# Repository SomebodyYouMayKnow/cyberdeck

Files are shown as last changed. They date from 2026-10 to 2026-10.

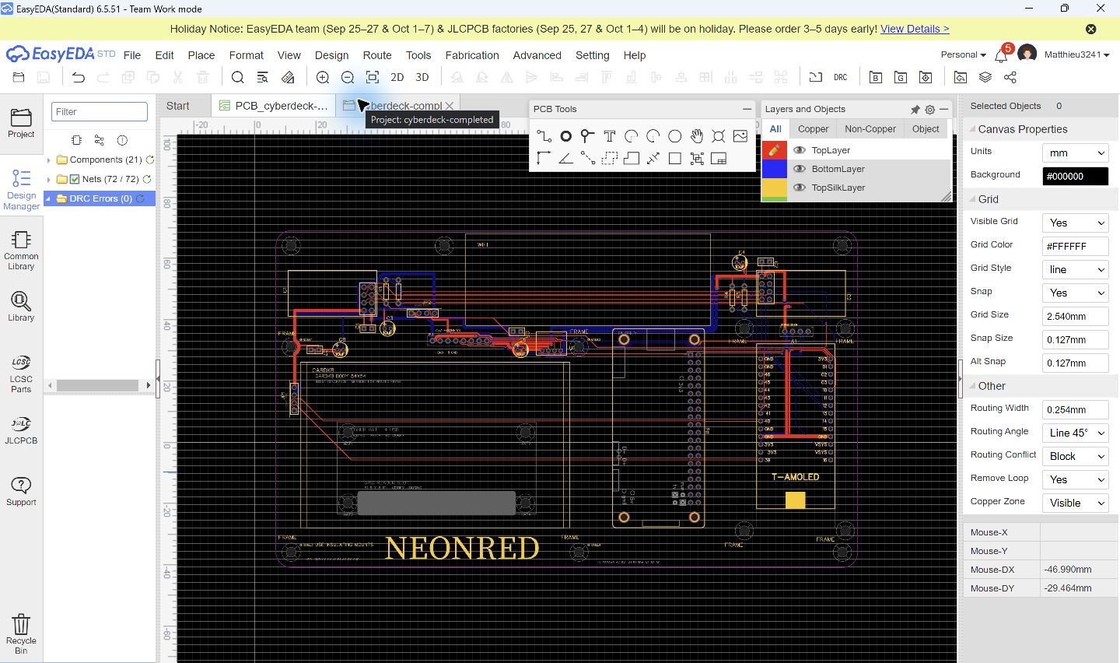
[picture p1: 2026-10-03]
PCB/screenshots/easyeda-current-routed-board-drc.jpg

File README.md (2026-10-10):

# NEONRED

NEONRED is a compact, modular cyberdeck built around a Raspberry Pi Zero 2 W and a LILYGO T-Display-S3 AMOLED. The Pi runs Linux and hosts USB peripherals through the Waveshare USB HUB HAT. The LILYGO board provides the ESP32-S3 control interface and its own AMOLED display. **The current design has no separate HDMI display.**

## Planned capabilities

- Portable Linux development and an on-device ESP32 control interface.
- CardKB keyboard, rotary encoder and navigation buttons.
- IR receive/transmit hardware and two nRF24L01+ modules for controlled lab experiments.
- Chameleon Ultra SE3 for testing owned RFID/NFC tags and lab cards.
- ALFA dual-band Wi-Fi adapter for authorized testing on owned or explicitly authorized networks.
- Proxmark3 RDV4 as a separately mounted USB instrument, with its own LF/HF antenna system; it is not a bare IC to solder onto the carrier PCB.
- RTL-SDR Blog V4 as a USB receive-only SDR. The radar-detector experiment needs external X/K/Ka downconverters because the V4 cannot tune directly to those radar frequencies.
- ESP32 firmware experiments: the project’s control UI, passive Flock You detection, and ESP32 Marauder are separate firmware modes. They cannot all run simultaneously on one ESP32, and support for this exact LILYGO board must be validated.
- A switchable 2.4 GHz external antenna for the ESP32, conditional on confirming the exact LILYGO revision has an antenna-feed option.

Radio work is for the user's own equipment and explicitly authorized environments. Keep Wi-Fi testing non-disruptive and do not interfere with or access other people's networks or devices.

## Design status

The EasyEDA files in `PCB/` are saved design-stage exports, not a fabrication release. The new radio additions need mechanical outlines, serviceable USB connections, antenna clearances, and a power/thermal check. The exact Proxmark3 model, RTL-SDR supply, LILYGO revision, and antenna-feed option are not yet verified. See [the current feature and integration plan](docs/NEONRED_FINAL_VERSION_2026-10-09.md).

Existing project files include source exports, wiring notes, screenshots, firmware scaffolding, and CAD/layout artifacts. Treat older HDMI-specific and superseded power documents as historical until reconciled with the live EasyEDA project.

## Useful files

- [Current goal and integration plan](docs/NEONRED_FINAL_VERSION_2026-10-09.md)
- [PCB source and screenshots](PCB/)
- [Firmware scaffold](Firmware/)
- [CAD files](cad/)
- [Current master BOM/status list](BOM.csv)
- [Earlier dated purchase list](BOM_NEONRED_purchase-list_2026-10-06.csv; historical until reconciled)
- [Detailed project notes](docs/PROJECT_SUMMARY.md)

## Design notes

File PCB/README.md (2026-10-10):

# PCB sources

The current project goal is documented in [NEONRED_FINAL_VERSION_2026-10-09.md](../docs/NEONRED_FINAL_VERSION_2026-10-09.md): **no separate HDMI display**, with proposed Proxmark3, RTL-SDR, ESP32 firmware modes and a conditional external ESP32 antenna. On 2026-10-09, the live EasyEDA Standard project `neonred` was opened and its current `Sheet_1` and `PCB_neonred` exported below. These are baseline snapshots only: the proposed Proxmark3/RTL-SDR/antenna expansion has not been laid out, and this is not a fabrication release. Older simple-power and port-revision sources are design history, not approval to fabricate.

- `neonred-live-schematic_2026-10-09.json` and `neonred-live-PCB_2026-10-09.json` — source exports from the live EasyEDA Standard project.
- `screenshots/easyeda-neonred-schematic-2026-10-09.png` and `screenshots/easyeda-neonred-pcb-2026-10-09.png` — matching visual exports.

- `pcb-simple-power-native.json` — saved EasyEDA PCB source
- `schematic-simple-power-native.json` — saved EasyEDA schematic source
- `wiring-map-simple-power.*` — connector and pin-assignment record
- `simple-power-native-drc.json` — saved DRC record; the corresponding EasyEDA screenshot shows 0 displayed DRC errors for that point-in-time revision
- `simple-power-mounting-template.pdf` — 1:1 mechanical-fit print template
- `screenshots/` — live project image exports plus earlier design-stage views and mounting-template preview

The source and screenshots document the design stage; they do not prove physical fit, assembly, or electrical operation. There is no final Gerber archive. Before fabrication, measure the real hardware, complete final DRC/ERC in the PCB tool, and add `production/gerbers.zip`.

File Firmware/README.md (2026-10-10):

# Cyberdeck firmware

This folder is an **untested pre-hardware bring-up scaffold**. The 2026-10-06 master-power / service-port redesign is documented in [POWER_AND_IO_REVISION_2026-10-06.md](../docs/POWER_AND_IO_REVISION_2026-10-06.md) but has not yet been applied to the EasyEDA schematic or PCB. Do not follow the earlier simple-power wiring notes as the new design.

- `esp32/` is a PlatformIO Arduino project for the LILYGO ESP32-S3 AMOLED board.
- `pi/` reads the ESP32 USB serial link and sends console commands back.
- `PROTOCOL.md` documents the line-based command protocol.

## Bring-up order

1. Confirm the actual hardware revisions and the carrier PCB against the saved wiring map.
2. Do not connect the proposed single-input power system until its source, protection, and PCB have been measured and verified. The currently listed Miady bank does not meet the revised one-input power requirement.
3. Flash `Firmware/esp32` with PlatformIO.
4. On the Pi, install `pyserial` and run `python3 cyberdeck_bridge.py --port /dev/ttyACM0`.
5. Send `STATUS` first. Verify I²C devices, radios and IR one subsystem at a time.

Do not operate direct SPI/IR/I²C signal connections when the related domain is unpowered. Begin radios at minimum power and measure the external regulator load and temperature before normal use.

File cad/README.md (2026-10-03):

# CAD sources

These files are copied from the active design folder for publication:

- `Cyberdeck_Enclosure.scad` is the editable parametric enclosure concept.
- `Cyberdeck_Fusion_Layout.dxf` is the millimetre placement sketch for Fusion.
- `Cyberdeck_layout.svg` is a visual layout reference.
- `MECHANICAL_VALIDATION.md` lists source dimensions and physical tests.

There is no final STEP assembly yet. Do not represent these sources as a fit-tested enclosure.

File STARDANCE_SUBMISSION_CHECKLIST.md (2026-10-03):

# Stardance funding and shipping checklist — Cyberdeck

**Status snapshot:** 2026-10-03. This separates the funding request from the physical build. Funding is requested from a complete design package before parts are bought. Shipping/Stardust comes after the physical device is assembled.

## Phase 1 — create the Stardance project and record work

- [ ] Create or sign in to a Stardance account. You must be eligible for the program and complete the account details yourself.
- [ ] Create a new **Hardware** project on Stardance and set its title, short description, and public GitHub source URL.
- [ ] Start Lapse before continuing design work, or create a Markdown build journal if Lapse is unavailable.
- [ ] Add design devlogs that explain your own decisions, revisions, problems, and next steps.
- [ ] Ask for feedback in `#stardance-help` or from other makers and record the feedback plus changes made.

## Phase 2 — funding-request design package

### Already done

- [x] Public GitHub repository: https://github.com/SomebodyYouMayKnow/cyberdeck
- [x] Commit and publish the core design package on GitHub.
- [x] Organize the repository into `cad/`, `PCB/`, `Firmware/`, `production/`, and `docs/`.
- [x] Publish a linked root `BOM.csv` and the BOM workbook.
- [x] Publish the current PCB source, schematic source, wiring map, DRC evidence, and 1:1 mounting template.
- [x] Publish editable OpenSCAD enclosure source, Fusion-importable DXF, layout SVG, and mechanical-validation document.
- [x] Publish untested starter firmware: ESP32 pin-map/I2C/radio/IR code, Pi serial bridge, and Chameleon BLE discovery scaffold.
- [x] Add a license and `.gitignore`.

### Still needed before clicking **Request funding**

- [ ] Finish the enclosure as a detailed, electronics-inclusive CAD assembly. It needs the case, lid, display, keyboard, Pi, USB HAT, ESP32, Chameleon, battery, carrier PCB, cables, screws/standoffs, antenna arms, and openings positioned in one assembly.
- [ ] Save the editable Fusion source file, such as `assembled-cyberdeck.f3d`.
- [ ] Export the full assembly as `assembled-cyberdeck.step`. Stardance says a funding submission without an electronics-inclusive STEP file will not be approved.
- [ ] Export the individual printable case parts as STEP/STL where relevant.
- [ ] Use accurate component envelopes or manufacturer STEP models in the CAD assembly. Mark dimensions that still need physical checking.
- [ ] Take screenshots/renders of the **digital** full CAD assembly. These are required for review; they are not photos of a completed physical build.
- [ ] Take a screenshot of the PCB layout and a schematic/wiring-diagram image from the current files.
- [ ] Write the final root `README.md` yourself. Stardance explicitly does not allow an AI-generated README.
- [ ] In your README, add: what the project is; why you are making it; subsystem explanation; CAD render; PCB screenshot; wiring diagram; how to reproduce it; and the BOM table.
- [ ] Confirm every BOM line has the correct quantity, price or clearly marked TBD status, and a purchase link.
- [ ] Keep the current firmware source in the repository. It may be untested for funding, but it must be present.
- [ ] Choose a funding tier in Stardance. The reviewer can move it up or down. Current published limits are B up to $25, A up to $120, S up to $200, and X up to $600 case-by-case.
- [ ] From the Stardance project page, click **Request funding** and submit the public repository link after the items above are present.

## Do **not** require these before funding

- [x] You do not need to buy the requested parts first.
- [x] You do not need to 3D-print the enclosure first.
- [x] You do not need to fabricate the PCB first.
- [x] You do not need physical build photos before requesting funding.
- [x] You do not need successful hardware tests before requesting funding. Firmware can be untested.

## Phase 3 — after funding and parts arrive

- [ ] Confirm exact part revisions and measure all physical modules, connectors, cable bends, and screw locations.
- [ ] Print the 1:1 template and check its 100 mm calibration line.
- [ ] Test-fit the Pi, HAT header slot, keyboard, ESP32, display, Chameleon, battery, cables, antennas, and all mounts before final fabrication.
- [ ] Correct the CAD and PCB from physical measurements; rerun final DRC/ERC.
- [ ] Export final Gerbers and drill files as `production/gerbers.zip` before ordering the carrier PCB.
- [ ] Print the case, assemble the carrier PCB, mount the modules, and add insulation/strain relief.
- [ ] Flash and test the ESP32/Pi firmware one subsystem at a time: keyboard, encoder, radios, IR, display, USB HAT, Wi-Fi, and Chameleon BLE discovery.
- [ ] Update the repository with the final CAD/STEP, Gerbers, firmware changes, wiring photos, and build notes.

## Phase 4 — ship the completed project for Stardust

- [ ] Add real photos or a video showing the completed cyberdeck and its working functions.
- [ ] Update the README with build photos, measured changes, and tested behavior.
- [ ] Ship the completed project from the Stardance project page. This sends it to review for Stardust, separate from the funding request.

## Current funding blockers

1. A Stardance account/project and work log need to be created by you.
2. The CAD is still a parametric concept; it needs a complete Fusion assembly and an electronics-inclusive STEP export.
3. The final README must be written by you and include digital renders/screenshots.
4. Feedback must be requested and documented.

Sources: [Stardance hardware shipping guide](https://stardance.hackclub.com/resources/shipping-hardware), [starting-hardware guide](https://stardance.hackclub.com/resources/starting-hardware), and [hardware funding tiers](https://stardance.hackclub.com/resources/tiers).

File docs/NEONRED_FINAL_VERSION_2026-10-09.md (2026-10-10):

# NEONRED — current goal and hardware expansion

Updated: 2026-10-09. This note is the current high-level target and supersedes the older HDMI-based project descriptions. On 2026-10-09, I opened the live EasyEDA Standard `neonred` project and exported its current schematic and PCB to `PCB/neonred-live-schematic_2026-10-09.json` and `PCB/neonred-live-PCB_2026-10-09.json`, with PNG views in `PCB/screenshots/`. The requested Proxmark3/RTL-SDR/antenna expansion has **not** been laid out; these are baseline exports, not an updated fabrication design.

## Final version description

NEONRED is a portable, modular cyberdeck and authorized electronics/security-learning workbench built around a Raspberry Pi Zero 2 W and a LILYGO T-Display-S3 AMOLED. The Pi runs Linux and connects to the Waveshare USB HUB HAT. The LILYGO board supplies the ESP32-S3 control interface and its integrated AMOLED screen. The current version has **no separate HDMI display**.

The device combines a CardKB keyboard, rotary encoder and navigation controls with IR receive/transmit hardware, two nRF24L01+ modules, the Chameleon Ultra SE3, and an ALFA USB Wi-Fi adapter. The proposed expansion adds a separately mounted Proxmark3 instrument and an RTL-SDR Blog V4 receiver, plus an external 2.4 GHz antenna for the ESP32 if the exact LILYGO board revision supports a switchable RF feed. Modules with USB or antenna connections remain replaceable serviceable devices; the carrier PCB provides mounting and correctly routed interfaces, rather than copying complete complex RF products onto the carrier.

Software modes under consideration are the NEONRED control firmware, passive Flock You detection, and ESP32 Marauder experimentation in an isolated, authorized lab. These are not simultaneous capabilities on one ESP32: each firmware image replaces the others unless a separate ESP32 is added and independently supported. The exact LILYGO display/board support for Marauder and Flock You requires a port and bench test before it can be claimed as working.

## What can physically go on the PCB

| Addition | Practical integration | Open issue |
|---|---|---|
| Proxmark3 | Mount a complete Proxmark3 RDV4 or other selected assembled unit as a removable USB module. Provide a retainer, accessible USB connection, and room for its LF/HF antenna loops. | “Proxmark3” has multiple hardware variants. Select the exact unit and measure it. Do not replace it with an unverified home-designed RF clone. Keep its loop antennas clear of metal and other coils. |
| RTL-SDR Blog V4 | Mount the intact USB-A dongle at the Pi USB hub; reserve a 50-ohm SMA feedthrough/pigtail and antenna clearance. Leave airflow around its metal enclosure. | The V4 is a receive-only USB dongle, 500 kHz–1.766 GHz, 250–270 mA typical, with USB-A male and SMA. It cannot directly receive X/K/Ka police-radar bands. The linked detector software describes external block downconverters; select and validate those separately. Its manufacturer has announced the V4 end of life, so confirm availability before listing it as a guaranteed purchase. |
| ESP32 external antenna | Reserve a mechanically accessible antenna connector and keepout only after confirming an RF feed point and selector on the exact owned LILYGO revision. If that board has no documented external-antenna option, use the onboard antenna or a different ESP32-S3 module with a factory u.FL/IPEX connector. | The ESP32-S3 is 2.4 GHz Wi-Fi/Bluetooth; it does not provide 5 GHz Wi-Fi. The vendor documentation for a different T-Display-S3 board describes moving an RF-selection resistor, but that must not be copied to the AMOLED board without its exact schematic and visual inspection. |
| Flock You | Treat as a separate, receive-only firmware experiment; the referenced project describes passive 2.4 GHz Wi-Fi frame detection. | Its published default target is a Seeed XIAO ESP32-S3. Porting the display/buttons and validating the exact LILYGO board is still required. |
| ESP32 Marauder | Treat as a separate firmware mode on a compatible ESP32 target, used only in an isolated lab on owned or explicitly authorized systems. | The current LILYGO T-Display-S3 AMOLED is not listed as a ready-made target in the upstream compatibility table. Display, buttons, flash layout and GPIO assignments must be ported and tested. It cannot run alongside NEONRED UI or Flock You on the same chip at the same time. |

The RTL-SDR V4’s SMA connector is an RF input, not a connector to solder directly to GPIO or a PCB antenna trace. The Proxmark device likewise has dedicated LF/HF antenna circuits; preserve the complete selected device and its correct antenna arrangement. Any coaxial feedthroughs should be 50-ohm RF connectors appropriate to the chosen device, and must be isolated from mounting metal where the antenna design requires it.

## Power and performance checks

The V4’s published typical current is 250–270 mA; the ALFA adapter, HAT, Proxmark and Pi add to the system load. The Raspberry Pi Zero 2 W is specified around a 5 V / 2.5 A supply recommendation. The Waveshare hub adds ports, not unlimited power. Bench-test the complete load from the selected source and hub before assuming one bank can run all modules. Keep the SDR’s software-controlled bias tee disabled unless the selected antenna accessory explicitly needs it. Do not connect independent USB VBUS outputs together or route unmeasured high-current device power through narrow carrier traces.

The linked radar detector project describes an SDR plus external downconverters to translate radar-frequency signals into the V4’s tunable range. This is a substantial, separate RF subsystem, not a firmware-only feature. The proposed use here is passive reception and alerts; no radar transmission or interference is part of this design.

## Authorized scope

- Linux development, programming, diagnostics, and hardware bring-up.
- IR learning/testing on the user's own remotes.
- NFC/RFID experiments using tags, cards and systems the user owns or has explicit permission to test.
- Wi-Fi, Bluetooth and nRF24 experiments on owned equipment or in an isolated authorized lab. No disrupting other people's networks or radio communications.
- Passive reception for the proposed SDR detector and passive Flock You experiment, subject to local law.
- Physical integration of serviceable off-the-shelf modules, custom PCB design, enclosure CAD, firmware and documentation.

## Required before changing/fabricating the PCB

1. Use the live EasyEDA exports as the starting baseline. After the mechanical and electrical choices below are verified, update the project and export a new schematic, PCB source, and screenshots to `PCB/`.
2. Confirm the exact LILYGO model/revision and inspect its manufacturer schematic for an external antenna selector/feed. Do not add a connector footprint based only on the standard T-Display-S3 instructions.
3. Choose the exact Proxmark3 hardware and RTL-SDR V4 (or an available equivalent); obtain their dimensions, mounting points, connector positions and antenna clearances.
4. Decide whether the Pi Zero 2 W has enough CPU and USB power headroom for one SDR, the ALFA adapter and the other peripherals. Test incrementally; the software's advertised support is not a performance guarantee for this deck.
5. Choose the radar-band downconverter set and antenna arrangement, then verify its output frequencies stay inside the selected SDR's tuning range.
6. Allocate separate, replaceable mounts and USB paths for the Proxmark and RTL-SDR. Avoid routing high-speed USB over long unshielded PCB traces; use short controlled connections or certified cables.
7. Update schematic, PCB footprints, board outline/keepouts, mounting template, current budget, BOM and screenshots together. Run ERC/DRC and check the physical assemblies before calling the PCB fabrication-ready.

## References

- [Proxmark3 RDV4 product/hardware overview](https://proxmark.com/proxmark-3-hardware/proxmark-3-rdv4/) and [Proxmark3 hardware description](https://github.com/Proxmark/proxmark3/wiki/Hardware-Description)
- [RTL-SDR Blog V4 datasheet](https://www.rtl-sdr.com/wp-content/uploads/2024/12/RTLSDR_V4_Datasheet_V_1_0.pdf) and [V4 end-of-life notice](https://www.rtl-sdr.com/rtl-sdr-blog-v4-end-of-line/)
- [Requested radar-detector project](https://github.com/rayhe/sdr-radar-detector)
- [LILYGO AMOLED series hardware and pinout sources](https://github.com/Xinyuan-LilyGO/LilyGo-AMOLED-Series)
- [ESP32 Marauder supported hardware](https://github.com/justcallmekoko/ESP32Marauder/wiki/supported-hardware) and [FAQ](https://github.com/justcallmekoko/ESP32Marauder/wiki/faq)
- [Flock You project](https://github.com/colonelpanichacks/flock-you)

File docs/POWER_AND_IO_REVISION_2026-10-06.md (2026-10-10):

# NEONRED power, controls, and service-port revision

Updated: 2026-10-06. This is the current requested architecture for the next schematic/PCB revision. It supersedes the earlier “separate USB power cables / peripheral-only switch” proposal in `PROJECT_SUMMARY.md`. This is an electrical design draft, not a fabrication release.

## Requested interfaces

- One latching master switch controls the complete deck power distribution.
- One external USB-C female port is the 5 V system-power input.
- One external USB-C female port carries native USB data for ESP32-S3 programming/control.
- One external micro-USB female port provides access to the Pi Zero 2 W OTG/data connector.
- Add two momentary through-hole controls: Back and Menu. Keep the rotary encoder for scrolling and its push contact for Select.
- Replace the Adafruit #5990 plug-in IR board with its receive/transmit functions on the carrier PCB; place the IR receiver and two emitters at the left wall aperture, on short leads only if needed for optical alignment.

## Power-path intent

`USB-C power input → 5 V-only sink/PD interface → input protection → master switch → protected branches`.

The switched 5 V branches are: Pi PWR IN, LILYGO 5 V/VBUS input, HDMI display (only if its exact revision uses 5 V), and the peripheral regulator input. The regulator supplies the nRF24 modules and IR transmit stage at 3.3 V. CardKB is supplied at 5 V through its existing level-shifter arrangement. Grounds are common. Do not connect independent USB VBUS sources together.

The input must negotiate or otherwise provide 5 V at the measured total load. If USB-PD is used, the sink must request a 5 V profile; do not feed a 9/12/15/20 V profile directly to the 5 V rails. Place a fuse/current-limiting stage immediately after the input. Size the fuse, switch, connector, copper, and each branch from measured peak currents and the weakest cable/connector; values are deliberately TBD until those measurements and exact module revisions are known. The source's maximum rating limits available current, while a fuse protects against faults. Never treat a wide trace as overcurrent protection.

The currently listed Miady two-pack bank is not suitable as the single source for this proposed architecture: its published output is up to 5 V/2.4 A, while Raspberry Pi recommends a 5 V/2.5 A supply for Zero-series boards, before the HDMI display, LILYGO, HAT peripherals, radios, and IR are counted. Use a higher-capacity source for one-input operation or retain electrically isolated separate sources; do not pretend the existing bank has enough headroom.

The master switch must interrupt the system 5 V after input protection and before every load branch. Its OFF position must also prevent the ESP32 programming cable or Pi service cable from back-powering system rails. The computer USB-C VBUS is therefore isolated from system 5 V; retain only a correctly isolated VBUS-detect path if the LILYGO native USB implementation requires it. Verify enumeration with the exact LILYGO revision before PCB release.

This is a hard power cut, not a graceful Pi shutdown. Until a proper shutdown controller is designed and tested, shut Linux down first and then use the master switch; cutting power during SD-card writes can corrupt the Pi boot card.

## USB service paths

- **ESP32 USB-C:** Use the LILYGO's native USB 2.0 D+/D− path, brought to a panel female connector. Keep the data pair together and short; ground the shield to chassis at the entry. The computer's VBUS must not become an alternate source for the switched 5 V bus.
- **Pi micro-USB:** Treat the requested panel jack as the Pi's OTG/data service connection. Pi power remains on the switched 5 V rail through the separate PWR IN connector. The Pi OTG port is already used by the Waveshare four-port USB HUB HAT, so add a break-before-make 2:1 USB 2.0 selector labelled `HAT / PC`. It must route only one upstream connection to the Pi at a time, prevent VBUS backfeed, and preserve the correct OTG host/device role. The external PC service mode may require Pi USB-gadget configuration. Do not wire the HAT and external computer in parallel.
- **Power USB-C:** This is the only system-power entry. It requires a correctly wired USB-C sink interface/CC termination (or a preassembled sink module) and input protection. A bare USB-C receptacle with only VBUS/GND wires is not a complete C-to-C sink.

## Controls and IR

Button assignments for the next firmware/hardware revision:

| Control | ESP32 pin | Wiring |
| --- | --- | --- |
| Back | GPIO43 | Normally-open switch to GND; internal pull-up |
| Menu | GPIO44 | Normally-open switch to GND; internal pull-up |
| Select | GPIO42 | Existing rotary encoder push contact to GND; internal pull-up |
| Navigate | Existing encoder A/B | Keep current assignments |

This gives the screen UI Back, Menu, Select, and rotary navigation. GPIO43/44 are also the LILYGO UART0 pins, so the native USB CDC connection is used for the programming/service port; do not use UART0 at the same time. The current firmware can report button events over USB serial; drawing a menu on the AMOLED still requires the exact display-driver initialization for the owned LILYGO revision.

The integrated IR block keeps `IR_RX` on GPIO39 and `IR_TX` on GPIO40. The receive sensor is a 38 kHz demodulating device. The transmit LEDs need a transistor/FET driver and current-limiting designed for the measured supply; do not drive them directly from a GPIO. The Adafruit #5990 board draws up to about 400 mA while transmitting from 5 V, so the carrier's 3.3 V regulator and switch must be sized from the actual implementation's pulse current. If reproducing Adafruit's circuit, retain the required attribution/share-alike notice in the project files.

## What is changed now vs. what still blocks fabrication

The firmware pin definitions and USB-serial button event handling are updated for Back/Menu, and the BOM now lists the required design items with unresolved ratings. The wiring map, PCB footprints, copper routes, port selector schematic, and IR discrete circuit are **not yet changed or verified**. They must be updated together in EasyEDA after identifying exact connector modules and measuring the complete 5 V load. This avoids silently treating a planning block diagram as a wired, current-rated PCB.

Before releasing fabrication files, verify: exact LILYGO USB-C/VBUS behavior; Pi OTG and HAT upstream wiring/role; the selected 2:1 selector's VBUS/ID behavior; USB-C sink module output; measured peak current for Pi, hub devices, display, ESP32, radios and IR; switch/fuse/copper ratings; connector pinouts; and physical fit of the three panel ports and the added buttons.

## References

- [Raspberry Pi Zero 2 W product page](https://www.raspberrypi.com/products/raspberry-pi-zero-2-w/) — distinguishes the OTG micro-USB port from the separate power input.
- [Raspberry Pi power guidance](https://www.raspberrypi.com/documentation/computers/getting-started.html) — recommends 5 V / 2.5 A for Pi Zero boards.
- [Raspberry Pi USB gadget-mode guide](https://www.raspberrypi.com/news/usb-gadget-mode-ssh-over-usb/) — gadget connection uses the Zero's OTG port, not PWR IN.
- [Waveshare USB HUB HAT](https://www.waveshare.com/wiki/USB_HUB_HAT) — HAT uses the Pi Zero USB connection for its upstream data link.
- [Adafruit #5990 open hardware source](https://github.com/adafruit/Adafruit-Infrared-IR-Remote-Transceiver) — reference design, operating notes, and license.
- [Miady 2-pack listing specification](https://www.newegg.com/p/359-04A3-00191) — lists the bank's maximum output as 5 V / 2.4 A.

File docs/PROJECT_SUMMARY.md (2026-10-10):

# Cyberdeck project summary

Updated: **2026-10-09** (America/Los_Angeles). The current goal is recorded in [NEONRED_FINAL_VERSION_2026-10-09.md](NEONRED_FINAL_VERSION_2026-10-09.md). It supersedes the older HDMI-based description below: the current version has **no separate HDMI display**, and proposes a removable Proxmark3 instrument, one RTL-SDR Blog V4 with external radar-band downconverters, passive Flock You experimentation, a separately flashed ESP32 Marauder mode, and an external ESP32 antenna only if the exact LILYGO revision supports it. These additions are not yet reflected in the saved EasyEDA project or verified on hardware. Sections below preserve prior design history; where they conflict with the new goal, treat them as historical rather than fabrication instructions. The live EasyEDA editor was not available in the computer session, so no new EasyEDA screenshot, schematic, PCB, or DRC claim is made.

The earlier revision's specific power arrangement below is historical and is **not the current requested design**. Retain its electrical notes only as record of the previous revision.

## Final project vision and inspiration

**NEONRED** is intended to become a compact, repairable clamshell cyberdeck: a portable Linux computer and electronics workbench that the user designs, builds, programs, and documents from the carrier PCB through the finished 3D-printed case. The Raspberry Pi Zero 2 W is the main Linux computer and drives the HDMI display. The LILYGO ESP32-S3 AMOLED is the always-available control interface for the CardKB keyboard, rotary encoder, IR hardware, and low-power radio modules. A separately mounted Waveshare USB HUB HAT expands the Pi, while the Chameleon Ultra SE3, ALFA dual-band Wi-Fi adapter, display, battery bank, and folding-antenna arrangement make the finished unit self-contained.

The intended final form is a laptop-like case: keyboard in the base; Pi, HAT, Chameleon, and protected wiring below it; an HDMI display in the lid; and a lid window that exposes the base-mounted LILYGO display when the deck is closed. It should be maintainable, with screws, standoffs, service access, cable routing, and replaceable modules rather than permanently buried parts.

### Intended, authorized uses

- Linux development, portable programming, diagnostics, and display/keyboard experimentation.
- ESP32 firmware development; I2C keyboard and encoder control; IR learning and replay for the user's own remotes.
- NFC/RFID work with the user's own tags, cards, and lab equipment through the Chameleon.
- Wi-Fi, Bluetooth, and nRF24 experimentation limited to the user's own equipment, networks, or an authorized test environment; the project must not interfere with other people's radio communications or networks.
- Learning the complete hardware-development cycle: circuit and PCB design, enclosure CAD, 3D printing, embedded firmware, Linux integration, wiring, physical assembly, debugging, and documentation.

### Recovered inspiration record

The earlier wiring chat records that the user shared **two Instagram cyberdeck projects** as visual inspiration, along with a Reddit cyberdeck/radio-project reference. The recovered Instagram references are [post DSUnpaNAXFA](https://www.instagram.com/p/DSUnpaNAXFA/) and [post Dcdjywps34d](https://www.instagram.com/p/Dcdjywps34d/). The design direction recovered from that discussion is a compact, feature-dense, hands-on cyberdeck with a keyboard, multiple displays, portable power, radio hardware, IR capability, visible electronics, and a repairable custom enclosure. The external sources are inspiration and historical research only; they are not approved wiring, firmware, or test procedures.

## Mechanical enclosure revision 1 (2026-10-03)

An editable mechanical enclosure design now exists at [Cyberdeck_Enclosure.scad](C:/Users/matth/Documents/Codex/2026-09-29/cyberdeck-electrical-engineering/cad/Cyberdeck_Enclosure.scad), with a companion [layout drawing](C:/Users/matth/Documents/Codex/2026-09-29/cyberdeck-electrical-engineering/cad/Cyberdeck_layout.svg) and [physical validation checklist](C:/Users/matth/Documents/Codex/2026-09-29/cyberdeck-electrical-engineering/cad/MECHANICAL_VALIDATION.md). It models a removable service tray, 42 mm base, lid/display cavity, keyboard frame, ESP32 cradle, Pi/HAT support posts, an under-tray Chameleon sled, cable guides, IR/encoder/switch openings, battery hooks and generic antenna pivots.

The HAT's published 65 x 30 mm footprint, 58 x 23 mm hole pattern and the saved 51.8 x 8 mm PCB header slot are incorporated. The Chameleon cannot fit beside the HAT under the CardKB at the same height, so the current model gives it a separate under-tray bay. Mated plug dimensions, real cable bend radii, actual Chameleon dimensions and RFID performance inside the case are unverified. Print the existing 1:1 mounting template and complete the validation checklist before manufacturing either the case or PCB.

The current saved EasyEDA schematic and PCB contain **21 components, 132 electrical pins, 17 functional nets, 77 connected pins and 55 intentional NC pins**. Native exports agree pin-for-pin, all 17 functional nets pass geometric continuity checks, and EasyEDA reports **0 DRC errors**. Its **72/72** native net counter includes the 55 isolated NC pad nets. These checks do not establish actual load capacity, temperature, RF performance or assembled fit.

The carrier remains **190 × 110 mm with R5 corners**. Keyboard/frame guides, the case-mounted I2C encoder connection, HAT cutout and module mounting positions remain. The two obsolete LM73100 support holes are removed. Fingerprint reader, extra microSD and custom USB expansion remain removed. The Pi's native boot-card slot is unchanged. User-added NEONRED lettering is preserved.

## Current files

- [schematic-simple-power-native.json](C:/Users/matth/Documents/Codex/2026-09-29/cyberdeck-electrical-engineering/outputs/schematic-simple-power-native.json) and [pcb-simple-power-native.json](C:/Users/matth/Documents/Codex/2026-09-29/cyberdeck-electrical-engineering/outputs/pcb-simple-power-native.json) are the current saved native authority.
- [wiring-map-simple-power.json](C:/Users/matth/Documents/Codex/2026-09-29/cyberdeck-electrical-engineering/outputs/wiring-map-simple-power.json) and [wiring-map-simple-power.txt](C:/Users/matth/Documents/Codex/2026-09-29/cyberdeck-electrical-engineering/outputs/wiring-map-simple-power.txt) contain every current pin.
- [cyberdeck-bom-updated.xlsx](C:/Users/matth/Documents/Codex/2026-09-29/cyberdeck-electrical-engineering/outputs/cyberdeck-bom-updated.xlsx) and [live Google Sheet](https://docs.google.com/spreadsheets/d/16lRwI5R3pBksWb1bjXYjF_alQrG_2C0rFS-AZ5qpXIg/edit).
- [simple-power-native-verification.json](C:/Users/matth/Documents/Codex/2026-09-29/cyberdeck-electrical-engineering/outputs/simple-power-native-verification.json), [simple-power-routing-audit-native.json](C:/Users/matth/Documents/Codex/2026-09-29/cyberdeck-electrical-engineering/outputs/simple-power-routing-audit-native.json) and [simple-power-native-drc.json](C:/Users/matth/Documents/Codex/2026-09-29/cyberdeck-electrical-engineering/outputs/simple-power-native-drc.json) record verification.
- [simple-power-mounting-template.pdf](C:/Users/matth/Documents/Codex/2026-09-29/cyberdeck-electrical-engineering/outputs/simple-power-mounting-template.pdf) is the current 1:1 mounting template; print at actual size and check its 100 mm calibration before use. [simple-power-mounting-template-audit.json](C:/Users/matth/Documents/Codex/2026-09-29/cyberdeck-electrical-engineering/outputs/simple-power-mounting-template-audit.json) binds it to the saved PCB.

Older power-controls files describe the rejected distributor and are historical. Do not manufacture them or use their pinout for this revision.

## Historical: previous simple power arrangement (superseded 2026-10-06)

- Power the LILYGO through its own intact USB-C cable and the Pi through its own PWR IN connection. The Pi supplies its separately mounted Waveshare HAT through a proper USB host/data cable. Do not independently feed HAT 5 V as well.
- Power the HDMI display externally; confirm its exact 5 V connection against the actual display. The selected older HDMI/SPI-touch module must not be assumed to have a USB power socket. Chameleon can receive power through its normal USB connection; do not connect a second power feed simultaneously.
- One external regulated USB 5 V source supplies CardKB and the input of an assembled **Pololu D24V10F3 #2830**. The regulator's 3.3 V output supplies the radios and IR through JP2. The regulator is wired externally, insulated and mechanically secured.
- **JP2: 1 = +5V_EXT, 2 = GND, 3 = 3V3_AUX, 4 = GND.** ESP3V3 is a separate rail. All grounds are common; never join either regulator output to the other. LILYGO VSYS stays NC.
- The inline USB on/off switch affects the peripheral supply only. It is not a deck-wide power switch or a Pi shutdown button. Halt Linux before removing Pi power.

A USB bank's current rating is its maximum available output, not current forced through the board. Actual load and faults determine current. Individual main-device cables keep their combined load off the carrier, but a bank's total rating still applies across its ports. The recorded Miady AS-TPB21 bank rating is 5 V / 2.4 A total; confirm the physical label. No claim is made that all devices fit one bank's budget.

The LILYGO RT9080 regulator's 600 mA rating includes its own ESP32/display load, so high-current radio/IR peripherals are not assigned to it. The external Pololu's nominal 1 A output is also conditional on operating conditions. Measure actual radio/IR peak demand, voltage drop and temperature before fabrication approval. Wider peripheral traces reduce drop; they are not a current limiter or proof against shorts.

**Power-state convention:** direct SPI/IR connections and the BSS138 I2C module do not provide complete power-off isolation. Use the connected system with both ESP and peripheral supplies present. Disconnect affected signal harnesses before operating/programming one domain alone. Do not leave an unpowered module driven through its GPIO protection paths. This is an operating constraint of the intentionally simplified circuit.

## Through-hole assembly and keyboard interface

There are no loose SMD parts to solder on the carrier. R1–R4 are axial 10 kΩ resistors. C1/C2/C5/C7 are 100 nF through-hole ceramic capacitors; C3/C4/C6/C8 are 10 µF through-hole electrolytics. Electrolytic pad 1 is positive and pad 2 is GND. Check real lead pitch and body clearance against the selected footprints.

The preassembled **Adafruit #757 BSS138 level-shifter module** replaces Q1/Q2 and R5–R8. Only through-hole headers and a harness need soldering. It has built-in pullups. Its physical mounting footprint is not guessed on the carrier: JP3 is a generic 1×8, 2.54 mm harness connector.

| JP3 pin | Net | Connection on assembled #757 |
|---|---|---|
| 1 | GND | GND |
| 2 | ESP3V3 | LV |
| 3 | +5V_EXT | HV |
| 4 | SDA_LV | A1 |
| 5 | KB_SDA | B1 |
| 6 | SCL_LV | A2 |
| 7 | KB_SCL | B2 |
| 8 | GND | Other GND |

Adafruit channel names A1/A2 here are not LILYGO reference A1. Leave unused level-shifter channels unconnected. CardKB still receives regulated 5 V. Start I2C at 100 kHz and check pullups/rise time with the actual module and cables.

**JP8 encoder:** 1 GND, 2 ESP3V3, 3 SDA_LV, 4 SCL_LV. The case-mounted Adafruit5880 module is assembled; default address 0x36 differs from CardKB's 0x5F. Its shaft/panel/knob fit remains to measure.

Removed: LM73100 carrier distributor, carrier fuse, power-output pigtail pads, bare translator ICs, added 0603 resistors/capacitors and AUX_OE_N. GPIO2 is NC again. The external regulator is retained only for peripheral power.

## Firmware pins

| Function | ESP32 GPIO |
|---|---|
| Shared radio SCK / MOSI / MISO | 12 / 11 / 13 |
| Radio1 CSN / CE | 10 / 14 |
| Radio2 CSN / CE | 15 / 16 |
| CardKB and encoder SDA / SCL | 1 / 41 |
| IR receive / transmit | 39 / 40 |
| Externally unused GPIO | 2, 3, 42, 43, 44, 45, 46 |

Set both radio CSN pins HIGH, both CE pins LOW and IR transmit LOW before using the peripherals. The wiring supports two independently configured nRF24L01+ radios: shared SPI SCK/MOSI/MISO (GPIO 12/11/13), with separate CSN/CE pairs (Radio 1 GPIO 10/14; Radio 2 GPIO 15/16). Firmware must serialize SPI transactions and select one radio at a time to configure it and load its TX FIFO. To transmit concurrently, configure each radio to a different RF channel, preload both TX FIFOs, then assert both CE pins nearly together; the radios transmit autonomously after that, so SPI can be reused. A single GPIO write cannot drive both CE pins because they are separate ESP32 outputs, though their start times can be kept very close. This is a firmware operation; no extra connection between the radios is needed. Start with well-separated channels within the locally permitted 2.4 GHz band (for example RF_CH 5 and 75), use compatible air data rates/packet settings at each receiver, and test for mutual desensitization/interference with the actual antennas and transmit power. Simultaneous operation is not yet hardware-tested. No translator-enable GPIO is required. Firmware, CardKB-to-Pi forwarding, encoder actions, HDMI/touch and Linux setup still require integration.

## Enclosure concept approved for documentation

The enclosure opens like a small laptop. In the open working position, the keyboard is nearest the user and the hinge is at the rear. Closing the lid covers the keyboard and main display while leaving the smaller LILYGO screen visible through a dedicated window.

User enclosure concept with folding side antennas

The picture establishes the basic arrangement. The latest user correction takes precedence: keep the Pi between keyboard and ESP32, but mount the HAT separately under the keyboard beside the Pi, using screws and a micro-USB data link. Chameleon and loose wiring also remain planned under the keyboard; fit these together rather than assuming each has the whole space. Carrier-mounted components must still stay outside the keyboard footprint. The center Wi-Fi antenna was requested in text. Retainers, isolation, access panels, cable channels and the complete enclosure remain unmodeled and unvalidated.

### Lid and displays

- Mount the selected Waveshare 3.5-inch HDMI screen inside the lid, mainly on the left and center. Its display faces inward toward the user when the case is open.
- Recess its rear controller, brackets, and wiring into the lid. Leave clearance so closing the case does not press on the CardKB keys or either screen.
- Put a rectangular viewing opening on the right of the lid. Align it to the base-mounted LILYGO AMOLED in the fully closed position, accounting for the hinge motion and lid thickness.
- The LILYGO remains fixed in the base; opening the lid moves the window away and exposes the small screen directly.
- A clear protective insert over the window is an option. Its material, opening dimensions, and screen clearance remain to be selected.

### Base surface and service access

- Place the CardKB keyboard across the left and center of the base.
- Place the LILYGO on the right, long axis front to back and screen upward. Keep the Pi parallel to it between keyboard and LILYGO, on its own standoffs. The retained HAT has four matching carrier mounts under the keyboard beside the Pi. Select spacer height and confirm connector orientation with the keyboard, Chameleon, carrier and cables assembled.
- Use a removable top mounting panel, with independent supports for the keyboard and LILYGO. Keep the LILYGO USB connection and buttons accessible.
- Put the custom carrier PCB below the keyboard on insulated mounting spacers. Provide a removable bottom cover for access to wiring, screws, connectors, and replacement parts.
- Determine base depth from the actual separate Pi and HAT mounting heights, keyboard, Chameleon, headers, connectors, carrier and spacers. The old stacked Pi/HAT assumption no longer determines the case depth; no final case height is established.

### Internal organization

| Area | Proposed contents and access |
|---|---|
| Below the keyboard | Separately screwed HAT beside the Pi, Chameleon SE3 Ultra and extra wiring, above a carrier area free of carrier-mounted components. Their combined footprint, connector access, insulation and vertical clearances must be measured. |
| Between keyboard and ESP32 | Raspberry Pi Zero 2, long axis front to back and parallel to ESP32, on its four existing supports. The HAT mounts separately under the keyboard at X20–85/Y62.5–92.5. Its body is 25 mm from the Pi body guide; this does not prove clearance for mated plugs and cable bends. |
| Rear left and rear right | The two external 2.4 GHz radio modules, near their corresponding case-mounted antenna connections. |
| Rear center | ALFA Wi-Fi adapter planning bay, X62–142/Y1–31 mm (80 × 30 mm); adapter, USB/pigtail and antenna fit remain unverified. |
| Near the peripheral cable entry | JP2 receives external regulated 5 V and 3.3 V. The assembled regulator and inline USB switch are wired externally and insulated. Main-device USB power bypasses the carrier. |
| Chameleon access | Removable cradle below the keyboard; maintain USB/service access and test RFID/NFC operation in the proposed stack. |
| Left case side | IR receiver/emitter on a separate, wired module, with its optical faces through the case side. JP1 is only the carrier cable header. |
| Around the perimeter | Secured USB, power, and signal cables, kept clear of mounting screws, panel edges, and moving parts. |

### Three folding antennas

- **Left and right pair:** One articulated antenna near each rear side corner. When stored, they fold forward along the sides, parallel to the closed box. When deployed, they swing outward away from the enclosure.
- These side antennas correspond to the two nRF24L01+ PA/LNA modules. The user called them the Bluetooth antennas; electrically they are **2.4 GHz radio antennas**. The nRF24 modules use Enhanced ShockBurst. Bluetooth LE functions use the ESP32-S3/Pi Bluetooth hardware; Classic Bluetooth support depends on the confirmed Pi hardware/software. These are not interchangeable antenna connections.
- **Center antenna:** A single dual-band 2.4/5 GHz Wi-Fi antenna at the rear center, connected to the ALFA AWUS036ACS. It should fold for storage and raise for use. Its joint and complete movement must clear the hinge and the lid in every position.
- Secure the antenna connectors to the enclosure so antenna movement does not load the PCB directly. Select matching connectors/pigtails after identifying the actual radio modules and antenna fittings. The ALFA has one RP-SMA female antenna connector.
- Keep the side antenna movement clear of the user's hands, lid, battery, hooks, and cables. The three antenna locations describe the mechanical concept; RF performance and coexistence have not been measured.

### Battery and hinge wiring

- Hold the external power bank with hooks/clips on the left side, toward the lower/front area, leaving the left rear antenna pivot and folding path clear.
- Main devices use individual external power cables. Budget each power bank separately, provide access to its ports, and never parallel their 5 V outputs.
- Check that the mounted battery's weight does not make the unit unstable while typing or opening the lid.
- Run HDMI and display-power cables through a protected channel beside the hinge, with a controlled flex loop and strain relief. Select the actual cable and connector arrangement before fixing hinge geometry.
- Use secured cable paths so closing the lid cannot pinch wires. Verify the full opening/closing movement with the battery and all antennas installed.

## Mounts and physical constraints

| Part | Recorded size / allowance |
|---|---|
| LILYGO T-Display-S3 AMOLED, original/basic | 1.91-inch display; visible area 44.22 × 19.8 mm. Manufacturer module figure 60 × 25.5 × 10 mm before added headers. Confirm the owned revision. |
| CardKB v1.1 | Drawing 84 × 54 mm; catalog 88 × 54 × 5 mm. Reserve 88 × 54 × 6.3 mm plus its cable, and measure the actual board. |
| Raspberry Pi Zero 2 | Nominal 65 × 30 mm; cable and spacer envelopes are additional. |
| Waveshare USB HUB HAT SKU12694 | 65 × 30 mm, four USB ports, no Ethernet. |
| Waveshare HDMI LCD SKU12824 | 3.5-inch, 480 × 320; nominal module outline 85.01 × 56.41 mm. Complete plug depth and independent power connection need confirmation. |
| ALFA AWUS036ACS | Manufacturer nominal 55 × 25 × 10 mm; reserve 80 × 30 mm for planning, with plugged-in fit still unverified. |

The 84 × 54 mm CardKB body guide is X10–94/Y43–97; the larger 88 × 54 mm reserve remains X8–96/Y43–97. No carrier-mounted resistors, capacitors or other components belong beneath it. Four Ø3.2 mm printed-frame mounts are at (5,38), (99,38), (5,105), (99,105) mm. The keyboard's direct screw locations are unknown; do not use these as CardKB drill coordinates.

The owned Waveshare USB HUB HAT SKU12694 is the 65 × 30 mm, four-USB model without Ethernet. It is screwed separately under the keyboard, beside the Pi, not stacked on the Pi. HAT mounts are (23.5,66), (81.5,66), (23.5,89), (81.5,89) mm, Ø3.2 on a 58 × 23 mm pattern. The rounded header cutout is 51.8 × 8 mm R1 at X26.6–78.4/Y85–93. This remains a planning clearance envelope: measure the actual underside housing and plugged-in USB cable before manufacture. HAT3/HAT4 supports, screw heads and washers must be ≤5.5 mm outside diameter.

The four Pi Ø2.75 mm mounting holes remain at (113.698,35.579), (136.698,35.579), (113.698,93.579), (136.698,93.579) mm. Pi body guide is X110–140/Y32–97. All 40 carrier Pi contacts are electrically NC. The LILYGO remains screen-up on the right with front USB access; its four frame holes are (153,32), (186,32), (153,98), (186,98) mm, Ø3.2. These are cradle/frame supports, not claimed direct LILYGO holes.

The rear-center ALFA bay X62–142/Y1–31 (80 × 30 mm) stays reserved. IR remains the only connector/module function at the left side, with the actual optical module wired to the case wall. The total carrier mount count is 20, including the four non-plated Pi mounting pads. Insulating spacers/washers are required on both faces at metal-fastener contact areas; electrical DRC does not validate screw-head contact with copper.

Keyboard, HAT, Chameleon, cable bends, USB plugs and spacers must be checked together. The slot alone does not establish flush HAT mounting or enough keyboard height. The clamshell, frame, hinge, window and antenna pivots remain mechanical design work.

## BOM and readiness

The current BOM preserves the user's ELEGOO kit status as Optional and avoids double-counting included parts. Totals below include priced rows only, excluding TBD parts, fabrication, shipping/tax and enclosure work. Main power cables stay intact; only the separate peripheral supply uses a verified USB 5 V wire connection.

Selected: $188.59 | If needed: $30.27 | Combined: $218.86 | Optional: $69.48

Before ordering: verify actual regulator/radio/IR loads and power sequencing, capacitor/connector lead dimensions, module orientations, insulated mounting and the full keyboard/HAT/Chameleon stack. Native DRC0 is not certification against wiring errors, shorts or overheating. No new Gerbers are approved by these checks.

## Sources for electrical choices

- [LILYGO schematic](https://github.com/Xinyuan-LilyGO/T-Display-S3-AMOLED/blob/main/schematic/T-DISPLAY-S3-AMOLED.pdf), [RT9080 datasheet](https://www.richtek.com/assets/product_file/RT9080/DS9080-09.pdf).
- [Pololu D24V10F3](https://www.pololu.com/product/2830), [Adafruit757](https://www.adafruit.com/product/757), [Adafruit IR guide](https://learn.adafruit.com/adafruit-infrared-ir-remote-transceiver?view=all).

## Current simplified complete electrical pin appendix

Native-export verified. GPIO names and carrier pad numbers are distinct. NC means no external carrier connection. Four mechanical Pi pads are excluded.

| Reference | Part | Pin | Pin name | Net |
|---|---|---|---|---|
| A1 | ESP32-S3-AMOLED-1.91 | 1 | 3V3 | ESP3V3 |
| A1 | ESP32-S3-AMOLED-1.91 | 2 | 01 | SDA_LV |
| A1 | ESP32-S3-AMOLED-1.91 | 3 | 02 | NC |
| A1 | ESP32-S3-AMOLED-1.91 | 4 | 03 | NC |
| A1 | ESP32-S3-AMOLED-1.91 | 5 | 10 | RADIO1_CSN |
| A1 | ESP32-S3-AMOLED-1.91 | 6 | 11 | RADIO_MOSI |
| A1 | ESP32-S3-AMOLED-1.91 | 7 | 12 | RADIO_SCK |
| A1 | ESP32-S3-AMOLED-1.91 | 8 | 13 | RADIO_MISO |
| A1 | ESP32-S3-AMOLED-1.91 | 9 | 14 | RADIO1_CE |
| A1 | ESP32-S3-AMOLED-1.91 | 10 | 15 | RADIO2_CSN |
| A1 | ESP32-S3-AMOLED-1.91 | 11 | GND | GND |
| A1 | ESP32-S3-AMOLED-1.91 | 12 | VSYS | NC |
| A1 | ESP32-S3-AMOLED-1.91 | 13 | VSYS | NC |
| A1 | ESP32-S3-AMOLED-1.91 | 14 | 16 | RADIO2_CE |
| A1 | ESP32-S3-AMOLED-1.91 | 15 | 39 | IR_RX |
| A1 | ESP32-S3-AMOLED-1.91 | 16 | 3V3 | NC |
| A1 | ESP32-S3-AMOLED-1.91 | 17 | 3V3 | ESP3V3 |
| A1 | ESP32-S3-AMOLED-1.91 | 18 | GND | GND |
| A1 | ESP32-S3-AMOLED-1.91 | 19 | GND | NC |
| A1 | ESP32-S3-AMOLED-1.91 | 20 | 40 | IR_TX |
| A1 | ESP32-S3-AMOLED-1.91 | 21 | 41 | SCL_LV |
| A1 | ESP32-S3-AMOLED-1.91 | 22 | 42 | NC |
| A1 | ESP32-S3-AMOLED-1.91 | 23 | 43 | NC |
| A1 | ESP32-S3-AMOLED-1.91 | 24 | 44 | NC |
| A1 | ESP32-S3-AMOLED-1.91 | 25 | 45 | NC |
| A1 | ESP32-S3-AMOLED-1.91 | 26 | 46 | NC |
| A1 | ESP32-S3-AMOLED-1.91 | 27 | GND | NC |
| A1 | ESP32-S3-AMOLED-1.91 | 28 | GND | NC |
| C1 | 100nF | 1 | 1 | 3V3_AUX |
| C1 | 100nF | 2 | 2 | GND |
| C2 | 100nF | 1 | 1 | 3V3_AUX |
| C2 | 100nF | 2 | 2 | GND |
| C3 | 10uF | 1 | 1 | 3V3_AUX |
| C3 | 10uF | 2 | 2 | GND |
| C4 | 10uF | 1 | 1 | 3V3_AUX |
| C4 | 10uF | 2 | 2 | GND |
| C5 | 100nF | 1 | 1 | +5V_EXT |
| C5 | 100nF | 2 | 2 | GND |
| C6 | 10uF | 1 | 1 | +5V_EXT |
| C6 | 10uF | 2 | 2 | GND |
| C7 | 100nF | 1 | 1 | 3V3_AUX |
| C7 | 100nF | 2 | 2 | GND |
| C8 | 10uF | 1 | 1 | 3V3_AUX |
| C8 | 10uF | 2 | 2 | GND |
| IC1 | NRF24L01 | 1 | GND | GND |
| IC1 | NRF24L01 | 2 | VCC | 3V3_AUX |
| IC1 | NRF24L01 | 3 | CE | RADIO1_CE |
| IC1 | NRF24L01 | 4 | CSN | RADIO1_CSN |
| IC1 | NRF24L01 | 5 | SCK | RADIO_SCK |
| IC1 | NRF24L01 | 6 | MOSI | RADIO_MOSI |
| IC1 | NRF24L01 | 7 | MISO | RADIO_MISO |
| IC1 | NRF24L01 | 8 | IRQ | NC |
| IC2 | NRF24L01 | 1 | GND | GND |
| IC2 | NRF24L01 | 2 | VCC | 3V3_AUX |
| IC2 | NRF24L01 | 3 | CE | RADIO2_CE |
| IC2 | NRF24L01 | 4 | CSN | RADIO2_CSN |
| IC2 | NRF24L01 | 5 | SCK | RADIO_SCK |
| IC2 | NRF24L01 | 6 | MOSI | RADIO_MOSI |
| IC2 | NRF24L01 | 7 | MISO | RADIO_MISO |
| IC2 | NRF24L01 | 8 | IRQ | NC |
| JP1 | Adafruit 5990 IR RX/TX module | 1 | IRout | IR_TX |
| JP1 | Adafruit 5990 IR RX/TX module | 2 | IRin | IR_RX |
| JP1 | Adafruit 5990 IR RX/TX module | 3 | GND | GND |
| JP1 | Adafruit 5990 IR RX/TX module | 4 | VIN | 3V3_AUX |
| JP2 | REGULATED POWER INPUT | 1 | +5V_EXT | +5V_EXT |
| JP2 | REGULATED POWER INPUT | 2 | GND | GND |
| JP2 | REGULATED POWER INPUT | 3 | 3V3_AUX | 3V3_AUX |
| JP2 | REGULATED POWER INPUT | 4 | GND | GND |
| JP3 | WIRED ADAFRUIT 757 I2C SHIFTER | 1 | GND | GND |
| JP3 | WIRED ADAFRUIT 757 I2C SHIFTER | 2 | LV | ESP3V3 |
| JP3 | WIRED ADAFRUIT 757 I2C SHIFTER | 3 | HV | +5V_EXT |
| JP3 | WIRED ADAFRUIT 757 I2C SHIFTER | 4 | A1 SDA | SDA_LV |
| JP3 | WIRED ADAFRUIT 757 I2C SHIFTER | 5 | B1 SDA | KB_SDA |
| JP3 | WIRED ADAFRUIT 757 I2C SHIFTER | 6 | A2 SCL | SCL_LV |
| JP3 | WIRED ADAFRUIT 757 I2C SHIFTER | 7 | B2 SCL | KB_SCL |
| JP3 | WIRED ADAFRUIT 757 I2C SHIFTER | 8 | GND | GND |
| JP8 | WIRED ADAFRUIT 5880 ENCODER | 1 | GND | GND |
| JP8 | WIRED ADAFRUIT 5880 ENCODER | 2 | 3V3 | ESP3V3 |
| JP8 | WIRED ADAFRUIT 5880 ENCODER | 3 | SDA | SDA_LV |
| JP8 | WIRED ADAFRUIT 5880 ENCODER | 4 | SCL | SCL_LV |
| PI1 | Raspberry Pi Zero 2 W | 1 | 3V3 | NC |
| PI1 | Raspberry Pi Zero 2 W | 2 | 5V | NC |
| PI1 | Raspberry Pi Zero 2 W | 3 | GPIO2 sda | NC |
| PI1 | Raspberry Pi Zero 2 W | 4 | 5V | NC |
| PI1 | Raspberry Pi Zero 2 W | 5 | GPIO3 scl | NC |
| PI1 | Raspberry Pi Zero 2 W | 6 | GND | NC |
| PI1 | Raspberry Pi Zero 2 W | 7 | GPIO4 | NC |
| PI1 | Raspberry Pi Zero 2 W | 8 | tx GPIO14 | NC |
| PI1 | Raspberry Pi Zero 2 W | 9 | GND | NC |
| PI1 | Raspberry Pi Zero 2 W | 10 | rx GPIO15 | NC |
| PI1 | Raspberry Pi Zero 2 W | 11 | GPIO17 | NC |
| PI1 | Raspberry Pi Zero 2 W | 12 | pwm0 GPIO18 | NC |
| PI1 | Raspberry Pi Zero 2 W | 13 | GPIO27 | NC |
| PI1 | Raspberry Pi Zero 2 W | 14 | GND | NC |
| PI1 | Raspberry Pi Zero 2 W | 15 | GPIO22 | NC |
| PI1 | Raspberry Pi Zero 2 W | 16 | GPIO23 | NC |
| PI1 | Raspberry Pi Zero 2 W | 17 | 3V3 | NC |
| PI1 | Raspberry Pi Zero 2 W | 18 | GPIO24 | NC |
| PI1 | Raspberry Pi Zero 2 W | 19 | GPIO10 mosi | NC |
| PI1 | Raspberry Pi Zero 2 W | 20 | GND | NC |
| PI1 | Raspberry Pi Zero 2 W | 21 | GPIO9 miso | NC |
| PI1 | Raspberry Pi Zero 2 W | 22 | GPIO25 | NC |
| PI1 | Raspberry Pi Zero 2 W | 23 | GPIO11 sck | NC |
| PI1 | Raspberry Pi Zero 2 W | 24 | cs0 GPIO8 | NC |
| PI1 | Raspberry Pi Zero 2 W | 25 | GND | NC |
| PI1 | Raspberry Pi Zero 2 W | 26 | cs1 GPIO7 | NC |
| PI1 | Raspberry Pi Zero 2 W | 27 | eeprom sda | NC |
| PI1 | Raspberry Pi Zero 2 W | 28 | eeprom scl | NC |
| PI1 | Raspberry Pi Zero 2 W | 29 | GPIO5 | NC |
| PI1 | Raspberry Pi Zero 2 W | 30 | GND | NC |
| PI1 | Raspberry Pi Zero 2 W | 31 | GPIO6 | NC |
| PI1 | Raspberry Pi Zero 2 W | 32 | pwm0 GPIO12 | NC |
| PI1 | Raspberry Pi Zero 2 W | 33 | GPIO13 pwm1 | NC |
| PI1 | Raspberry Pi Zero 2 W | 34 | GND | NC |
| PI1 | Raspberry Pi Zero 2 W | 35 | GPIO19 pwm1 | NC |
| PI1 | Raspberry Pi Zero 2 W | 36 | GPIO16 | NC |
| PI1 | Raspberry Pi Zero 2 W | 37 | GPIO26 | NC |
| PI1 | Raspberry Pi Zero 2 W | 38 | GPIO20 | NC |
| PI1 | Raspberry Pi Zero 2 W | 39 | GND | NC |
| PI1 | Raspberry Pi Zero 2 W | 40 | GPIO21 | NC |
| R1 | 10k | 1 | 1 | RADIO1_CSN |
| R1 | 10k | 2 | 2 | 3V3_AUX |
| R2 | 10k | 1 | 1 | RADIO1_CE |
| R2 | 10k | 2 | 2 | GND |
| R3 | 10k | 1 | 1 | RADIO2_CSN |
| R3 | 10k | 2 | 2 | 3V3_AUX |
| R4 | 10k | 1 | 1 | RADIO2_CE |
| R4 | 10k | 2 | 2 | GND |
| U1 | CardKB Module | 1 | GND | GND |
| U1 | CardKB Module | 2 | VCC | +5V_EXT |
| U1 | CardKB Module | 3 | SDA | KB_SDA |
| U1 | CardKB Module | 4 | SCL | KB_SCL |

## Current source hashes

- `outputs/schematic-simple-power-native.json`: `1861b7872267eff313ba5267874894d55dfa8f3b06d74e385273eb774742225c`
- `outputs/pcb-simple-power-native.json`: `14c6ba430bfcb49659fa3ca9d57fee9c3092dd0da13f206e33ee1388b886b47c`
- `work/simple-peripherals-component-map.json`: `58d2b779711a2a97318d4067444a9b429520f63a5a96270ed082f26117d4516f`

**ARCHIVE ONLY: every pin table below is historical. Use the current simplified table above.**

## Historical removed power-distribution revision — superseded by simplified power

Authoritative mapping verified against the saved native schematic and PCB exports. Every electrical pin is listed; NC is explicit. Pi mechanical pads and mounting holes are not electrical pins. Native export hashes: `schematic-power-controls-native.json` SHA256 `c6dd9f6371514cf68ee9e741c188a929ef288a5cd1dccff107ef14cf852d8e13`; `pcb-power-controls-native.json` SHA256 `b4796bb77268608138cc8b267f974186b767fe223fdead7ee2df95f0b2418739`; `cyberdeck-bom-updated.xlsx` SHA256 `9cc962a5175b6ab825eb978ec275115109c2573b792e384497ee6c337922aa92`.

| Component | Pin | Symbol pin name | Current net |
|---|---|---|---|
| A1 | 1 | 3V3 | ESP3V3 |
| A1 | 2 | 01 | SDA_LV |
| A1 | 3 | 02 | AUX_OE_N |
| A1 | 4 | 03 | NC |
| A1 | 5 | 10 | ESP_RADIO1_CSN |
| A1 | 6 | 11 | ESP_RADIO_MOSI |
| A1 | 7 | 12 | ESP_RADIO_SCK |
| A1 | 8 | 13 | ESP_RADIO_MISO |
| A1 | 9 | 14 | ESP_RADIO1_CE |
| A1 | 10 | 15 | ESP_RADIO2_CSN |
| A1 | 11 | GND | GND |
| A1 | 12 | VSYS | NC |
| A1 | 13 | VSYS | NC |
| A1 | 14 | 16 | ESP_RADIO2_CE |
| A1 | 15 | 39 | ESP_IR_RX |
| A1 | 16 | 3V3 | NC |
| A1 | 17 | 3V3 | ESP3V3 |
| A1 | 18 | GND | GND |
| A1 | 19 | GND | NC |
| A1 | 20 | 40 | ESP_IR_TX |
| A1 | 21 | 41 | SCL_LV |
| A1 | 22 | 42 | NC |
| A1 | 23 | 43 | NC |
| A1 | 24 | 44 | NC |
| A1 | 25 | 45 | NC |
| A1 | 26 | 46 | NC |
| A1 | 27 | GND | NC |
| A1 | 28 | GND | NC |
| C1 | 1 | 1 | 3V3_AUX |
| C1 | 2 | 2 | GND |
| C2 | 1 | 1 | 3V3_AUX |
| C2 | 2 | 2 | GND |
| C3 | 1 | 1 | 3V3_AUX |
| C3 | 2 | 2 | GND |
| C4 | 1 | 1 | 3V3_AUX |
| C4 | 2 | 2 | GND |
| C5 | 1 | 1 | 5V_SW |
| C5 | 2 | 2 | GND |
| C6 | 1 | 1 | 5V_SW |
| C6 | 2 | 2 | GND |
| C7 | 1 | 1 | 3V3_AUX |
| C7 | 2 | 2 | GND |
| C8 | 1 | 1 | 3V3_AUX |
| C8 | 2 | 2 | GND |
| C9 | 1 | 1 | ESP3V3 |
| C9 | 2 | 2 | GND |
| C10 | 1 | 1 | 5V_SW |
| C10 | 2 | 2 | GND |
| C11 | 1 | 1 | ESP3V3 |
| C11 | 2 | 2 | GND |
| C12 | 1 | 1 | 3V3_AUX |
| C12 | 2 | 2 | GND |
| C13 | 1 | 1 | ESP3V3 |
| C13 | 2 | 2 | GND |
| C14 | 1 | 1 | 3V3_AUX |
| C14 | 2 | 2 | GND |
| F1 | 1 | IN | BANK5V |
| F1 | 2 | OUT | 5V_FUSED |
| IC1 | 1 | GND | GND |
| IC1 | 2 | VCC | 3V3_AUX |
| IC1 | 3 | CE | RADIO1_CE |
| IC1 | 4 | CSN | RADIO1_CSN |
| IC1 | 5 | SCK | RADIO_SCK |
| IC1 | 6 | MOSI | RADIO_MOSI |
| IC1 | 7 | MISO | RADIO_MISO |
| IC1 | 8 | IRQ | NC |
| IC2 | 1 | GND | GND |
| IC2 | 2 | VCC | 3V3_AUX |
| IC2 | 3 | CE | RADIO2_CE |
| IC2 | 4 | CSN | RADIO2_CSN |
| IC2 | 5 | SCK | RADIO_SCK |
| IC2 | 6 | MOSI | RADIO_MOSI |
| IC2 | 7 | MISO | RADIO_MISO |
| IC2 | 8 | IRQ | NC |
| IC3 | 1 | VOUT | 5V_SW |
| IC3 | 2 | IMON | NC |
| IC3 | 3 | DVDT | NC |
| IC3 | 4 | PGTH | NC |
| IC3 | 5 | PGOOD | NC |
| IC3 | 6 | OVLO | NC |
| IC3 | 7 | EN_UVLO | MASTER_UVLO |
| IC3 | 8 | GND | GND |
| IC3 | 9 | VIN | 5V_FUSED |
| IC4 | 1 | PG | NC |
| IC4 | 2 | SHDN | NC |
| IC4 | 3 | VIN | 5V_SW |
| IC4 | 4 | GND | GND |
| IC4 | 5 | VOUT | 3V3_AUX |
| IC5 | 1 | VCCA | ESP3V3 |
| IC5 | 2 | SCLA | SCL_LV |
| IC5 | 3 | SDAA | SDA_LV |
| IC5 | 4 | GND | GND |
| IC5 | 5 | EN | 5V_SW |
| IC5 | 6 | SDAB | KB_SDA |
| IC5 | 7 | SCLB | KB_SCL |
| IC5 | 8 | VCCB | 5V_SW |
| IC6 | 1 | VCCA | ESP3V3 |
| IC6 | 2 | DIR | ESP3V3 |
| IC6 | 3 | A1 | ESP_RADIO_SCK |
| IC6 | 4 | A2 | ESP_RADIO_MOSI |
| IC6 | 5 | A3 | ESP_RADIO1_CSN |
| IC6 | 6 | A4 | ESP_RADIO1_CE |
| IC6 | 7 | A5 | ESP_RADIO2_CSN |
| IC6 | 8 | A6 | ESP_RADIO2_CE |
| IC6 | 9 | A7 | ESP_IR_TX |
| IC6 | 10 | A8 | GND |
| IC6 | 11 | GND | GND |
| IC6 | 12 | GND | GND |
| IC6 | 13 | GND | GND |
| IC6 | 14 | B8 | GND |
| IC6 | 15 | B7 | IR_TX |
| IC6 | 16 | B6 | RADIO2_CE |
| IC6 | 17 | B5 | RADIO2_CSN |
| IC6 | 18 | B4 | RADIO1_CE |
| IC6 | 19 | B3 | RADIO1_CSN |
| IC6 | 20 | B2 | RADIO_MOSI |
| IC6 | 21 | B1 | RADIO_SCK |
| IC6 | 22 | /OE | AUX_OE_N |
| IC6 | 23 | VCCB | 3V3_AUX |
| IC6 | 24 | VCCB | 3V3_AUX |
| IC7 | 1 | VCCA | ESP3V3 |
| IC7 | 2 | A1 | ESP_RADIO_MISO |
| IC7 | 3 | A2 | ESP_IR_RX |
| IC7 | 4 | GND | GND |
| IC7 | 5 | DIR | GND |
| IC7 | 6 | B2 | IR_RX |
| IC7 | 7 | B1 | RADIO_MISO |
| IC7 | 8 | VCCB | 3V3_AUX |
| JP1 | 1 | IRout | IR_TX |
| JP1 | 2 | IRin | IR_RX |
| JP1 | 3 | GND | GND |
| JP1 | 4 | VIN | 3V3_AUX |
| JP2 | 1 | BANK5V | BANK5V |
| JP2 | 2 | GND | GND |
| JP3 | 1 | 5V | 5V_SW |
| JP3 | 2 | GND | GND |
| JP4 | 1 | 5V | 5V_SW |
| JP4 | 2 | GND | GND |
| JP5 | 1 | 5V | 5V_SW |
| JP5 | 2 | GND | GND |
| JP6 | 1 | 5V | 5V_SW |
| JP6 | 2 | GND | GND |
| JP7 | 1 | UVLO | MASTER_UVLO |
| JP7 | 2 | GND | GND |
| JP8 | 1 | GND | GND |
| JP8 | 2 | 3V3 | ESP3V3 |
| JP8 | 3 | SDA | SDA_LV |
| JP8 | 4 | SCL | SCL_LV |
| PI1 | 1 | 3V3 | NC |
| PI1 | 2 | 5V | NC |
| PI1 | 3 | GPIO2 sda | NC |
| PI1 | 4 | 5V | NC |
| PI1 | 5 | GPIO3 scl | NC |
| PI1 | 6 | GND | NC |
| PI1 | 7 | GPIO4 | NC |
| PI1 | 8 | tx GPIO14 | NC |
| PI1 | 9 | GND | NC |
| PI1 | 10 | rx GPIO15 | NC |
| PI1 | 11 | GPIO17 | NC |
| PI1 | 12 | pwm0 GPIO18 | NC |
| PI1 | 13 | GPIO27 | NC |
| PI1 | 14 | GND | NC |
| PI1 | 15 | GPIO22 | NC |
| PI1 | 16 | GPIO23 | NC |
| PI1 | 17 | 3V3 | NC |
| PI1 | 18 | GPIO24 | NC |
| PI1 | 19 | GPIO10 mosi | NC |
| PI1 | 20 | GND | NC |
| PI1 | 21 | GPIO9 miso | NC |
| PI1 | 22 | GPIO25 | NC |
| PI1 | 23 | GPIO11 sck | NC |
| PI1 | 24 | cs0 GPIO8 | NC |
| PI1 | 25 | GND | NC |
| PI1 | 26 | cs1 GPIO7 | NC |
| PI1 | 27 | eeprom sda | NC |
| PI1 | 28 | eeprom scl | NC |
| PI1 | 29 | GPIO5 | NC |
| PI1 | 30 | GND | NC |
| PI1 | 31 | GPIO6 | NC |
| PI1 | 32 | pwm0 GPIO12 | NC |
| PI1 | 33 | GPIO13 pwm1 | NC |
| PI1 | 34 | GND | NC |
| PI1 | 35 | GPIO19 pwm1 | NC |
| PI1 | 36 | GPIO16 | NC |
| PI1 | 37 | GPIO26 | NC |
| PI1 | 38 | GPIO20 | NC |
| PI1 | 39 | GND | NC |
| PI1 | 40 | GPIO21 | NC |
| R1 | 1 | 1 | RADIO1_CSN |
| R1 | 2 | 2 | 3V3_AUX |
| R2 | 1 | 1 | RADIO1_CE |
| R2 | 2 | 2 | GND |
| R3 | 1 | 1 | RADIO2_CSN |
| R3 | 2 | 2 | 3V3_AUX |
| R4 | 1 | 1 | RADIO2_CE |
| R4 | 2 | 2 | GND |
| R5 | 1 | 1 | SDA_LV |
| R5 | 2 | 2 | ESP3V3 |
| R6 | 1 | 1 | SCL_LV |
| R6 | 2 | 2 | ESP3V3 |
| R7 | 1 | 1 | KB_SDA |
| R7 | 2 | 2 | 5V_SW |
| R8 | 1 | 1 | KB_SCL |
| R8 | 2 | 2 | 5V_SW |
| R9 | 1 | 1 | AUX_OE_N |
| R9 | 2 | 2 | ESP3V3 |
| R10 | 1 | 1 | ESP_RADIO1_CSN |
| R10 | 2 | 2 | ESP3V3 |
| R11 | 1 | 1 | ESP_RADIO2_CSN |
| R11 | 2 | 2 | ESP3V3 |
| R12 | 1 | 1 | ESP_RADIO1_CE |
| R12 | 2 | 2 | GND |
| R13 | 1 | 1 | ESP_RADIO2_CE |
| R13 | 2 | 2 | GND |
| R14 | 1 | 1 | ESP_RADIO_SCK |
| R14 | 2 | 2 | GND |
| R15 | 1 | 1 | ESP_RADIO_MOSI |
| R15 | 2 | 2 | GND |
| R16 | 1 | 1 | ESP_IR_TX |
| R16 | 2 | 2 | GND |
| R17 | 1 | 1 | RADIO_MISO |
| R17 | 2 | 2 | GND |
| R18 | 1 | 1 | RADIO_SCK |
| R18 | 2 | 2 | GND |
| R19 | 1 | 1 | RADIO_MOSI |
| R19 | 2 | 2 | GND |
| U1 | 1 | GND | GND |
| U1 | 2 | VCC | 5V_SW |
| U1 | 3 | SDA | KB_SDA |
| U1 | 4 | SCL | KB_SCL |

## Superseded archive — all material below is historical

**Every heading and pin/net table below belongs to an earlier revision and is superseded by the230-pin appendix above. Some original headings retain the word “Current” because their complete source text is preserved verbatim; they are not current wiring or purchase instructions.** In particular, older Q1/Q2, JP2four-pin, fingerprint, microSD and custom-hub assignments must not overwrite this revision.

Historical pin-appendix source byte count: **75211**; SHA-256 **e519fa7af981226692ba270bb2709cf6fdb1fd0beaf8f09a520b1c005cbdfa0d**. All bytes from the previous summary's first134-pin appendix through its final custom-expansion table are retained unchanged below.

### Archived purchasing history

### Historical canceled custom-expansion cost snapshot

The following values belong only to the superseded custom-expansion BOM. Its preserved workbook is in [the local expansion archive](C:/Users/matth/Documents/Codex/2026-09-29/cyberdeck-electrical-engineering/outputs/archive-usb-expansion-2026-10-01/cyberdeck-bom-usb-expansion.xlsx); do not use these historical totals for the retained HAT-based design:

| Category | Priced subtotal |
|---|---:|
| Selected | $253.87 |
| If needed | $35.59 |
| Selected + if needed | $289.46 |
| Optional | $53.75 |
| All priced lines | $343.21 |

**Thirty TBD-price lines are excluded from these sums.** These figures are not a complete build cost and exclude shipping/tax, unpriced parts, PCB fabrication/assembly and unfinished enclosure work. Purchasing lines may group several schematic components; the 52 added BOM lines cover the expansion purchases and are not a count of schematic parts. That canceled design had 133 added components, including DNP options. Do not treat all component-map entries as populated purchases or the original capacitor kit as coverage for the new SMD decoupling network. These canceled-expansion cost snapshots must not be combined with the restored current BOM totals above.

### Historical September 30 BOM revisions before USB expansion

**Historical purchasing record only. The reader, its included cable and JP3 interface described below are now removed; do not order or wire them for the current design.**

At the Fingerprint2 revision, the [Google Sheets BOM](https://docs.google.com/spreadsheets/d/16lRwI5R3pBksWb1bjXYjF_alQrG_2C0rFS-AZ5qpXIg/edit) has been saved and its numeric totals verified:

| Category | Recorded total |
|---|---:|
| Selected | $184.28 |
| If needed | $30.27 |
| Selected + if needed | $214.55 |
| Optional | $58.74 |
| All listed parts | $273.29 |

These historical Fingerprint2-era totals preceded the current $11.50 reader removal; they are not the current totals. The historical purchasing notes remain for context; prices were not refreshed and exclude shipping and tax.

September 30 purchasing revision: the [Avrest YPT M2.5 standoff assortment, 365 pieces, B0FPMC9917](https://www.amazon.com/dp/B0FPMC9917), verified at **$9.99**, is now its own **Selected** item in BOM row 34 for the Pi/HAT. Its cost was removed from the previous optional box bundle in row 30, so at that stage the all-parts total remained **$261.79**, before the Fingerprint2 addition below. The EEEEE M3 kit remains a separate Selected item in row 31 for the carrier and retaining frames. The required Pi/HAT and frame spacer heights remain pending physical stack measurements.

- Added one **Selected** [M5Stack Unit Fingerprint2 (A-K323CP), SKU U203](https://shop.m5stack.com/products/fingerprint-2-unit-a-k323cp) in **BOM row 35** at the verified official price of **$11.50**. The unit includes one **20 cm HY2.0-4P Grove cable**; no extra cable was added. The previous IR item moved from row 35 to **row 36**. This addition increases Selected by $11.50 to **$184.28** and all listed parts to **$273.29**.

- Fingerprint2 electrical integration is saved in **revision 3**: JP3 supplies **5V**, common ground and **3.3V-logic UART at 115200 baud, 8N1**, with approximately **40 mA** active load. **GPIO43 (ESP TX) and GPIO44 (ESP RX) are assigned**, and JP3 is placed vertically at X151.5/Y65 mm, pin 1 at the top through pin 4 at the bottom. Assembly requires **one four-pin 2.54 mm carrier header at JP3 and one compatible Grove-to-header adapter or wired harness** for the included cable; these are assembly requirements, with no newly verified price or additional purchase included in the totals. Reader case mounting, cutout, cable fit and firmware remain pending. CardKB remains selected and wired as documented.

- Added one [EEEEE M3 standoff assortment, B0FBMFBQHQ](https://www.amazon.com/dp/B0FBMFBQHQ), recorded price **$9.99**: 208 pieces, including 6/10/15/20 mm standoffs. Use for the carrier's Ø3.2 mm mounting holes and retaining frames. It contains no M2.5 hardware; the Pi uses the separate M2.5 kit already listed. Required spacer heights and screw-head/hex-body fit within the 6 mm reserves remain unverified. Availability of 10 mm spacers does not establish the correct stack height.

- The listed ELEGOO kit already covers the required capacitors: **four 100nF** for C1/C2/C5/C7 from its ten supplied, and **four 10uF** for C3/C4/C6/C8 from its five supplied. **100uF capacitors were not required** by the original 26-component schematic. This kit-coverage statement does not cover the expansion's additional capacitors or their packages.

- Replacement options, only if needed: four [KEMET C315C104K5R5TA](https://www.digikey.com/en/products/detail/kemet/C315C104K5R5TA/12701330) at the recorded BOM price of $0.79 each ($3.16), 100nF/50V/X7R with 2.54 mm lead pitch; and four [Panasonic EEA-GA1V100](https://www.digikey.com/en/products/detail/panasonic-industry/EEA-GA1V100/2504583) at the recorded BOM price of $0.34 each ($1.36), 10uF/35V/105°C with 2.00 mm pitch and maximum Ø5.5 × 8 mm body including tolerances. Check actual body clearance before assembly. Polarized capacitors use positive pad 1 and GND pad 2. These optional replacement prices are already included in the updated **If needed** total; do not add them again.

The purchasing update itself did not change the circuit. The subsequently authorized Fingerprint2 integration is now saved as electrical revision 3, with JP3 and two UART nets; the costs shown in this subsection are historical.

### Archived coordinate snapshot (superseded)

### Retained original component coordinates

These are LIB origins, not body centers. Angles are clockwise relative to the original unrotated electrical snapshot. The v3 plan uses incremental movement from the already-corrected live backup; A1 is not mirrored again and Pi is not rotated again.

| Ref | Origin X (mm) | Origin Y (mm) | Clockwise orientation from original footprint |
| --- | --- | --- | --- |
| A1 | 182.5 | 37 | 0° |
| PI1 | 110.028 | 31.984 | 90° |
| IC1 | 30.028 | 22.303 | -90° |
| IC2 | 159.972 | 18.707 | 90° |
| U1 | 85 | 33 | 0° |
| JP1 | 6 | 55 | -90° |
| JP2 | 48 | 27 | 0° |
| Q1 | 70 | 34 | 0° |
| Q2 | 70 | 39 | 0° |
| C1 | 28.757 | 32 | -90° |
| C2 | 161.243 | 10.2 | 90° |
| C3 | 36.5 | 32 | 0° |
| C4 | 151.5 | 10.5 | 0° |
| C5 | 80 | 33 | 90° |
| C6 | 80 | 39 | 0° |
| C7 | 14 | 39 | 90° |
| C8 | 21 | 39 | 0° |
| R1 | 36 | 20 | -90° |
| R2 | 40 | 20 | -90° |
| R3 | 153 | 22 | -90° |
| R4 | 149 | 22 | -90° |
| R5 | 48.5 | 34 | 0° |
| R6 | 48.5 | 39 | 0° |
| R7 | 60.5 | 34 | 180° |
| R8 | 60.5 | 39 | 180° |

The historical grouped-layout verification checked the original 25 components, 134 electrical pin/net identities, four Pi mounting pads, 12 native NPTH holes, placement reserves, screw clearances and visible artwork. Revision 3 verification checks the new 26-component/138-electrical-pin schematic and PCB, the JP3 addition and preservation of existing geometry and holes. Those historical audits predate the user's newer tracks/vias. They establish the recorded baseline geometry and connectivity, not the current routing status, completed enclosure fit, RF performance, power design or fabrication readiness.

## Current reader-free complete electrical pin appendix

All 134 electrical pins are listed. Physical pad numbers differ from GPIO numbers. The four Pi mounting pads are excluded.

| Component | Pin | Symbol pin name | Current net |
|---|---|---|---|
| A1 | 1 | 3V3 | ESP3V3 |
| A1 | 2 | 01 | SDA_LV |
| A1 | 3 | 02 | NC |
| A1 | 4 | 03 | NC |
| A1 | 5 | 10 | RADIO1_CSN |
| A1 | 6 | 11 | RADIO_MOSI |
| A1 | 7 | 12 | RADIO_SCK |
| A1 | 8 | 13 | RADIO_MISO |
| A1 | 9 | 14 | RADIO1_CE |
| A1 | 10 | 15 | RADIO2_CSN |
| A1 | 11 | GND | GND |
| A1 | 12 | VSYS | NC |
| A1 | 13 | VSYS | NC |
| A1 | 14 | 16 | RADIO2_CE |
| A1 | 15 | 39 | IR_RX |
| A1 | 16 | 3V3 | NC |
| A1 | 17 | 3V3 | ESP3V3 |
| A1 | 18 | GND | GND |
| A1 | 19 | GND | NC |
| A1 | 20 | 40 | IR_TX |
| A1 | 21 | 41 | SCL_LV |
| A1 | 22 | 42 | NC |
| A1 | 23 | 43 | NC |
| A1 | 24 | 44 | NC |
| A1 | 25 | 45 | NC |
| A1 | 26 | 46 | NC |
| A1 | 27 | GND | NC |
| A1 | 28 | GND | NC |
| C1 | 1 | 1 | 3V3_AUX |
| C1 | 2 | 2 | GND |
| C2 | 1 | 1 | 3V3_AUX |
| C2 | 2 | 2 | GND |
| C3 | 1 | 1 | 3V3_AUX |
| C3 | 2 | 2 | GND |
| C4 | 1 | 1 | 3V3_AUX |
| C4 | 2 | 2 | GND |
| C5 | 1 | 1 | +5V_EXT |
| C5 | 2 | 2 | GND |
| C6 | 1 | 1 | +5V_EXT |
| C6 | 2 | 2 | GND |
| C7 | 1 | 1 | 3V3_AUX |
| C7 | 2 | 2 | GND |
| C8 | 1 | 1 | 3V3_AUX |
| C8 | 2 | 2 | GND |
| IC1 | 1 | GND | GND |
| IC1 | 2 | VCC | 3V3_AUX |
| IC1 | 3 | CE | RADIO1_CE |
| IC1 | 4 | CSN | RADIO1_CSN |
| IC1 | 5 | SCK | RADIO_SCK |
| IC1 | 6 | MOSI | RADIO_MOSI |
| IC1 | 7 | MISO | RADIO_MISO |
| IC1 | 8 | IRQ | NC |
| IC2 | 1 | GND | GND |
| IC2 | 2 | VCC | 3V3_AUX |
| IC2 | 3 | CE | RADIO2_CE |
| IC2 | 4 | CSN | RADIO2_CSN |
| IC2 | 5 | SCK | RADIO_SCK |
| IC2 | 6 | MOSI | RADIO_MOSI |
| IC2 | 7 | MISO | RADIO_MISO |
| IC2 | 8 | IRQ | NC |
| JP1 | 1 | IRout | IR_TX |
| JP1 | 2 | IRin | IR_RX |
| JP1 | 3 | GND | GND |
| JP1 | 4 | VIN | 3V3_AUX |
| JP2 | 1 | +5V_EXT | +5V_EXT |
| JP2 | 2 | GND | GND |
| JP2 | 3 | 3V3_AUX | 3V3_AUX |
| JP2 | 4 | GND | GND |
| PI1 | 1 | 3V3 | NC |
| PI1 | 2 | 5V | NC |
| PI1 | 3 | GPIO2 sda | NC |
| PI1 | 4 | 5V | NC |
| PI1 | 5 | GPIO3 scl | NC |
| PI1 | 6 | GND | NC |
| PI1 | 7 | GPIO4 | NC |
| PI1 | 8 | tx GPIO14 | NC |
| PI1 | 9 | GND | NC |
| PI1 | 10 | rx GPIO15 | NC |
| PI1 | 11 | GPIO17 | NC |
| PI1 | 12 | pwm0 GPIO18 | NC |
| PI1 | 13 | GPIO27 | NC |
| PI1 | 14 | GND | NC |
| PI1 | 15 | GPIO22 | NC |
| PI1 | 16 | GPIO23 | NC |
| PI1 | 17 | 3V3 | NC |
| PI1 | 18 | GPIO24 | NC |
| PI1 | 19 | GPIO10 mosi | NC |
| PI1 | 20 | GND | NC |
| PI1 | 21 | GPIO9 miso | NC |
| PI1 | 22 | GPIO25 | NC |
| PI1 | 23 | GPIO11 sck | NC |
| PI1 | 24 | cs0 GPIO8 | NC |
| PI1 | 25 | GND | NC |
| PI1 | 26 | cs1 GPIO7 | NC |
| PI1 | 27 | eeprom sda | NC |
| PI1 | 28 | eeprom scl | NC |
| PI1 | 29 | GPIO5 | NC |
| PI1 | 30 | GND | NC |
| PI1 | 31 | GPIO6 | NC |
| PI1 | 32 | pwm0 GPIO12 | NC |
| PI1 | 33 | GPIO13 pwm1 | NC |
| PI1 | 34 | GND | NC |
| PI1 | 35 | GPIO19 pwm1 | NC |
| PI1 | 36 | GPIO16 | NC |
| PI1 | 37 | GPIO26 | NC |
| PI1 | 38 | GPIO20 | NC |
| PI1 | 39 | GND | NC |
| PI1 | 40 | GPIO21 | NC |
| Q1 | 1 | G | ESP3V3 |
| Q1 | 2 | S | SDA_LV |
| Q1 | 3 | D | KB_SDA |
| Q2 | 1 | G | ESP3V3 |
| Q2 | 2 | S | SCL_LV |
| Q2 | 3 | D | KB_SCL |
| R1 | 1 | 1 | RADIO1_CSN |
| R1 | 2 | 2 | 3V3_AUX |
| R2 | 1 | 1 | RADIO1_CE |
| R2 | 2 | 2 | GND |
| R3 | 1 | 1 | RADIO2_CSN |
| R3 | 2 | 2 | 3V3_AUX |
| R4 | 1 | 1 | RADIO2_CE |
| R4 | 2 | 2 | GND |
| R5 | 1 | 1 | SDA_LV |
| R5 | 2 | 2 | ESP3V3 |
| R6 | 1 | 1 | SCL_LV |
| R6 | 2 | 2 | ESP3V3 |
| R7 | 1 | 1 | KB_SDA |
| R7 | 2 | 2 | +5V_EXT |
| R8 | 1 | 1 | KB_SCL |
| R8 | 2 | 2 | +5V_EXT |
| U1 | 1 | GND | GND |
| U1 | 2 | VCC | +5V_EXT |
| U1 | 3 | SDA | KB_SDA |
| U1 | 4 | SCL | KB_SCL |

## Historical removed Fingerprint2 revision — superseded October 1, 2026

The following 138-pin table belongs to the removed reader interface. JP3, its UART nets and its mechanical extension are not active. GPIO43/44 are NC in the current 134-pin table above. All later appendices below are also historical.

This table contains all 138 electrical pins after microSD removal. GPIO numbers and physical pad numbers differ. All 40 Pi pins are externally NC in this carrier. Four Pi mechanical pads are excluded.

| Component | Pin | Symbol pin name | Current net |
|---|---|---|---|
| A1 | 1 | 3V3 | ESP3V3 |
| A1 | 2 | 01 | SDA_LV |
| A1 | 3 | 02 | NC |
| A1 | 4 | 03 | NC |
| A1 | 5 | 10 | RADIO1_CSN |
| A1 | 6 | 11 | RADIO_MOSI |
| A1 | 7 | 12 | RADIO_SCK |
| A1 | 8 | 13 | RADIO_MISO |
| A1 | 9 | 14 | RADIO1_CE |
| A1 | 10 | 15 | RADIO2_CSN |
| A1 | 11 | GND | GND |
| A1 | 12 | VSYS | NC |
| A1 | 13 | VSYS | NC |
| A1 | 14 | 16 | RADIO2_CE |
| A1 | 15 | 39 | IR_RX |
| A1 | 16 | 3V3 | NC |
| A1 | 17 | 3V3 | ESP3V3 |
| A1 | 18 | GND | GND |
| A1 | 19 | GND | NC |
| A1 | 20 | 40 | IR_TX |
| A1 | 21 | 41 | SCL_LV |
| A1 | 22 | 42 | NC |
| A1 | 23 | 43 | FP_UART_TX |
| A1 | 24 | 44 | FP_UART_RX |
| A1 | 25 | 45 | NC |
| A1 | 26 | 46 | NC |
| A1 | 27 | GND | NC |
| A1 | 28 | GND | NC |
| C1 | 1 | 1 | 3V3_AUX |
| C1 | 2 | 2 | GND |
| C2 | 1 | 1 | 3V3_AUX |
| C2 | 2 | 2 | GND |
| C3 | 1 | 1 | 3V3_AUX |
| C3 | 2 | 2 | GND |
| C4 | 1 | 1 | 3V3_AUX |
| C4 | 2 | 2 | GND |
| C5 | 1 | 1 | +5V_EXT |
| C5 | 2 | 2 | GND |
| C6 | 1 | 1 | +5V_EXT |
| C6 | 2 | 2 | GND |
| C7 | 1 | 1 | 3V3_AUX |
| C7 | 2 | 2 | GND |
| C8 | 1 | 1 | 3V3_AUX |
| C8 | 2 | 2 | GND |
| IC1 | 1 | GND | GND |
| IC1 | 2 | VCC | 3V3_AUX |
| IC1 | 3 | CE | RADIO1_CE |
| IC1 | 4 | CSN | RADIO1_CSN |
| IC1 | 5 | SCK | RADIO_SCK |
| IC1 | 6 | MOSI | RADIO_MOSI |
| IC1 | 7 | MISO | RADIO_MISO |
| IC1 | 8 | IRQ | NC |
| IC2 | 1 | GND | GND |
| IC2 | 2 | VCC | 3V3_AUX |
| IC2 | 3 | CE | RADIO2_CE |
| IC2 | 4 | CSN | RADIO2_CSN |
| IC2 | 5 | SCK | RADIO_SCK |
| IC2 | 6 | MOSI | RADIO_MOSI |
| IC2 | 7 | MISO | RADIO_MISO |
| IC2 | 8 | IRQ | NC |
| JP1 | 1 | IRout | IR_TX |
| JP1 | 2 | IRin | IR_RX |
| JP1 | 3 | GND | GND |
| JP1 | 4 | VIN | 3V3_AUX |
| JP2 | 1 | +5V_EXT | +5V_EXT |
| JP2 | 2 | GND | GND |
| JP2 | 3 | 3V3_AUX | 3V3_AUX |
| JP2 | 4 | GND | GND |
| JP3 | 1 | FP_UART_RX | FP_UART_RX |
| JP3 | 2 | FP_UART_TX | FP_UART_TX |
| JP3 | 3 | +5V_EXT | +5V_EXT |
| JP3 | 4 | GND | GND |
| PI1 | 1 | 3V3 | NC |
| PI1 | 2 | 5V | NC |
| PI1 | 3 | GPIO2 sda | NC |
| PI1 | 4 | 5V | NC |
| PI1 | 5 | GPIO3 scl | NC |
| PI1 | 6 | GND | NC |
| PI1 | 7 | GPIO4 | NC |
| PI1 | 8 | tx GPIO14 | NC |
| PI1 | 9 | GND | NC |
| PI1 | 10 | rx GPIO15 | NC |
| PI1 | 11 | GPIO17 | NC |
| PI1 | 12 | pwm0 GPIO18 | NC |
| PI1 | 13 | GPIO27 | NC |
| PI1 | 14 | GND | NC |
| PI1 | 15 | GPIO22 | NC |
| PI1 | 16 | GPIO23 | NC |
| PI1 | 17 | 3V3 | NC |
| PI1 | 18 | GPIO24 | NC |
| PI1 | 19 | GPIO10 mosi | NC |
| PI1 | 20 | GND | NC |
| PI1 | 21 | GPIO9 miso | NC |
| PI1 | 22 | GPIO25 | NC |
| PI1 | 23 | GPIO11 sck | NC |
| PI1 | 24 | cs0 GPIO8 | NC |
| PI1 | 25 | GND | NC |
| PI1 | 26 | cs1 GPIO7 | NC |
| PI1 | 27 | eeprom sda | NC |
| PI1 | 28 | eeprom scl | NC |
| PI1 | 29 | GPIO5 | NC |
| PI1 | 30 | GND | NC |
| PI1 | 31 | GPIO6 | NC |
| PI1 | 32 | pwm0 GPIO12 | NC |
| PI1 | 33 | GPIO13 pwm1 | NC |
| PI1 | 34 | GND | NC |
| PI1 | 35 | GPIO19 pwm1 | NC |
| PI1 | 36 | GPIO16 | NC |
| PI1 | 37 | GPIO26 | NC |
| PI1 | 38 | GPIO20 | NC |
| PI1 | 39 | GND | NC |
| PI1 | 40 | GPIO21 | NC |
| Q1 | 1 | G | ESP3V3 |
| Q1 | 2 | S | SDA_LV |
| Q1 | 3 | D | KB_SDA |
| Q2 | 1 | G | ESP3V3 |
| Q2 | 2 | S | SCL_LV |
| Q2 | 3 | D | KB_SCL |
| R1 | 1 | 1 | RADIO1_CSN |
| R1 | 2 | 2 | 3V3_AUX |
| R2 | 1 | 1 | RADIO1_CE |
| R2 | 2 | 2 | GND |
| R3 | 1 | 1 | RADIO2_CSN |
| R3 | 2 | 2 | 3V3_AUX |
| R4 | 1 | 1 | RADIO2_CE |
| R4 | 2 | 2 | GND |
| R5 | 1 | 1 | SDA_LV |
| R5 | 2 | 2 | ESP3V3 |
| R6 | 1 | 1 | SCL_LV |
| R6 | 2 | 2 | ESP3V3 |
| R7 | 1 | 1 | KB_SDA |
| R7 | 2 | 2 | +5V_EXT |
| R8 | 1 | 1 | KB_SCL |
| R8 | 2 | 2 | +5V_EXT |
| U1 | 1 | GND | GND |
| U1 | 2 | VCC | +5V_EXT |
| U1 | 3 | SDA | KB_SDA |
| U1 | 4 | SCL | KB_SCL |

## Historical removed Pi SPI1 microSD revision 4 — superseded October 1, 2026

The user explicitly removed this addition and requested no USB substitute. The following 187 rows document the removed circuit only. Its J1/U2/D1/R9–R16/C9–C12, eight Pi assignments, regulator, extra card, software overlay and added copper are not part of the active design. The circuit had a verified saved schematic and a reviewed routed candidate; it was never released for fabrication. The Fingerprint2 mechanical space/holes are retained independently.

| Component | Pin | Symbol pin name | Superseded net |
|---|---|---|---|
| A1 | 1 | 3V3 | ESP3V3 |
| A1 | 2 | 01 | SDA_LV |
| A1 | 3 | 02 | NC |
| A1 | 4 | 03 | NC |
| A1 | 5 | 10 | RADIO1_CSN |
| A1 | 6 | 11 | RADIO_MOSI |
| A1 | 7 | 12 | RADIO_SCK |
| A1 | 8 | 13 | RADIO_MISO |
| A1 | 9 | 14 | RADIO1_CE |
| A1 | 10 | 15 | RADIO2_CSN |
| A1 | 11 | GND | GND |
| A1 | 12 | VSYS | NC |
| A1 | 13 | VSYS | NC |
| A1 | 14 | 16 | RADIO2_CE |
| A1 | 15 | 39 | IR_RX |
| A1 | 16 | 3V3 | NC |
| A1 | 17 | 3V3 | ESP3V3 |
| A1 | 18 | GND | GND |
| A1 | 19 | GND | NC |
| A1 | 20 | 40 | IR_TX |
| A1 | 21 | 41 | SCL_LV |
| A1 | 22 | 42 | NC |
| A1 | 23 | 43 | FP_UART_TX |
| A1 | 24 | 44 | FP_UART_RX |
| A1 | 25 | 45 | NC |
| A1 | 26 | 46 | NC |
| A1 | 27 | GND | NC |
| A1 | 28 | GND | NC |
| C1 | 1 | 1 | 3V3_AUX |
| C1 | 2 | 2 | GND |
| C2 | 1 | 1 | 3V3_AUX |
| C2 | 2 | 2 | GND |
| C3 | 1 | 1 | 3V3_AUX |
| C3 | 2 | 2 | GND |
| C4 | 1 | 1 | 3V3_AUX |
| C4 | 2 | 2 | GND |
| C5 | 1 | 1 | +5V_EXT |
| C5 | 2 | 2 | GND |
| C6 | 1 | 1 | +5V_EXT |
| C6 | 2 | 2 | GND |
| C7 | 1 | 1 | 3V3_AUX |
| C7 | 2 | 2 | GND |
| C8 | 1 | 1 | 3V3_AUX |
| C8 | 2 | 2 | GND |
| C9 | 1 | 1 | PI_5V |
| C9 | 2 | 2 | GND |
| C10 | 1 | 1 | SD_3V3 |
| C10 | 2 | 2 | GND |
| C11 | 1 | 1 | SD_3V3 |
| C11 | 2 | 2 | GND |
| C12 | 1 | 1 | SD_3V3 |
| C12 | 2 | 2 | GND |
| D1 | 1 | IO1 | SD_DAT2 |
| D1 | 2 | IO2 | SD_CS_N |
| D1 | 3 | IO3 | SD_MOSI |
| D1 | 4 | GND | GND |
| D1 | 5 | IO4 | SD_CLK |
| D1 | 6 | IO5 | SD_MISO |
| D1 | 7 | IO6 | SD_DAT1 |
| D1 | 8 | VCC | SD_3V3 |
| IC1 | 1 | GND | GND |
| IC1 | 2 | VCC | 3V3_AUX |
| IC1 | 3 | CE | RADIO1_CE |
| IC1 | 4 | CSN | RADIO1_CSN |
| IC1 | 5 | SCK | RADIO_SCK |
| IC1 | 6 | MOSI | RADIO_MOSI |
| IC1 | 7 | MISO | RADIO_MISO |
| IC1 | 8 | IRQ | NC |
| IC2 | 1 | GND | GND |
| IC2 | 2 | VCC | 3V3_AUX |
| IC2 | 3 | CE | RADIO2_CE |
| IC2 | 4 | CSN | RADIO2_CSN |
| IC2 | 5 | SCK | RADIO_SCK |
| IC2 | 6 | MOSI | RADIO_MOSI |
| IC2 | 7 | MISO | RADIO_MISO |
| IC2 | 8 | IRQ | NC |
| J1 | 1 | DAT2 | SD_DAT2 |
| J1 | 2 | DAT3 / CS_N | SD_CS_N |
| J1 | 3 | CMD / MOSI | SD_MOSI |
| J1 | 4 | VDD | SD_3V3 |
| J1 | 5 | CLK | SD_CLK |
| J1 | 6 | VSS | GND |
| J1 | 7 | DAT0 / MISO | SD_MISO |
| J1 | 8 | DAT1 | SD_DAT1 |
| J1 | A | CD switch A | SD_CD_N |
| J1 | B | CD switch B | GND |
| J1 | SHELL | SHIELD | GND |
| JP1 | 1 | IRout | IR_TX |
| JP1 | 2 | IRin | IR_RX |
| JP1 | 3 | GND | GND |
| JP1 | 4 | VIN | 3V3_AUX |
| JP2 | 1 | +5V_EXT | +5V_EXT |
| JP2 | 2 | GND | GND |
| JP2 | 3 | 3V3_AUX | 3V3_AUX |
| JP2 | 4 | GND | GND |
| JP3 | 1 | FP_UART_RX | FP_UART_RX |
| JP3 | 2 | FP_UART_TX | FP_UART_TX |
| JP3 | 3 | +5V_EXT | +5V_EXT |
| JP3 | 4 | GND | GND |
| PI1 | 1 | 3V3 | PI_3V3 |
| PI1 | 2 | 5V | PI_5V |
| PI1 | 3 | GPIO2 sda | NC |
| PI1 | 4 | 5V | NC |
| PI1 | 5 | GPIO3 scl | NC |
| PI1 | 6 | GND | GND |
| PI1 | 7 | GPIO4 | NC |
| PI1 | 8 | tx GPIO14 | NC |
| PI1 | 9 | GND | NC |
| PI1 | 10 | rx GPIO15 | NC |
| PI1 | 11 | GPIO17 | NC |
| PI1 | 12 | pwm0 GPIO18 | SD_CS_N |
| PI1 | 13 | GPIO27 | NC |
| PI1 | 14 | GND | NC |
| PI1 | 15 | GPIO22 | NC |
| PI1 | 16 | GPIO23 | NC |
| PI1 | 17 | 3V3 | NC |
| PI1 | 18 | GPIO24 | NC |
| PI1 | 19 | GPIO10 mosi | NC |
| PI1 | 20 | GND | NC |
| PI1 | 21 | GPIO9 miso | NC |
| PI1 | 22 | GPIO25 | NC |
| PI1 | 23 | GPIO11 sck | NC |
| PI1 | 24 | cs0 GPIO8 | NC |
| PI1 | 25 | GND | NC |
| PI1 | 26 | cs1 GPIO7 | NC |
| PI1 | 27 | eeprom sda | NC |
| PI1 | 28 | eeprom scl | NC |
| PI1 | 29 | GPIO5 | NC |
| PI1 | 30 | GND | NC |
| PI1 | 31 | GPIO6 | NC |
| PI1 | 32 | pwm0 GPIO12 | NC |
| PI1 | 33 | GPIO13 pwm1 | NC |
| PI1 | 34 | GND | NC |
| PI1 | 35 | GPIO19 pwm1 | SD_MISO |
| PI1 | 36 | GPIO16 | SD_CD_N |
| PI1 | 37 | GPIO26 | NC |
| PI1 | 38 | GPIO20 | SD_MOSI |
| PI1 | 39 | GND | NC |
| PI1 | 40 | GPIO21 | SD_CLK_SRC |
| Q1 | 1 | G | ESP3V3 |
| Q1 | 2 | S | SDA_LV |
| Q1 | 3 | D | KB_SDA |
| Q2 | 1 | G | ESP3V3 |
| Q2 | 2 | S | SCL_LV |
| Q2 | 3 | D | KB_SCL |
| R1 | 1 | 1 | RADIO1_CSN |
| R1 | 2 | 2 | 3V3_AUX |
| R2 | 1 | 1 | RADIO1_CE |
| R2 | 2 | 2 | GND |
| R3 | 1 | 1 | RADIO2_CSN |
| R3 | 2 | 2 | 3V3_AUX |
| R4 | 1 | 1 | RADIO2_CE |
| R4 | 2 | 2 | GND |
| R5 | 1 | 1 | SDA_LV |
| R5 | 2 | 2 | ESP3V3 |
| R6 | 1 | 1 | SCL_LV |
| R6 | 2 | 2 | ESP3V3 |
| R7 | 1 | 1 | KB_SDA |
| R7 | 2 | 2 | +5V_EXT |
| R8 | 1 | 1 | KB_SCL |
| R8 | 2 | 2 | +5V_EXT |
| R9 | 1 | 1 | SD_3V3 |
| R9 | 2 | 2 | SD_MOSI |
| R10 | 1 | 1 | SD_3V3 |
| R10 | 2 | 2 | SD_MISO |
| R11 | 1 | 1 | SD_3V3 |
| R11 | 2 | 2 | SD_DAT1 |
| R12 | 1 | 1 | SD_3V3 |
| R12 | 2 | 2 | SD_DAT2 |
| R13 | 1 | 1 | SD_3V3 |
| R13 | 2 | 2 | SD_CS_N |
| R14 | 1 | 1 | PI_3V3 |
| R14 | 2 | 2 | SD_CD_N |
| R15 | 1 | 1 | PI_3V3 |
| R15 | 2 | 2 | GND |
| R16 | 1 | 1 | SD_CLK_SRC |
| R16 | 2 | 2 | SD_CLK |
| U1 | 1 | GND | GND |
| U1 | 2 | VCC | +5V_EXT |
| U1 | 3 | SDA | KB_SDA |
| U1 | 4 | SCL | KB_SCL |
| U2 | 1 | IN | PI_5V |
| U2 | 2 | OUT 3.3V | SD_3V3 |
| U2 | 3 | GND | GND |
| U2 | 4 | NR (NC) | NC |
| U2 | 5 | EN | PI_3V3 |
| U2 | 6 | TAB / GND | GND |

The following older appendices are unchanged historical records. Current wiring is the 138-pin table above.

## Historical revision 3 electrical design and complete PCB pin appendix

**Historical scope:** the retained text below describes the pre-expansion revision 3 exports. The new 486-pin appendix and four Pi overrides at the end take precedence for the expansion schematic. The fresh PCB backup separately preserves the user's later tracks/vias.

Snapshot documented on 2026-09-30 from project `cyberdeck-completed`, `Sheet_1`, corrected wiring revision 3 including Fingerprint2 via JP3. This describes the saved exports, not later live edits and not a finished enclosure layout.

Sources: [wiring-map-fingerprint.json](C:/Users/matth/Documents/Codex/2026-09-29/cyberdeck-electrical-engineering/outputs/wiring-map-fingerprint.json), [schematic-fingerprint.json](C:/Users/matth/Documents/Codex/2026-09-29/cyberdeck-electrical-engineering/outputs/schematic-fingerprint.json), [pcb-fingerprint.json](C:/Users/matth/Documents/Codex/2026-09-29/cyberdeck-electrical-engineering/outputs/pcb-fingerprint.json), [fingerprint-verification.json](C:/Users/matth/Documents/Codex/2026-09-29/cyberdeck-electrical-engineering/outputs/fingerprint-verification.json). The schematic and PCB file hashes were checked against the final PASS report; the schematic graph, wiring map, PCB pads and all 138 appendix pin rows were also matched while publishing this summary.

Verified inventory: **26 components; 138 electrical symbol/footprint pins; 85 connected pins on 19 connected nets; 53 externally unconnected pins.** The PCB additionally contains four existing, unconnected non-plated Pi mounting-hole pad records, making **142 physical PAD records**. Those four holes and the 12 native carrier NPTH holes are not additional schematic pins. No reader mounting holes were added.

### Numbering and interpretation

- **A1 pin numbers are symbol/footprint pad numbers, not ESP32 GPIO numbers.** For example, A1 pin 2 is GPIO1, A1 pin 7 is GPIO12, and A1 pin 21 is GPIO41. The A1 table expands numerical symbol labels to identify their GPIO meaning.
- Each table lists the saved symbol/footprint pad number. Compatibility with the actual purchased modules, header orientation and physical dimensions still needs hardware verification.
- `Connected` means an external schematic net is defined. `Unconnected` means no external schematic connection; the PCB assigns a unique singleton name such as `A1_12` or `PI1_1`. These names are not shared nets or proof of electrical isolation inside a module. Module-internal power/ground connections are outside this netlist.
- Polarized capacitors C3/C4/C6/C8 use design pin 1 as positive and pin 2 as negative. Verify actual part markings and footprint orientation. Ceramic C1/C2/C5/C7 are nonpolar.
- JP1 follows the Adafruit module 2.54mm header numbering: 1 IRout, 2 IRin, 3 GND, 4 VIN. Its footprint is not the module's JST socket. JP2 uses its own distinct numbering: 1 +5V_EXT, 2 GND, 3 3V3_AUX, 4 GND.

### Component values and assigned footprints

| Ref | Saved value/model | Assigned footprint | Electrical pins | Function |
| --- | --- | --- | --- | --- |
| A1 | ESP32-S3-AMOLED-1.91 | T-DISPLAY S3 AMOLED | 28 | ESP32-S3 AMOLED module / peripheral controller |
| PI1 | PI ZERO2 WDADAD | RASPBERRY-PIZERO-W | 40 | Raspberry Pi placeholder; all 40 pins externally unwired |
| IC1 | NRF24L01 | NRF24L01 | 8 | Radio 1; shared SPI2, independent CSN/CE |
| IC2 | NRF24L01 | NRF24L01 | 8 | Radio 2; shared SPI2, independent CSN/CE |
| U1 | CardKB Module | NXW-04K | 4 | CardKB connector; external 5V and translated I2C |
| JP1 | Adafruit 5990 IR RX/TX module | HDR-1X4T/2.54/10X2_J9 | 4 | IR module carrier header; Adafruit 0.1in header numbering |
| JP2 | REGULATED POWER INPUT | HDR-1X4T/2.54/10X2_J9 | 4 | External regulated 5V/3.3V input; no regulators implemented |
| JP3 | FINGERPRINT2 UART HEADER | HDR-1X4T/2.54/10X2_J9 | 4 | Fingerprint2 carrier header; 5V, 3.3V UART; Grove adapter/harness required |
| Q1 | BSS138 | BSS138 | 3 | SDA level translator; G1/S2/D3 |
| Q2 | BSS138 | BSS138 | 3 | SCL level translator; G1/S2/D3 |
| C1 | 100nF | CERAMIC CAPACITOR 100NF 50V | 2 | Radio 1 local ceramic bypass |
| C2 | 100nF | CERAMIC CAPACITOR 100NF 50V | 2 | Radio 2 local ceramic bypass |
| C3 | 10uF | CAPACITOR 10UF TH FP | 2 | Radio 1 local polarized bulk capacitor |
| C4 | 10uF | CAPACITOR 10UF TH FP | 2 | Radio 2 local polarized bulk capacitor |
| C5 | 100nF | CERAMIC CAPACITOR 100NF 50V | 2 | CardKB 5V local ceramic bypass |
| C6 | 10uF | CAPACITOR 10UF TH FP | 2 | CardKB 5V local polarized bulk capacitor |
| C7 | 100nF | CERAMIC CAPACITOR 100NF 50V | 2 | IR AUX 3.3V local ceramic bypass |
| C8 | 10uF | CAPACITOR 10UF TH FP | 2 | IR AUX 3.3V local polarized bulk capacitor |
| R1 | 10k | R_AXIAL-0.3 | 2 | Radio 1 CSN pull-up to 3V3_AUX |
| R2 | 10k | R_AXIAL-0.3 | 2 | Radio 1 CE pull-down to GND |
| R3 | 10k | R_AXIAL-0.3 | 2 | Radio 2 CSN pull-up to 3V3_AUX |
| R4 | 10k | R_AXIAL-0.3 | 2 | Radio 2 CE pull-down to GND |
| R5 | 4.7k | R_AXIAL-0.3 | 2 | SDA_LV pull-up to ESP3V3 |
| R6 | 4.7k | R_AXIAL-0.3 | 2 | SCL_LV pull-up to ESP3V3 |
| R7 | 10k | R_AXIAL-0.3 | 2 | KB_SDA pull-up to +5V_EXT |
| R8 | 10k | R_AXIAL-0.3 | 2 | KB_SCL pull-up to +5V_EXT |

Footprint names are saved library assignments, not dimensional validation. The misleading supplier/manufacturer purchasing fields on C1/C2 were cleared; their intended value remains 100nF. Do not restore the old 47pF/3kV/C19375 purchasing metadata. Q1/Q2 use the corrected G1/S2/D3 mapping.

### All 19 connected nets

| Net | Endpoints | Count |
| --- | --- | --- |
| ESP3V3 | A1.1 (3V3), A1.17 (3V3), Q1.1 (G), Q2.1 (G), R5.2 (2), R6.2 (2) | 6 |
| +5V_EXT | JP2.1 (+5V_EXT), U1.2 (VCC), R7.2 (2), R8.2 (2), C5.1 (1), C6.1 (1), JP3.3 (+5V_EXT) | 7 |
| 3V3_AUX | JP2.3 (3V3_AUX), IC1.2 (VCC), IC2.2 (VCC), JP1.4 (VIN), R1.2 (2), R3.2 (2), C1.1 (1), C2.1 (1), C3.1 (1), C4.1 (1), C7.1 (1), C8.1 (1) | 12 |
| GND | A1.11 (GND), A1.18 (GND), JP2.2 (GND), JP2.4 (GND), IC1.1 (GND), IC2.1 (GND), U1.1 (GND), JP1.3 (GND), R2.2 (2), R4.2 (2), C1.2 (2), C2.2 (2), C3.2 (2), C4.2 (2), C5.2 (2), C6.2 (2), C7.2 (2), C8.2 (2), JP3.4 (GND) | 19 |
| RADIO_SCK | A1.7 (12), IC1.5 (SCK), IC2.5 (SCK) | 3 |
| RADIO_MOSI | A1.6 (11), IC1.6 (MOSI), IC2.6 (MOSI) | 3 |
| RADIO_MISO | A1.8 (13), IC1.7 (MISO), IC2.7 (MISO) | 3 |
| RADIO1_CSN | A1.5 (10), IC1.4 (CSN), R1.1 (1) | 3 |
| RADIO1_CE | A1.9 (14), IC1.3 (CE), R2.1 (1) | 3 |
| RADIO2_CSN | A1.10 (15), IC2.4 (CSN), R3.1 (1) | 3 |
| RADIO2_CE | A1.14 (16), IC2.3 (CE), R4.1 (1) | 3 |
| SDA_LV | A1.2 (01), Q1.2 (S), R5.1 (1) | 3 |
| SCL_LV | A1.21 (41), Q2.2 (S), R6.1 (1) | 3 |
| KB_SDA | Q1.3 (D), R7.1 (1), U1.3 (SDA) | 3 |
| KB_SCL | Q2.3 (D), R8.1 (1), U1.4 (SCL) | 3 |
| IR_RX | A1.15 (39), JP1.2 (IRin) | 2 |
| IR_TX | A1.20 (40), JP1.1 (IRout) | 2 |
| FP_UART_TX | A1.23 (43), JP3.2 (FP_UART_TX) | 2 |
| FP_UART_RX | A1.24 (44), JP3.1 (FP_UART_RX) | 2 |

Supply boundaries: ESP3V3 is sourced from the LILYGO 3.3V rail and serves the I2C low-side pull-ups and MOSFET gates. +5V_EXT supplies CardKB, its high-side pull-ups and Fingerprint2 via JP3.3. 3V3_AUX supplies both radios, their CSN pull-ups/decoupling, and IR. All share GND. **No regulators are implemented here; do not parallel 3V3_AUX with A1 3V3, or use A1 VSYS as a presumed regulated 5V source.** Power sequencing/backfeed behavior remains unvalidated; the current annotation calls for coordinated external-rail and ESP32 USB power switching.

Firmware allocation retained by the design: both radios share SPI2 on GPIO12 SCK / GPIO11 MOSI / GPIO13 MISO, with separate CSN GPIO10/15 and CE GPIO14/16; display allocation is SPI3. CardKB uses Wire1, SDA GPIO1, SCL GPIO41, at 100kHz. IR receive is GPIO39; IR transmit control is GPIO40. Fingerprint UART uses Serial1 at 115200 baud, 8N1, with TX GPIO43 and RX GPIO44; native USB is intended for logging/programming. These are intended firmware settings, not tested operation.

### A1 — all 28 LILYGO header pins

| Ref | Symbol / pad pin | Saved label / meaning | PCB net | Status |
| --- | --- | --- | --- | --- |
| A1 | 1 | 3V3 | ESP3V3 | Connected |
| A1 | 2 | 01 (GPIO1) | SDA_LV | Connected |
| A1 | 3 | 02 (GPIO2) | A1_3 | Unconnected |
| A1 | 4 | 03 (GPIO3) | A1_4 | Unconnected |
| A1 | 5 | 10 (GPIO10) | RADIO1_CSN | Connected |
| A1 | 6 | 11 (GPIO11) | RADIO_MOSI | Connected |
| A1 | 7 | 12 (GPIO12) | RADIO_SCK | Connected |
| A1 | 8 | 13 (GPIO13) | RADIO_MISO | Connected |
| A1 | 9 | 14 (GPIO14) | RADIO1_CE | Connected |
| A1 | 10 | 15 (GPIO15) | RADIO2_CSN | Connected |
| A1 | 11 | GND | GND | Connected |
| A1 | 12 | VSYS | A1_12 | Unconnected |
| A1 | 13 | VSYS | A1_13 | Unconnected |
| A1 | 14 | 16 (GPIO16) | RADIO2_CE | Connected |
| A1 | 15 | 39 (GPIO39) | IR_RX | Connected |
| A1 | 16 | 3V3 | A1_16 | Unconnected |
| A1 | 17 | 3V3 | ESP3V3 | Connected |
| A1 | 18 | GND | GND | Connected |
| A1 | 19 | GND | A1_19 | Unconnected |
| A1 | 20 | 40 (GPIO40) | IR_TX | Connected |
| A1 | 21 | 41 (GPIO41) | SCL_LV | Connected |
| A1 | 22 | 42 (GPIO42) | A1_22 | Unconnected |
| A1 | 23 | 43 (GPIO43) | FP_UART_TX | Connected |
| A1 | 24 | 44 (GPIO44) | FP_UART_RX | Connected |
| A1 | 25 | 45 (GPIO45) | A1_25 | Unconnected |
| A1 | 26 | 46 (GPIO46) | A1_26 | Unconnected |
| A1 | 27 | GND | A1_27 | Unconnected |
| A1 | 28 | GND | A1_28 | Unconnected |

### PI1 — all 40 Raspberry Pi header pins

| Ref | Symbol / pad pin | Saved label / meaning | PCB net | Status |
| --- | --- | --- | --- | --- |
| PI1 | 1 | 3V3 | PI1_1 | Unconnected |
| PI1 | 2 | 5V | PI1_2 | Unconnected |
| PI1 | 3 | GPIO2 sda | PI1_3 | Unconnected |
| PI1 | 4 | 5V | PI1_4 | Unconnected |
| PI1 | 5 | GPIO3 scl | PI1_5 | Unconnected |
| PI1 | 6 | GND | PI1_6 | Unconnected |
| PI1 | 7 | GPIO4 | PI1_7 | Unconnected |
| PI1 | 8 | tx GPIO14 | PI1_8 | Unconnected |
| PI1 | 9 | GND | PI1_9 | Unconnected |
| PI1 | 10 | rx GPIO15 | PI1_10 | Unconnected |
| PI1 | 11 | GPIO17 | PI1_11 | Unconnected |
| PI1 | 12 | pwm0 GPIO18 | PI1_12 | Unconnected |
| PI1 | 13 | GPIO27 | PI1_13 | Unconnected |
| PI1 | 14 | GND | PI1_14 | Unconnected |
| PI1 | 15 | GPIO22 | PI1_15 | Unconnected |
| PI1 | 16 | GPIO23 | PI1_16 | Unconnected |
| PI1 | 17 | 3V3 | PI1_17 | Unconnected |
| PI1 | 18 | GPIO24 | PI1_18 | Unconnected |
| PI1 | 19 | GPIO10 mosi | PI1_19 | Unconnected |
| PI1 | 20 | GND | PI1_20 | Unconnected |
| PI1 | 21 | GPIO9 miso | PI1_21 | Unconnected |
| PI1 | 22 | GPIO25 | PI1_22 | Unconnected |
| PI1 | 23 | GPIO11 sck | PI1_23 | Unconnected |
| PI1 | 24 | cs0 GPIO8 | PI1_24 | Unconnected |
| PI1 | 25 | GND | PI1_25 | Unconnected |
| PI1 | 26 | cs1 GPIO7 | PI1_26 | Unconnected |
| PI1 | 27 | eeprom sda | PI1_27 | Unconnected |
| PI1 | 28 | eeprom scl | PI1_28 | Unconnected |
| PI1 | 29 | GPIO5 | PI1_29 | Unconnected |
| PI1 | 30 | GND | PI1_30 | Unconnected |
| PI1 | 31 | GPIO6 | PI1_31 | Unconnected |
| PI1 | 32 | pwm0 GPIO12 | PI1_32 | Unconnected |
| PI1 | 33 | GPIO13 pwm1 | PI1_33 | Unconnected |
| PI1 | 34 | GND | PI1_34 | Unconnected |
| PI1 | 35 | GPIO19 pwm1 | PI1_35 | Unconnected |
| PI1 | 36 | GPIO16 | PI1_36 | Unconnected |
| PI1 | 37 | GPIO26 | PI1_37 | Unconnected |
| PI1 | 38 | GPIO20 | PI1_38 | Unconnected |
| PI1 | 39 | GND | PI1_39 | Unconnected |
| PI1 | 40 | GPIO21 | PI1_40 | Unconnected |

### IC1/IC2 — both radio headers

| Ref | Symbol / pad pin | Saved label / meaning | PCB net | Status |
| --- | --- | --- | --- | --- |
| IC1 | 1 | GND | GND | Connected |
| IC1 | 2 | VCC | 3V3_AUX | Connected |
| IC1 | 3 | CE | RADIO1_CE | Connected |
| IC1 | 4 | CSN | RADIO1_CSN | Connected |
| IC1 | 5 | SCK | RADIO_SCK | Connected |
| IC1 | 6 | MOSI | RADIO_MOSI | Connected |
| IC1 | 7 | MISO | RADIO_MISO | Connected |
| IC1 | 8 | IRQ | IC1_8 | Unconnected |
| IC2 | 1 | GND | GND | Connected |
| IC2 | 2 | VCC | 3V3_AUX | Connected |
| IC2 | 3 | CE | RADIO2_CE | Connected |
| IC2 | 4 | CSN | RADIO2_CSN | Connected |
| IC2 | 5 | SCK | RADIO_SCK | Connected |
| IC2 | 6 | MOSI | RADIO_MOSI | Connected |
| IC2 | 7 | MISO | RADIO_MISO | Connected |
| IC2 | 8 | IRQ | IC2_8 | Unconnected |

### U1, JP1 and JP2 — keyboard, IR and regulated power connectors

| Ref | Symbol / pad pin | Saved label / meaning | PCB net | Status |
| --- | --- | --- | --- | --- |
| U1 | 1 | GND | GND | Connected |
| U1 | 2 | VCC | +5V_EXT | Connected |
| U1 | 3 | SDA | KB_SDA | Connected |
| U1 | 4 | SCL | KB_SCL | Connected |
| JP1 | 1 | IRout | IR_TX | Connected |
| JP1 | 2 | IRin | IR_RX | Connected |
| JP1 | 3 | GND | GND | Connected |
| JP1 | 4 | VIN | 3V3_AUX | Connected |
| JP2 | 1 | +5V_EXT | +5V_EXT | Connected |
| JP2 | 2 | GND | GND | Connected |
| JP2 | 3 | 3V3_AUX | 3V3_AUX | Connected |
| JP2 | 4 | GND | GND | Connected |

### JP3 — Fingerprint2 carrier header

| Ref | Symbol / pad pin | Saved label / meaning | PCB net | Status |
| --- | --- | --- | --- | --- |
| JP3 | 1 | FP_UART_RX | FP_UART_RX | Connected |
| JP3 | 2 | FP_UART_TX | FP_UART_TX | Connected |
| JP3 | 3 | +5V_EXT | +5V_EXT | Connected |
| JP3 | 4 | GND | GND | Connected |

JP3 is a generic 2.54 mm header. Cable mapping to Fingerprint2: white reader TX → pin 1 → ESP GPIO44; yellow reader RX ← pin 2 ← ESP GPIO43; red 5V → pin 3; black GND → pin 4. The included HY2.0-4P Grove cable needs a compatible adapter/harness; it does not directly mate with this footprint. Net TX/RX names describe the ESP direction.

### Q1/Q2 — I2C level-translator transistors

| Ref | Symbol / pad pin | Saved label / meaning | PCB net | Status |
| --- | --- | --- | --- | --- |
| Q1 | 1 | G | ESP3V3 | Connected |
| Q1 | 2 | S | SDA_LV | Connected |
| Q1 | 3 | D | KB_SDA | Connected |
| Q2 | 1 | G | ESP3V3 | Connected |
| Q2 | 2 | S | SCL_LV | Connected |
| Q2 | 3 | D | KB_SCL | Connected |

### C1–C8 — all capacitor terminals

| Ref | Symbol / pad pin | Saved label / meaning | PCB net | Status |
| --- | --- | --- | --- | --- |
| C1 | 1 | 1 | 3V3_AUX | Connected |
| C1 | 2 | 2 | GND | Connected |
| C2 | 1 | 1 | 3V3_AUX | Connected |
| C2 | 2 | 2 | GND | Connected |
| C3 | 1 | 1 (positive +) | 3V3_AUX | Connected |
| C3 | 2 | 2 (negative -) | GND | Connected |
| C4 | 1 | 1 (positive +) | 3V3_AUX | Connected |
| C4 | 2 | 2 (negative -) | GND | Connected |
| C5 | 1 | 1 | +5V_EXT | Connected |
| C5 | 2 | 2 | GND | Connected |
| C6 | 1 | 1 (positive +) | +5V_EXT | Connected |
| C6 | 2 | 2 (negative -) | GND | Connected |
| C7 | 1 | 1 | 3V3_AUX | Connected |
| C7 | 2 | 2 | GND | Connected |
| C8 | 1 | 1 (positive +) | 3V3_AUX | Connected |
| C8 | 2 | 2 (negative -) | GND | Connected |
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

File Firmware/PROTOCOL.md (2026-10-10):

# ESP32 ⇄ Pi serial protocol

The ESP32 and Pi communicate through an intact USB data cable. Serial speed is 115200 baud, UTF-8, one line per message.

## Pi to ESP32 commands

| Command | Effect |
| --- | --- |
| `PING` | Checks that the bridge is alive. |
| `STATUS` | Reports radio and encoder detection. |
| `RADIO1:text` | Sends up to 31 bytes through radio 1. |
| `RADIO2:text` | Sends up to 31 bytes through radio 2. |
| `IR_NEC:00FF:12ED` | Transmits an NEC IR code. Address and command are hexadecimal. |
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

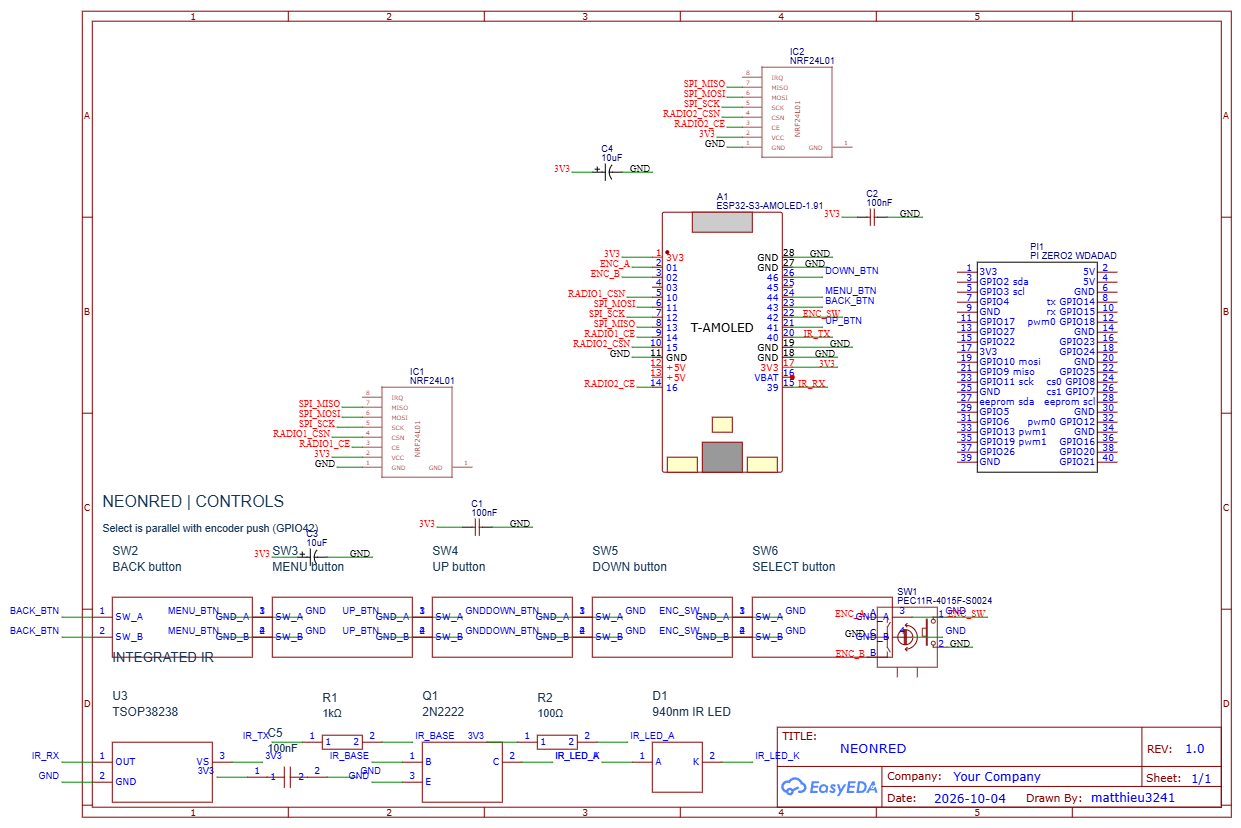
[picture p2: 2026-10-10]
PCB/screenshots/easyeda-neonred-schematic-2026-10-09.png

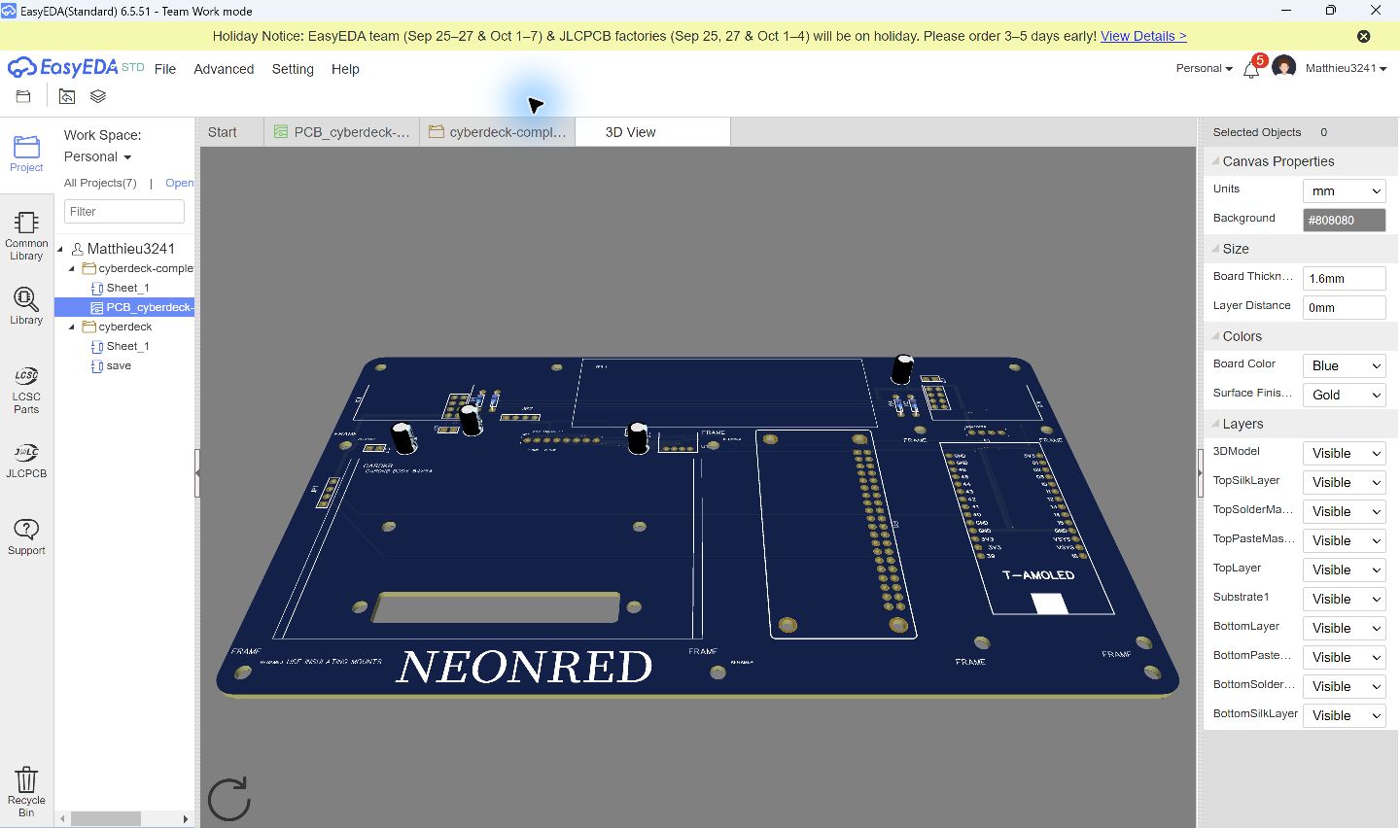
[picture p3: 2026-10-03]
PCB/screenshots/easyeda-current-3d-view.jpg

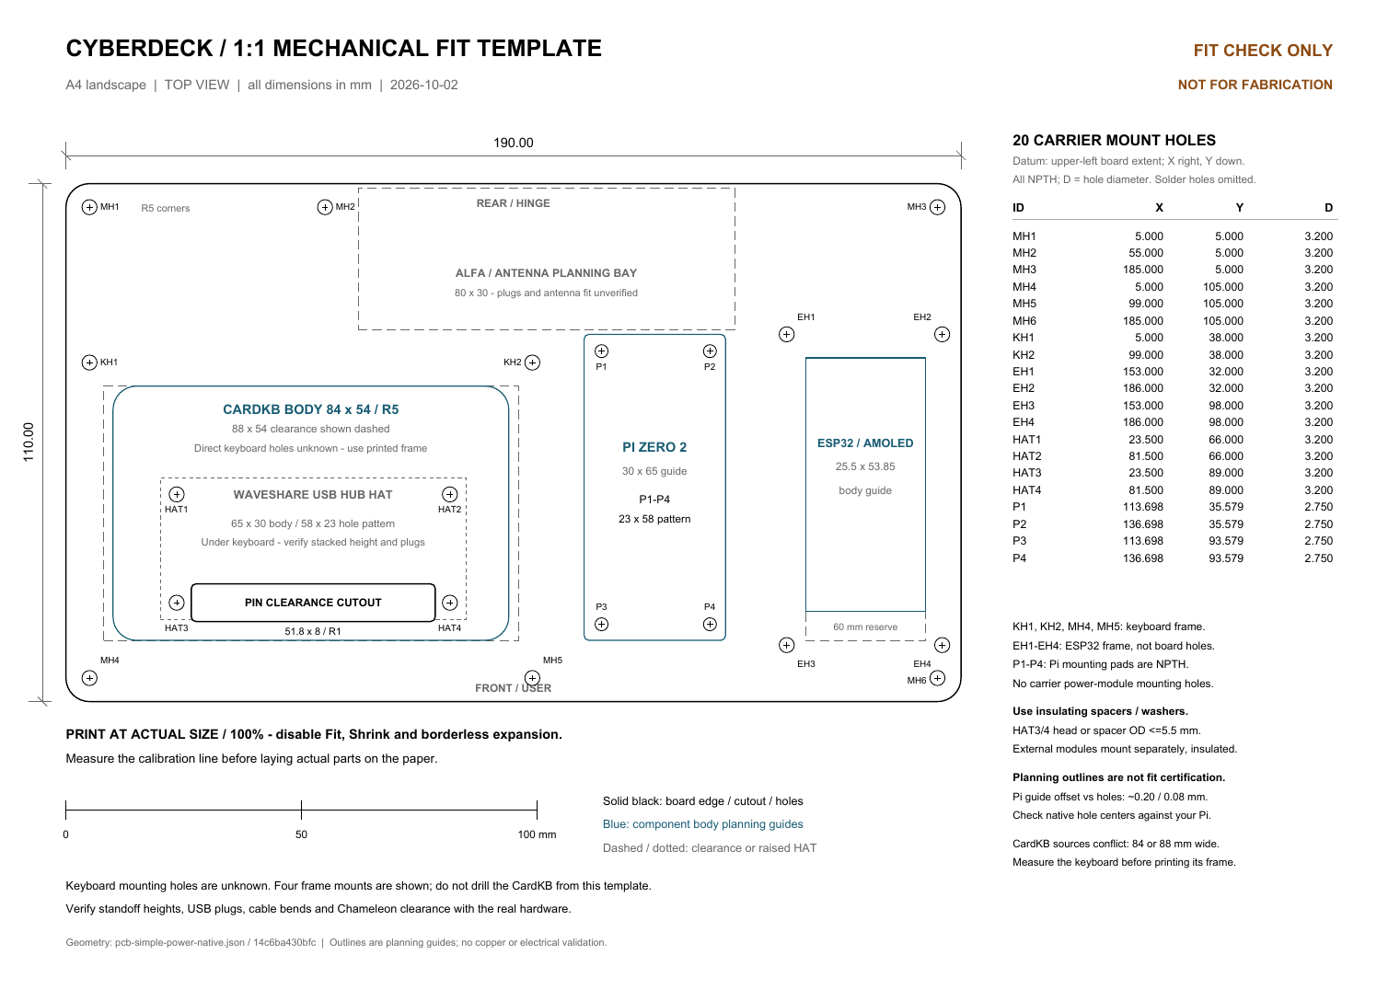
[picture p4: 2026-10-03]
PCB/screenshots/mounting-template-preview.png

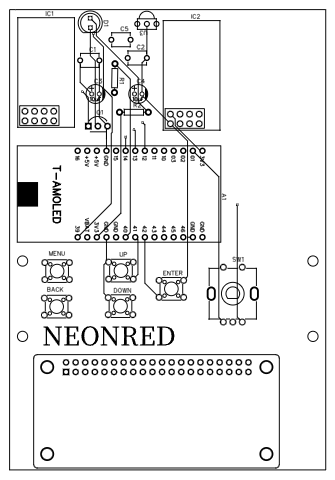
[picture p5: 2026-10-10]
PCB/screenshots/easyeda-neonred-pcb-2026-10-09.png

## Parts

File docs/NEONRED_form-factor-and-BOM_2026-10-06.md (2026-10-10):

# NEONRED portrait form factor and purchase BOM

This revision records the requested smaller, portrait-oriented, custom stepped board concept. It leaves component placement open for the user. The companion SVG contains only detached ALFA and Chameleon size guides plus proposed case and retainer holes; it does not imply that any module has been positioned on the carrier. The Raspberry Pi outline is omitted because the Pi is already owned and has a real PCB outline.

## Form factor draft

- Proposed maximum envelope: **120 × 180 mm**, portrait. This is a smaller area than the previous 200 × 120 mm interim outline.
- Proposed silhouette: stepped shoulders near the upper left and lower right, with mostly straight edges elsewhere. Finalize the notches only after choosing external connector locations and screw access.
- The SVG shows a conceptual stepped silhouette, detached guides, and draft hole positions. It is not a fabrication outline and does not replace the saved EasyEDA PCB.
- ALFA AWUS036ACS body outline is nominally 55 × 25 mm; the RP-SMA connector and antenna/cable keepout extend beyond that body.
- The Chameleon Ultra SE3 listing does not provide a mechanical drawing. The 40 × 24 mm rectangle in the SVG is explicitly a placeholder, not a verified SE3 dimension.
- Each device guide has two draft Ø2.7 mm non-plated holes for a printed retainer/clip. These holes fasten the holder to the carrier; they do not go through the ALFA or Chameleon enclosure. Their coordinates must be finalized after measuring the real devices and designing the clips.
- Four draft Ø3.2 mm non-plated M3 case-mount holes are placed inside the board perimeter, outside the device areas, with a 7 mm copper/mechanical keepout. A hole cannot be physically outside the PCB edge; use edge tabs if the case geometry needs mounting points farther out.
- LILYGO, CardKB, display, USB hub, external connectors, and all actual mounting-hole locations still need exact-revision measurements before the envelope can become a final PCB.

## Power and battery choice

Keep the battery external and feed each main device from a normal USB output. Do not route the power bank's main current through the carrier PCB. The already-owned Miady banks can remain available for individual-device tests, but the recorded 5 V / 2.4 A output may not supply all deck loads at once. If one replacement bank is desired, the Anker A1384 20,000 mAh / 30 W is a candidate commercial regulated power bank; its internal charging circuitry means a separate bare-cell charger module is not needed. Confirm simultaneous-port output and measure peak current for the actual system before relying on one bank.

## Purchase list

`BOM_NEONRED_purchase-list_2026-10-06.csv` contains unowned required purchase items, current known costs, links, and TBD prices where the exact selection is unresolved. The conditional Anker replacement is excluded from the required subtotal. The owned Pi, LILYGO board, Waveshare hub, and Miady banks are intentionally absent from the purchase rows. The old BOM remains as historical project data.

Known-priced required items subtotal: **$181.52**. This excludes TBD passives/IR parts, the custom PCB quote, shipping/tax, and the conditional Anker power bank.

## Before fabrication

Measure the ALFA adapter and Chameleon, design the printed retainers, confirm the case screw locations against the enclosure, choose case-side I/O openings, place components inside the final silhouette, then run ERC/DRC. The new SVG and BOM are planning artifacts, not evidence that the board is fabrication-ready.

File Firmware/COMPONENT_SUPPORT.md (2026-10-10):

# Component software coverage

| Component | Connection | Current firmware support | Hardware-dependent work remaining |
| --- | --- | --- | --- |
| LILYGO T-Display-S3 AMOLED | Runs ESP32 firmware | PlatformIO scaffold and USB serial bridge | Confirm board revision and display library/pin configuration before adding UI. |
| CardKB | I²C address `0x5F`; planned on GPIO3/GPIO41 | Polls one-byte key events and sends JSON to Pi | CardKB is not present on the current schematic; verify its voltage and wiring before connecting. |
| PEC11R mechanical encoder | A/B on GPIO1/GPIO2, common C to GND; switch on GPIO42/GND | Polls quadrature and button state; internal pull-ups enabled on all three inputs | Verify rotation direction and contact numbering on the physical encoder. |
| Two nRF24L01+ radios | Shared SPI, separate CE/CSN | Initialises safely at minimum power and can send/receive 32-byte packets | Choose unique RF addresses/channels and measure regulated-rail current. |
| Adafruit 5990 IR transceiver | GPIO39 RX / GPIO40 TX | Receives decoded data and sends commanded NEC codes | Test with the real remote; add other protocols only after verifying them. |
| Raspberry Pi | ESP32 USB serial cable | Python bridge prints events and sends commands | Add a systemd service and user-interface integration after device testing. |
| Chameleon Ultra SE3 | BLE | Safe BLE discovery utility only | Verify exact firmware GATT UUIDs and documented command protocol before any connection or control. |
| HDMI display | Pi HDMI | Handled by Raspberry Pi OS | Confirm exact panel power/touch wiring and configure display rotation. |
| Waveshare USB HUB HAT | Pi USB host | No custom firmware required | Check the physical hub, cable, and USB enumeration. |
| ALFA USB Wi-Fi adapter | Pi USB | Handled by Raspberry Pi OS/driver | Install the matching driver and confirm legal, authorized use. |

Nothing in this scaffold enables impersonation, credential extraction, or access to networks, cards, tags, or IR-controlled devices without authorization. It is for owned hardware, basic interoperability, and bring-up tests.

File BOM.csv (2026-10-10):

Part | Quantity | Status | Unit_USD | Source | Role_or_note
Chameleon Ultra SE3 | 1 | Selected | 39.99 | https://shop.mtoolstec.com/product/chameleon-ultra-se3 | Required purchase: RFID/NFC development module; BLE protocol still needs verification
ATNSINC nRF24L01+ PA/LNA radio kit | 1 | Selected | 9.99 | https://www.amazon.com/dp/B08R9F11D1 | Two 2.4 GHz radios with antennas and regulator adapters
ELEGOO breadboard and component kit | 1 | Optional | 9.99 | https://www.amazon.com/dp/B01ERP6WL4 | Through-hole capacitors and resistors subject to fit check
ALFA AWUS036ACS USB Wi-Fi adapter | 1 | Selected | 26.97 | https://store.rokland.com/products/alfa-awus036acs-802-11ac-ac600-dual-band-wifi-usb-adapter-rp-sma | Pi USB dual-band Wi-Fi adapter
LILYGO T-Display-S3 AMOLED | 1 | Owned | 0 | https://github.com/Xinyuan-LilyGO/T-Display-S3-AMOLED | ESP32-S3 controller and local display; exact revision to confirm
Raspberry Pi Zero 2 W | 1 | Owned | 0 | https://www.raspberrypi.com/products/raspberry-pi-zero-2-w/ | Linux host; exact owned variant to confirm
Waveshare USB HUB HAT SKU12694 | 1 | Owned | 0 | https://www.waveshare.com/usb-hub-hat.htm | Four-port USB hub mounted beside Pi under keyboard
Waveshare 3.5 inch HDMI LCD SKU12824 | 1 | Removed_current_design | 0 | https://www.waveshare.com/3.5inch-hdmi-lcd.htm | Not part of current NEONRED version; the LILYGO AMOLED is the only planned display
M5Stack CardKB v1.1 | 1 | Selected | 7.95 | https://shop.m5stack.com/products/cardkb-mini-keyboard-programmable-unit-v1-1-mega8a | I2C keyboard through Adafruit level shifter
Miady 10000 mAh power-bank two-pack | 1 | Owned_but_not_suitable_for_single_input | 19.97 | https://www.amazon.com/dp/B0GQH1QHDH | Listed output up to 5V 2.4A; below Pi Zero recommended supply before the other deck loads
Adafruit BSS138 I2C level shifter 757 | 1 | Selected | 3.95 | https://www.adafruit.com/product/757 | CardKB 5 V to ESP32 3.3 V I2C level shifting
Adafruit I2C rotary encoder 5880 | 1 | Selected | 4.95 | https://www.adafruit.com/product/5880 | Case-mounted I2C encoder at planned address 0x36
Adafruit IR Remote Transceiver 5990 | 1 | Superseded_by_integrated_IR | TBD | https://www.adafruit.com/product/5990 | Do not purchase for the revised design; recreate receiver and LED driver functions on carrier PCB
Pololu D24V10F3 step-down regulator 2830 | 1 | Selected | 9.95 | https://www.pololu.com/product/2830 | External preassembled 3.3 V peripheral regulator; measure load and temperature
100 nF through-hole capacitors | 4 | Required | 0 | https://www.digikey.com/en/products/detail/kemet/C315C104K5R5TA/12701330 | C1 C2 C5 C7; use kit parts only if physical pitch fits
10 uF through-hole electrolytic capacitors | 4 | Required | 0 | https://www.digikey.com/en/products/detail/panasonic-industry/EEA-GA1V100/2504583 | C3 C4 C6 C8; pad 1 positive
10 kOhm axial resistors | 4 | Required | 0 | https://www.digikey.com/ | R1 R2 R3 R4; select lead pitch to fit PCB
M2.5 nylon standoff kit | 1 | Selected | 9.99 | https://www.amazon.com/dp/B0FPMC9917 | Pi and HAT support with electrical insulation
M3 standoff and screw kit | 1 | Selected | 9.99 | https://www.amazon.com/dp/B0FBMFBQHQ | Carrier and frame hardware; use insulating washers where metal can contact copper
Mini-HDMI to HDMI cable | 1 | Removed_current_design | 0 | https://www.adafruit.com/product/2775 | Not needed in the current no-HDMI design
USB-A to micro-USB data cable | 1 | Required | 2.95 | https://www.adafruit.com/product/898 | Pi USB host to Waveshare HUB HAT data connection
USB-C data and power cables | 2 | Superseded_by_panel_ports | 4.95 | https://www.adafruit.com/product/4474 | Previous separate-cable proposal; use the 2026-10-06 port revision instead
Pi Zero adapter kit | 1 | If_needed | 6.95 | https://www.pishop.us/product/raspberry-pi-zero-adapter-kit/ | Only if needed for USB service/cabling after fit check; no mini-HDMI display is planned
Custom 190x110 mm carrier PCB | 1 | To_quote | TBD | https://jlcpcb.com/ | Order only after physical fit check and final Gerber export
3D printed enclosure | 1 | To_quote | TBD | local CAD source | Print only after Fusion assembly and physical fit checks
Proxmark3 RDV4 complete instrument | 1 | Candidate_unverified | TBD | https://proxmark.com/proxmark-3-hardware/proxmark-3-rdv4/ | Mount the complete removable USB instrument; choose exact model and measure its LF/HF antenna keepouts before PCB changes
RTL-SDR Blog V4 USB receiver | 1 | Candidate_unverified | TBD | https://www.rtl-sdr.com/wp-content/uploads/2024/12/RTLSDR_V4_Datasheet_V_1_0.pdf | External USB-A receiver with SMA input; 250-270 mA typical; receive-only; vendor announced end of life | verify availability
X/K/Ka radar-band block downconverters | 1 set | Design_required | TBD | https://github.com/rayhe/sdr-radar-detector | Required to translate radar-band signals into the RTL-SDR V4 tuning range; choose and validate bands/IF before purchase
ESP32 external 2.4 GHz antenna plus RF pigtail/connector | 1 | Pending_board_revision | TBD | https://github.com/Xinyuan-LILYGO/LilyGo-AMOLED-Series | Only add if the exact owned LILYGO board has a documented switchable antenna feed; connector and antenna model TBD
USB-C PD sink / 5 V input module | 1 | Design_required | TBD |  | External system power input; must negotiate 5 V, include CC handling, and be rated for the measured full-deck load
Higher-capacity 5 V system source or USB-PD source plus 5 V converter | 1 | Design_required | TBD |  | Replacement for the listed Miady bank in single-input mode; select only after peak-load measurement and confirmed 5 V power-path design
Main latching master switch | 1 | Design_required | TBD |  | Panel switch after input protection; must interrupt every switched power branch; rating TBD from measured current
Main input fuse or electronic current limiter | 1 | Design_required | TBD |  | Immediately after USB-C sink; select rating from measured load and lowest cable/connector/trace rating
Protected 5 V branch protection | 4 | Design_required | TBD |  | Select branches only after locking the power architecture and measuring peak current; values TBD
USB-C panel-mount data extension for LILYGO | 1 | Design_required | TBD |  | Native USB D+/D- to exterior; isolate computer VBUS from system 5 V; validate VBUS detect on exact LILYGO revision
Micro-USB panel-mount OTG extension for Pi | 1 | Design_required | TBD |  | External Pi Zero OTG service port; Pi remains powered from switched PWR IN branch
USB 2.0 break-before-make HAT/PC selector | 1 | Design_required | TBD |  | Select Waveshare HAT or external Pi OTG service host; never parallel USB hosts or VBUS sources
Tactile momentary through-hole buttons | 2 | Design_required | TBD |  | Back and Menu; normally-open to ground with ESP32 internal pull-ups; encoder remains Select/scroll
38 kHz IR receiver | 1 | Design_required | TBD |  | Through-hole demodulating sensor at left case opening; exact package and optical clearance TBD
940 nm IR emitter LEDs | 2 | Design_required | TBD |  | Through-hole pair at left case opening; driven by transistor/FET stage, not ESP32 GPIO
IR emitter driver and current-limit parts | 1 | Design_required | TBD |  | Through-hole driver, gate/base resistors and LED current limiting; values set from chosen LEDs and supply after review

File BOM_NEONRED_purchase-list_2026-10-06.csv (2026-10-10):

Item | Qty | Status | Unit_USD | Line_USD | Product_URL | Notes
Chameleon Ultra SE3 | 1 | Required | 39.99 | 39.99 | https://shop.mtoolstec.com/product/chameleon-ultra-se3 | RFID/NFC module; physical outline not published by vendor so measure before designing its cradle
nRF24L01+ PA/LNA two-module kit with antennas | 1 kit | Required | 9.99 | 9.99 | https://www.amazon.com/dp/B08R9F11D1 | Kit price; confirm it contains two modules and antennas before order
ALFA AWUS036ACS Wi-Fi adapter | 1 | Required | 26.97 | 26.97 | https://store.rokland.com/products/alfa-awus036acs-802-11ac-ac600-dual-band-wifi-usb-adapter-rp-sma | 55 x 25 x 10 mm body; reserve extra area for antenna connector and cable/antenna bend
Waveshare 3.5-inch HDMI LCD SKU12824 | 1 | Required | 35.99 | 35.99 | https://www.waveshare.com/3.5inch-hdmi-lcd.htm | Confirm exact revision and connector envelope before making lid/window
M5Stack CardKB v1.1 | 1 | Required | 7.95 | 7.95 | https://shop.m5stack.com/products/cardkb-mini-keyboard-programmable-unit-v1-1-mega8a | Nominal board 88 x 54 x 5 mm; verify connector and screw details
Adafruit BSS138 I2C level shifter 757 | 1 | Required | 3.95 | 3.95 | https://www.adafruit.com/product/757 | For the 5 V CardKB to 3.3 V ESP32 I2C interface
Adafruit I2C rotary encoder 5880 | 1 | Required | 7.95 | 7.95 | https://www.digikey.com/en/products/detail/adafruit-industries-llc/5880/22596384 | Current list price; panel mount and connect by I2C
Pololu D24V10F3 3.3 V regulator 2830 | 1 | Required | 9.95 | 9.95 | https://www.pololu.com/product/2830 | Separate peripheral supply only; validate total peripheral current and thermal load
100 nF through-hole ceramic capacitor | 4 | Required | TBD | TBD | https://www.digikey.com/en/products/detail/kemet/C315C104K5R5TA/12701330 | One per nRF radio plus remaining schematic bypass positions; select lead pitch to match footprints
10 uF through-hole electrolytic capacitor | 4 | Required | TBD | TBD | https://www.digikey.com/en/products/detail/panasonic-industry/EEA-GA1V100/2504583 | Observe polarity; verify voltage rating and lead pitch
10 kOhm axial resistor | 4 | Required | TBD | TBD | https://www.digikey.com/ | Only if retained by final reviewed schematic; confirm each function/value before order
Through-hole 38 kHz IR receiver | 1 | Required | TBD | TBD | https://www.adafruit.com/product/157 | Integrate on carrier; package/pinout to be matched to the chosen receiver datasheet
940 nm IR emitter LED | 2 | Required | TBD | TBD | https://www.digikey.com/ | Choose pulse-current-rated parts; drive through transistor/MOSFET and current-limit resistor | not directly from ESP32 GPIO
IR LED driver transistor plus base/gate resistor and LED current-limit resistors | 1 set | Required | TBD | TBD | https://www.digikey.com/ | Through-hole where practical; finalize values after choosing LED and 3.3 V supply
M2.5 nylon standoff/screw kit | 1 | Required | 9.99 | 9.99 | https://www.amazon.com/dp/B0FPMC9917 | For Pi and USB hub supports; verify screw lengths and board thickness
M3 standoff/screw kit | 1 | Required | 9.99 | 9.99 | https://www.amazon.com/dp/B0FBMFBQHQ | For carrier/frame mounting; use clearance from copper and module-specific hole pattern
Mini-HDMI to HDMI cable | 1 | Required | 5.95 | 5.95 | https://www.adafruit.com/product/2775 | Pi to Waveshare display; choose length after hinge path is known
USB-A to micro-USB data cable | 1 | Required | 2.95 | 2.95 | https://www.adafruit.com/product/898 | Pi USB host to owned Waveshare USB hub; confirm connector orientation and length
USB-C data/power cable | 2 | Required | 4.95 | 9.90 | https://www.adafruit.com/product/4474 | For owned LILYGO and service/power as needed; confirm cable data capability
Custom carrier PCB | 1 | Required | TBD | TBD | https://jlcpcb.com/ | New custom portrait outline; quote only after component placement | mechanical fit | and final DRC
Commercial 5 V USB power bank 20 | 000 mAh / 30 W (Anker A1384) | 1 | Conditional replacement | 49.99 | EXCLUDED | https://www.bestbuy.com/product/anker-power-bank-20000mah-30w-black/6587880?cmp=RMX | Use only if replacing owned Miady packs with one bank; external regulated USB source | no separate Li-ion charger module needed

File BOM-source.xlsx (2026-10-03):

ESP32 + SE3 PROJECT BOM
USD. Existing prices: Sep 28/30, 2026; new modules/cable/knob: Oct 2, 2026. Tax/shipping excluded; TBD costs remain.
Priced selected hardware | $188.59 |  |  |  |  | Includes assembled peripheral regulator, level shifter and encoder. Priced subtotal only; required unpriced items remain below.
Priced if-needed accessories | $30.27 |  |  |  |  | SE3 replaces PN532 / PN532Killer in this build.
Priced selected + if-needed | $218.86 |  |  |  |  | Incomplete budget: excludes TBD axial resistors, headers/harness, inline USB switch, peripheral wiring, insulating hardware, LCD lead and Pi-to-HAT data cable. Owned HAT adds no purchase cost.
Priced optional extras | $69.48 |  |  |  |  | Qty is the listed purchase unit. Optional knob is separate; included kit components are $0. Unpriced optional wiring is excluded.
Priced total of listed parts | $288.34 |  |  |  |  | Door-fob technology is unknown; compatibility must be checked.
Part / purchase unit | Qty | Status | Unit USD | Line USD | Price basis | Role / compatibility notes | Source
Chameleon Ultra SE3 | 1 | Selected | $39.99 | $39.99 | Listed 2026-09-28 | 125 kHz LF + 13.56 MHz HF; ESP32 control over BLE. Built-in antennas, battery and case. | MTools Tec — SE3 (https://shop.mtoolstec.com/product/chameleon-ultra-se3)
ATNSINC radio kit: 2 radios + antennas + adapters | 1 | Selected | $9.99 | $9.99 | Listed 2026-09-28 | One kit contains 2 nRF24L01+ PA/LNA radios, 2 SMA 2.4 GHz antennas and 2 regulator adapters. Amazon seller: Atnsinc. These are not full Bluetooth adapters. | Amazon - Atnsinc radio kit (https://www.amazon.com/dp/B08R9F11D1)
Regulated 3.3 V nRF24 adapter | 2 | Selected | $0.00 | $0.00 | Included in row 12 | Included radio regulator adapters are spare kit parts. Radios use the external Pololu-regulated 3V3_AUX rail in this design; do not parallel regulator outputs. No additional adapter purchase. | Included - ATNSINC kit (https://www.amazon.com/dp/B08R9F11D1)
Required PCB capacitors (from ELEGOO kit) | 1 | Selected | $0.00 | $0.00 | Included in row 15 | Use 4 x 100 nF (C1/C2/C5/C7) and 4 x 10 uF (C3/C4/C6/C8). Kit includes 10 and 5 respectively; measure lead pitch/body before soldering. No 100 uF required. Matched replacements in rows 32-33 only if needed. | Included - ELEGOO kit (https://www.amazon.com/dp/B01ERP6WL4)
ELEGOO 235-piece breadboard + component kit | 1 | Optional | $9.99 | $9.99 | Listed 2026-09-28 | One kit with solderless breadboard, jumper/Dupont wires, capacitors and assorted parts. Sold by ELEGOO Official US on Amazon. | Amazon - ELEGOO Official US (https://www.amazon.com/dp/B01ERP6WL4)
ALFA AWUS036ACS USB Wi-Fi adapter + antenna | 1 | Selected | $26.97 | $26.97 | Listed 2026-09-28 | 2.4 + 5 GHz Wi-Fi; detachable antenna included. RTL8811AU Linux monitor mode with compatible driver. Connect to Pi via micro-USB OTG. | Rokland — ALFA AWUS036ACS (https://store.rokland.com/products/alfa-awus036acs-802-11ac-ac600-dual-band-wifi-usb-adapter-rp-sma)
LILYGO T-Display-S3 AMOLED | 1 | Owned | $0.00 | $0.00 | Already owned | Built-in BLE + 2.4 GHz Wi-Fi, display and buttons. No separate BLE module needed; verify pin mapping. | Your Amazon board (https://www.amazon.com/dp/B0C2T6DP5J)
Raspberry Pi Zero 2 (variant to confirm) | 1 | Owned | $0.00 | $0.00 | Already owned | Owned Linux host for display and USB Wi-Fi. Seller link is a Zero 2 W reference; confirm your exact variant. Additional cost remains $0. | PiShop - Zero 2 W reference (https://www.pishop.us/product/raspberry-pi-zero-2-w/)
USB-C data / power cable | 2 | If needed | $4.95 | $9.90 | Listed 2026-09-28 | Intact USB-A to USB-C cables for ESP32 power/programming and Chameleon as needed. Main-device power stays off the carrier; do not cut these into PCB pigtails. Reuse owned cables if suitable. | Adafruit - USB-C data cable (https://www.adafruit.com/product/4474)
Timeskey NTAG215 adhesive tags - 20-pack | 1 | Optional | $6.90 | $6.90 | Listed 2026-09-28 | One pack of 20 white 25 mm adhesive tags. NTAG215, 504 bytes. Sold by TimesKey-US on Amazon. Ordinary NFC writing tests; avoid metal surfaces. | Amazon - TimesKey-US (https://www.amazon.com/dp/B0CPJ3XCMR)
ETEKJOY T5577 blank LF fobs - 10-pack | 1 | Optional | $7.99 | $7.99 | Listed 2026-09-28 | One pack of 10 blue blank writable 125 kHz T5577 fobs. Sold by ETEKJOY. For compatible LF formats; these are not 13.56 MHz NFC tags. | Amazon - ETEKJOY (https://www.amazon.com/dp/B07GBSP8SD)
Gialer Classic 1K-compatible cards - 10-pack | 1 | Optional | $9.99 | $9.99 | Listed 2026-09-28 | One pack of 10 Fudan FM11RF08 cards, sold by smacarte. Classic 1K-compatible 13.56 MHz test cards, not NXP-branded. Standard UID is not freely rewritable. | Amazon - smacarte / Gialer (https://www.amazon.com/dp/B09BW4R8NS)
Waveshare 3.5-inch HDMI LCD (SKU 12824) | 1 | Selected | $31.99 | $31.99 | Listed 2026-09-28 | HDMI LCD powered separately from a USB bank, with connector/pinout and suitable power lead still to confirm for the exact display. No carrier power output. HDMI video and SPI touch connections remain as specified. | Waveshare - 3.5in HDMI LCD (https://www.waveshare.com/3.5inch-HDMI-LCD.htm)
M5Stack CardKB v1.1 mini keyboard | 1 | Selected | $7.95 | $7.95 | Listed 2026-09-28 | CardKB v1.1: 5 V supply; ESP32 I2C through assembled Adafruit 757. Mechanical drawing: 84 x 54 mm; product table: 88 x 54 x 5 mm. Reserve 88 x 54; measure before printing the cradle. Grove cable included. | M5Stack — CardKB v1.1 (https://shop.m5stack.com/products/cardkb-mini-keyboard-programmable-unit-v1-1-mega8a)
Display + Pi power cables (details below) | 1 | If needed | $8.90 | $8.90 | 2 items; see rows 45-46 | Mini-HDMI cable plus intact micro-USB Pi power cable (rows 45-46). Pi power connects directly to a USB bank, not carrier pads. Reuse suitable owned cables; GPIO header is in row 29 kit. | Seller links - rows 45-46
Miady 10,000 mAh power banks — 2-pack | 1 | Selected | $19.97 | $19.97 | Listed 2026-09-28 | One pack = two 10,000 mAh / 37 Wh banks. Each bank: 5 V, 2.4 A TOTAL shared output limit, not per port. Use separate USB feeds; never parallel bank outputs. Combined load, auto-shutoff and runtime need bench validation. | Amazon — Miady 2-pack (https://www.amazon.com/dp/B0GQH1QHDH)
SanDisk Ultra 32 GB microSDHC card | 1 | Optional | $20.62 | $20.62 | Listed 2026-09-28 | One new 32 GB A1/Class 10 card. Amazon seller: eKings, fulfilled by Amazon. Optional if you already have a suitable card; OS installation required. | Amazon - eKings / SanDisk (https://www.amazon.com/dp/B08L5HMJVW)
Adafruit 5 V 2.5 A micro-USB power supply | 1 | Optional | $8.25 | $8.25 | Listed 2026-09-28 | Adafruit 1995, US plug and attached micro-USB cable. Optional bench supply. Battery remains the portable power source. | Adafruit - micro-USB supply (https://www.adafruit.com/product/1995)
Pi Zero adapter kit: OTG + GPIO header | 1 | If needed | $6.95 | $6.95 | Listed 2026-09-28 | PiShop K2B-1306: micro-USB OTG cable, 2x20 male GPIO header and mini-HDMI adapter. Header may need soldering. No extra OTG or header purchase needed. | PiShop - Zero adapter kit (https://www.pishop.us/product/raspberry-pi-zero-adapter-kit/)
ABS enclosure (candidate) | 1 | Optional | $4.99 | $4.99 | 1 item; see row 47 | One 200 x 120 x 75 mm box. Fit and cutouts are not finalized. M2.5 hardware is separately selected in row 34. | Seller link - row 47
EEEEE M3 brass standoff kit - 208 pieces | 1 | Selected | $9.99 | $9.99 | Listed 2026-09-30 | M3 fits carrier/frame 3.2 mm holes, not Pi. Kit lengths 6/10/15/20 mm. Use insulating washers/spacers beneath metal fastener surfaces. Confirm height and head/hex within 6 mm reserve; brass conducts. | Amazon - EEEEE M3 kit (https://www.amazon.com/dp/B0FBMFBQHQ)
100 nF radial X7R - KEMET C315C104K5R5TA | 4 | If needed | $0.79 | $3.16 | DigiKey 2026-09-30 | C1/C2/C5/C7: 100 nF, 50 V, 2.54 mm pitch, 3.81 x 2.54 mm max body. Buy only if ELEGOO capacitors do not fit; kit has 10. | DigiKey - KEMET 100 nF (https://www.digikey.com/en/products/detail/kemet/C315C104K5R5TA/12701330)
10 uF radial - Panasonic EEA-GA1V100 | 4 | If needed | $0.34 | $1.36 | DigiKey 2026-09-30 | C3/C4/C6/C8: 35 V, 105 C, 2 mm pitch; allow 5.5 mm dia x 8 mm height. + to pad 1; stripe to GND pad 2. Only if kit parts do not fit (5 included). | DigiKey - Panasonic 10 uF (https://www.digikey.com/en/products/detail/panasonic-industry/EEA-GA1V100/2504583)
AvrestYPT M2.5 nylon standoff kit - 365 pieces | 1 | Selected | $9.99 | $9.99 | Listed 2026-09-30 | M2.5 nylon hardware for Pi 2.75 mm and HAT 3.0 mm holes. HAT3/HAT4 head/hex/body OD <=5.5 mm beside header slot. Choose spacer height after measuring pins, USB plug and keyboard/Chameleon clearance. | Amazon - M2.5 nylon kit (https://www.amazon.com/dp/B0FPMC9917)
Adafruit IR Remote Transceiver (5990) | 1 | Selected | $5.95 | $5.95 | Listed 2026-09-28 | IR emitter/receiver remain off-board on wires at the left edge, powered by external regulated 3V3_AUX. Direct ESP32 signals; verify total radio/IR peak load and use common ground. Existing jumpers may be reused. | Adafruit - IR transceiver 5990 (https://www.adafruit.com/product/5990)
BUILD NOTES
Control link | ESP32 ↔ SE3 over BLE; dual nRF24 modules use SPI. Firmware and pin mapping still need integration.
Emulation scope | Supported card types only; encrypted credentials may require keys. A frequency match alone is insufficient.
Firmware reference | Chameleon Ultra firmware & documentation (https://github.com/RfidResearchGroup/ChameleonUltra)
ESP32 board reference | LILYGO T-Display-S3 AMOLED (https://github.com/Xinyuan-LilyGO/T-Display-S3-AMOLED)
Editing | Change quantities and unit prices to update totals. Status values: Owned, Selected, If needed, Optional.
Details below are included in rows 25, 30 and 34, not additional purchases.
Part / purchase unit | Qty | Included in | Unit USD | Line USD | Price basis | Role / compatibility notes | Source
Mini-HDMI to HDMI cable - 1.5 m | 1 | In row 25 | $5.95 | $5.95 | Listed 2026-09-28 | Adafruit 2775. Bench cable; final enclosure may need a shorter cable. | Adafruit - mini-HDMI cable (https://www.adafruit.com/product/2775)
USB-A to micro-USB cable - 6 inches | 1 | In row 25 | $2.95 | $2.95 | Listed 2026-09-28 | Adafruit 898 intact USB-A to micro-USB cable, counted only in row 25. USB-A to power bank, micro-USB to Pi PWR IN. No cut cable or carrier power pads. Keep Pi-HAT USB data cable separate. | Adafruit - micro-USB cable (https://www.adafruit.com/product/898)
Raculety ABS box - 200 x 120 x 75 mm | 1 | In row 30 | $4.99 | $4.99 | Sale 2026-09-28 | One box plus 4 cable glands. Seller: Raculety. Candidate only; custom cutouts and full-build fit require checking. Sale may expire. | Amazon - Raculety box (https://www.amazon.com/dp/B0DHKW8KFJ)
AvrestYPT M2.5 nylon standoff kit - 365 pieces | 1 | In row 34 | $9.99 | $9.99 | Listed 2026-09-30 | Counted in row 34 only. Four HAT spacers: head/hex/body OD <=5.5 mm by the slot; M2.5 screws. Measure height for underside pins and USB plug plus clearance to keyboard and Chameleon. | Amazon - AvrestYPT hardware (https://www.amazon.com/dp/B0FPMC9917)
RETAINED FOUR-PORT USB HAT
Part / purchase unit | Qty | Status | Unit USD | Line USD | Price basis | Role / compatibility notes | Source
Waveshare USB HUB HAT - 4 ports (SKU12694, owned) | 1 | Owned | TBD | TBD | Retained hardware; prior price unverified | Owned Waveshare USB HUB HAT: four USB ports, no Ethernet. Mount beneath keyboard beside Pi; upstream micro-USB data cable supplies HAT power from Pi. Do not add a parallel HAT 5 V supply. Keep measured slot/standoff clearances. | Waveshare USB HUB HAT (https://www.waveshare.com/usb-hub-hat.htm)
Short USB 2.0 micro-USB host/OTG-to-micro-USB data cable | 1 | If needed | TBD | TBD | Generic cable; product and price TBD | Pi USB/data port to HAT USB HUB input. All four power/data conductors; host/OTG-compatible Pi end. Length and plug orientation TBD after fit. Alternative: reuse the included USB-A-to-micro-USB cable with a micro-USB OTG adapter. Choose one solution only; no duplicate cable budget. Existing row46 remains the Pi power cable. | Waveshare USB HUB guide (https://www.waveshare.com/wiki/USB_HUB_HAT)
PERIPHERAL POWER AND ROTARY CONTROL
Part / purchase unit | Qty | Status | Unit USD | Line USD | Price basis | Role / compatibility notes | Source
Adafruit 5880 I2C QT encoder (assembled) | 1 | Selected | $7.95 | $7.95 | Adafruit 2026-10-02 | Case-mounted 25.4 x 25.4 mm module with push switch. I2C 0x36; ESP3V3 supply, GPIO1 SDA, GPIO41 SCL. Cable and knob sold separately. | Adafruit - encoder 5880 (https://www.adafruit.com/product/5880)
Adafruit 4397 QT to female 2.54 mm cable | 1 | Selected | $0.95 | $0.95 | Adafruit 2026-10-02 | 150 mm cable to JP8 male header: 1 GND black; 2 ESP3V3 red; 3 SDA blue; 4 SCL yellow. Check orientation; provide strain relief. | Adafruit - QT cable 4397 (https://www.adafruit.com/product/4397)
Adafruit 5093 slim D-shaft knob | 1 | Optional | $0.75 | $0.75 | Adafruit 2026-10-02 | 11.5 mm diameter x 14.5 mm tall. Optional knob for the preassembled encoder; not included with 5880. | Adafruit - knob 5093 (https://www.adafruit.com/product/5093)
Pololu 2830 D24V10F3 assembled 3.3 V regulator | 1 | Selected | $12.95 | $12.95 | Pololu 2026-10-02 | External module: 5 V USB input to regulated 3V3_AUX for radios/IR; separate from ESP3V3. Typical 1 A is thermal-limited; combined peak load needs testing. Includes straight/right-angle headers. No loose SMD soldering. Backorders allowed. | Pololu - D24V10F3 (https://www.pololu.com/product/2830)
Adafruit 757 assembled I2C level converter | 1 | Selected | $3.95 | $3.95 | Adafruit 2026-10-02 | LV=ESP3V3, HV=+5V_EXT, common GND; two channels for CardKB. Built-in 10k pullups replace Q1/Q2 and R5-R8. Includes two 6-pin header strips needing through-hole soldering. Other channels unused. | Adafruit - level converter 757 (https://www.adafruit.com/product/757)
10 kohm axial through-hole resistor | 4 | Selected | TBD | TBD | Rating / quote TBD | R1-R4 radio CSN pullups and CE pulldowns; nominal 1/4 W, 1%. Confirm body and lead span fit the carrier. Use suitable owned parts; do not assume an optional kit purchase covers these required resistors. | Axial resistor selection pending
Male headers: 2 x 1x4 + 1 x 1x8, 2.54 mm | 1 | Selected | TBD | TBD | Generic / quote TBD | One >=16-pin strip/set for JP2 peripheral power, JP8 encoder and JP3 level-shifter harness. Reuse owned headers if suitable. Adafruit 757 includes its separate module headers; do not purchase those twice. | Carrier header set
Eight-conductor female jumper harness | 1 | Selected | TBD | TBD | Generic / quote TBD | JP3 1x8 to assembled 757: 1 GND, 2 ESP3V3, 3 +5V_EXT, 4 SDA_LV, 5 KB_SDA, 6 SCL_LV, 7 KB_SCL, 8 GND. Individual female ends may connect to the module two 6-pin strips. Verify order and strain relief. | Level-shifter harness
External inline USB 5 V power switch | 1 | Selected | TBD | TBD | Product / rating TBD | Peripheral supply only; not a Pi shutdown or all-device master. Select rating for measured input current. Direct SPI/IR and BSS138 do not isolate unpowered devices: power ESP/peripherals together or disconnect signal harness before separate powering. | Inline USB switch selection pending
USB-A power lead to peripheral 5 V/GND wiring | 1 | Selected | TBD | TBD | Product / rating TBD | Switched bank 5 V feeds CardKB and external Pololu VIN. JP2: 1 +5V_EXT, 2 GND, 3 regulated 3V3_AUX, 4 GND. Verify polarity, current rating and strain relief. Main Pi/ESP/display power cables stay intact and separate. | Peripheral power lead selection pending
Hookup wire + heatshrink / strain relief | 1 | If needed | TBD | TBD | Reuse / quote TBD | Low-voltage peripheral wiring and module harnesses only; secure and insulate the external regulator as needed. No main-device power pad pairs. Reuse suitable owned wire and insulation. | Wire / strain relief pending
M3 + M2.5 nylon washer / spacer assortment | 1 | Selected | TBD | TBD | Size / quote TBD | Insulate metal fastener contacts on both PCB faces, including Pi, keyboard and ESP32 frame mounts. HAT3/HAT4 washer/spacer/head/body OD <=5.5 mm. Cover the metal contact area and confirm insulation thickness and fit. | Insulating hardware selection pending
LCD external USB-source power lead | 1 | If needed | TBD | TBD | Connector / pinout TBD | Exact display power connector/pinout remains to confirm. Connect a suitable intact lead from the USB bank to the required display power input; no carrier distribution. Reuse included/owned lead if confirmed. HDMI remains separate. | Waveshare - LCD reference (https://www.waveshare.com/3.5inch-HDMI-LCD.htm)

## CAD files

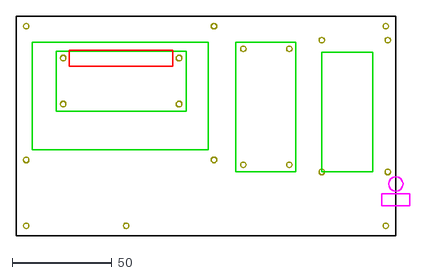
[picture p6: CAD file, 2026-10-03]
cad/Cyberdeck_Fusion_Layout.dxf
197.0 x 110.0

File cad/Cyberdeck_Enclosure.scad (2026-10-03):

/*
  Cyberdeck enclosure - revision 1
  Units: millimetres.  Designed around the saved 190 x 110 mm carrier PCB.

  Export one printable part at a time by changing `part` below.  "assembly" is
  a visual fit-check model; the coloured electronics are envelopes, not parts
  to print.  This model intentionally keeps uncertain connector dimensions as
  editable parameters at the top of the file.
*/

part = "assembly"; // [assembly,base_shell,service_tray,lid,keyboard_frame,esp32_cradle,chameleon_sled,antenna_pivot,battery_hook]
$fn = 48;

// ---- Manufacturing and case geometry ----
wall = 3;
floor_t = 2.4;
clearance = 0.35;
outer = [204,124];
corner_r = 8;
base_h = 42;              // 39.6 mm clear above the removable tray
lid_h = 10;
tray_origin = [3.4,3.4];
tray_size = [197.2,117.2];
tray_z = 0;               // raise only after a physical Chameleon test

// Saved carrier geometry.  Coordinates are measured from the PCB lower-left.
pcb = [190,110,1.6];
pcb_origin = [7,7];
pcb_standoff_h = 5;
hat_separator_h = 1;
pcb_mounts = [
  [5,5], [55,5], [185,5], [5,105], [99,105], [185,105],
  [5,38], [99,38], [153,32], [186,32], [153,98], [186,98],
  [23.5,66], [81.5,66], [23.5,89], [81.5,89]
];
pi_mounts = [[113.6983,35.5788],[136.6982,35.5788],[113.6983,93.5789],[136.6982,93.5789]];
hat_mounts = [[23.5,66],[81.5,66],[23.5,89],[81.5,89]];
hat_slot = [26.6,85,51.8,8];

// Confirmed planning envelopes.  Change only from a physical measurement.
keyboard_xy = [8,43];
keyboard_size = [88,54];
keyboard_h = 6.3;
pi_xy = [110,32];
pi_size = [30,65];
hat_xy = [20,62.5];
hat_size = [65,30];
lily_xy = [153,32];
lily_size = [25.5,60];
lily_window = [23,47];
lcd_board = [85.01,56.41];
lcd_view = [74,50];       // conservative aperture; verify against the panel
lcd_xy = [16,34];
chameleon_size = [40,24,8]; // adjustable SE3 envelope, not a manufacturer drawing
chameleon_xy = [40,52];     // lives below the service tray, under the keyboard
battery_size = [96,64,26];  // Miady AS-TPB21 manual dimensions; verify the owned bank

// ---- Basic shapes ----
module rr2d(s, r) {
  offset(r=r) offset(delta=-r) square(s, center=false);
}

module rr_box(s, r, h) {
  linear_extrude(height=h) rr2d(s, r);
}

module m25_hole(h=20) {
  cylinder(d=2.8, h=h, center=false);
}

module standoff(h, od=6.2, hole=2.8) {
  difference() {
    cylinder(d=od, h=h);
    translate([0,0,-0.1]) cylinder(d=hole, h=h+0.2);
  }
}

module board_xy(p) { translate([pcb_origin[0]+p[0], pcb_origin[1]+p[1], 0]) children(); }

module tray_xy(p) { translate([pcb_origin[0]+p[0]-tray_origin[0], pcb_origin[1]+p[1]-tray_origin[1], 0]) children(); }

// ---- Base and removable service tray ----
module base_shell() {
  difference() {
    rr_box([outer[0],outer[1]], corner_r, base_h);
    translate([wall,wall,floor_t]) rr_box([outer[0]-2*wall,outer[1]-2*wall], corner_r-wall, base_h);
    // bottom opening lets the service tray and all electronics come out together
    translate([tray_origin[0],tray_origin[1],-0.1]) rr_box(tray_size, corner_r-wall, floor_t+0.2);
    // left-side IR optical opening; the IR module itself is wired, not PCB-mounted.
    translate([-0.1,84,21]) rotate([0,90,0]) cube([10,10,wall+0.2]);
    // right-front rotary encoder panel hole and rectangular peripheral power-switch opening.
    translate([188,108,-0.1]) cylinder(d=7.2,h=base_h+0.2);
    translate([145,103,-0.1]) cube([14,6,base_h+0.2]);
    // cable exits with removable grommets; open only after connector measurement.
    translate([198.8,38,9]) cube([6,18,12]);
    translate([86,-0.1,9]) cube([38,6,12]);
  }
  // tray support rail inside the lower shell
  difference() {
    translate([tray_origin[0]-0.8,tray_origin[1]-0.8,0]) rr_box([tray_size[0]+1.6,tray_size[1]+1.6],corner_r-wall,2.0);
    translate([tray_origin[0]+1.0,tray_origin[1]+1.0,-0.1]) rr_box([tray_size[0]-2.0,tray_size[1]-2.0],corner_r-wall,2.2);
  }
  // Hinge ears.  Use a 2.5 mm steel pin or M2.5 shoulder screw after printing a test pair.
  for (x=[18,95,172]) {
    translate([x,-2,base_h-7]) rotate([90,0,0]) difference() {
      cylinder(d=12,h=6);
      translate([0,0,-0.1]) cylinder(d=2.8,h=6.2);
    }
  }
}

module service_tray() {
  difference() {
    rr_box(tray_size, corner_r-wall, floor_t);
    // continued clearance under the HAT's 2x20 underside connector
    tray_xy([hat_slot[0],hat_slot[1]]) translate([0,0,-0.1]) rr_box([hat_slot[2],hat_slot[3]],1,floor_t+0.2);
    // thin bottom RF window below the Chameleon sled; make it solid if range testing dislikes it.
    translate([chameleon_xy[0]-tray_origin[0]-2,chameleon_xy[1]-tray_origin[1]-2,-0.1]) rr_box([chameleon_size[0]+4,chameleon_size[1]+4],2,1.2);
    // Four countersunk access screws are deliberately outside the carrier PCB outline.
    for (p=[[5,5],[192,5],[5,112],[192,112]]) translate([p[0],p[1],-0.1]) m25_hole(floor_t+0.2);
  }
  // Carrier support posts.  These pass through its non-plated mechanical holes only.
  for (p=pcb_mounts) tray_xy(p) translate([0,0,floor_t]) standoff(pcb_standoff_h);
  // The Pi has a separate set of taller supports above the carrier.
  for (p=pi_mounts) tray_xy(p) translate([0,0,floor_t+pcb_standoff_h+pcb[2]]) standoff(6,5.6,2.6);
  // HAT support posts stop at the carrier; nylon spacers sit between the carrier and HAT.
  for (p=hat_mounts) tray_xy(p) translate([0,0,floor_t+pcb_standoff_h+pcb[2]]) standoff(hat_separator_h,5.6,2.6);
  cable_channels();
}

module cable_channels() {
  // Raised walls guide cables along the rear hinge path and away from screw heads.
  translate([20,6,floor_t]) cube([105,1.8,4]);
  translate([18,8,floor_t]) cube([1.8,35,4]);
  translate([140,8,floor_t]) cube([1.8,28,4]);
  // Tie slots accept small fabric ties; do not crush HDMI or USB cables.
  for (p=[[28,12],[116,12],[148,20]])
    translate([p[0],p[1],floor_t]) difference() {
      cube([8,3,3]);
      translate([2,0.5,-0.1]) cube([4,2.1,3.2]);
    }
}

// ---- User-facing top pieces ----
module keyboard_frame() {
  frame_xy = [pcb_origin[0]+keyboard_xy[0]-4, pcb_origin[1]+keyboard_xy[1]-4];
  frame_size = [keyboard_size[0]+8, keyboard_size[1]+8];
  difference() {
    translate([frame_xy[0],frame_xy[1],0]) rr_box(frame_size,4,3);
    translate([pcb_origin[0]+keyboard_xy[0]-clearance,pcb_origin[1]+keyboard_xy[1]-clearance,-0.1])
      rr_box([keyboard_size[0]+2*clearance,keyboard_size[1]+2*clearance],2,3.2);
    // Two saved carrier frame holes and two case-only front supports.
    for (p=[[5,38],[99,38],[5,105],[99,105]]) board_xy(p) translate([0,0,-0.1]) m25_hole(3.2);
  }
  // lip keeps the keyboard from moving sideways; it does not assume keyboard screw holes.
  for (p=[[pcb_origin[0]+keyboard_xy[0]-1,pcb_origin[1]+keyboard_xy[1]-1],
          [pcb_origin[0]+keyboard_xy[0]+keyboard_size[0]-1,pcb_origin[1]+keyboard_xy[1]-1],
          [pcb_origin[0]+keyboard_xy[0]-1,pcb_origin[1]+keyboard_xy[1]+keyboard_size[1]-1],
          [pcb_origin[0]+keyboard_xy[0]+keyboard_size[0]-1,pcb_origin[1]+keyboard_xy[1]+keyboard_size[1]-1]])
    translate([p[0],p[1],3]) cube([2,2,2]);
}

module esp32_cradle() {
  o = [pcb_origin[0]+lily_xy[0]-4,pcb_origin[1]+lily_xy[1]-4];
  s = [lily_size[0]+8,lily_size[1]+8];
  difference() {
    translate([o[0],o[1],0]) rr_box(s,4,3);
    translate([pcb_origin[0]+lily_xy[0]-clearance,pcb_origin[1]+lily_xy[1]-clearance,-0.1]) rr_box([lily_size[0]+2*clearance,lily_size[1]+2*clearance],2,3.2);
    for (p=[[153,32],[186,32],[153,98],[186,98]]) board_xy(p) translate([0,0,-0.1]) m25_hole(3.2);
  }
  // side rails grip the board edge, leaving the USB-C end and reset/boot controls clear.
  translate([pcb_origin[0]+lily_xy[0]-1,pcb_origin[1]+lily_xy[1]+5,3]) cube([1.5,lily_size[1]-10,4]);
  translate([pcb_origin[0]+lily_xy[0]+lily_size[0]-0.5,pcb_origin[1]+lily_xy[1]+5,3]) cube([1.5,lily_size[1]-10,4]);
}

module chameleon_sled() {
  // Under-tray rail sled.  Mount with VHB or a removable fabric strap after confirming SE3 dimensions.
  s = [chameleon_size[0]+4,chameleon_size[1]+4];
  p = [chameleon_xy[0]-tray_origin[0],chameleon_xy[1]-tray_origin[1]];
  translate([p[0],p[1],0]) difference() {
    rr_box(s,3,2);
    translate([2,2,-0.1]) rr_box([chameleon_size[0],chameleon_size[1]],2,2.2);
  }
  translate([p[0],p[1]+2,2]) cube([2,chameleon_size[1],5]);
  translate([p[0]+chameleon_size[0]+2,p[1]+2,2]) cube([2,chameleon_size[1],5]);
}
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

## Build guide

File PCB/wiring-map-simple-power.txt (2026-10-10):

CYBERDECK SIMPLE POWER WIRING MAP — HISTORICAL (2026-10-03)
==========================================
SUPERSEDED by docs/POWER_AND_IO_REVISION_2026-10-06.md. This file describes the earlier peripheral-only switch and separate device power; it does not include the requested master switch, USB-C system input, external USB service ports, navigation buttons, or integrated IR. Do not build from it as the current revision.
NATIVE_EXPORT_ASSIGNMENTS_VERIFIED
Generated: 2026-10-03T04:33:28.627593+00:00
21 components | 132 electrical pins | 17 nets | 77 connected | 55 NC

SOURCE FILES AND SHA-256
outputs/schematic-simple-power-native.json: 1861b7872267eff313ba5267874894d55dfa8f3b06d74e385273eb774742225c
outputs/pcb-simple-power-native.json: 14c6ba430bfcb49659fa3ca9d57fee9c3092dd0da13f206e33ee1388b886b47c
work/simple-peripherals-component-map.json: 58d2b779711a2a97318d4067444a9b429520f63a5a96270ed082f26117d4516f

CURRENT ASSEMBLY AND FIRMWARE NOTES
1. Approved simplified architecture: main devices receive individual external power connections. No Pi, LILYGO, LCD or Chameleon main power travels through this carrier. Use one power source per device; never parallel USB 5 V outputs.
2. JP2 peripheral supply: 1 +5V_EXT, 2 GND, 3 3V3_AUX, 4 GND. A regulated USB 5 V source feeds CardKB and the VIN of an external preassembled Pololu D24V10F3 #2830. Its regulated 3.3 V output feeds JP2.3. Do not swap either voltage or connect a bare battery cell.
3. ESP3V3 remains separate from 3V3_AUX. Grounds are common. Both LILYGO VSYS contacts and all 40 Pi header contacts remain NC. The Pi powers its retained HAT through its USB host connection; do not independently backfeed HAT power.
4. JP3 is an eight-pin harness to the preassembled Adafruit #757 I2C level shifter: 1 GND, 2 ESP3V3/LV, 3 +5V_EXT/HV, 4 SDA_LV/A1, 5 KB_SDA/B1, 6 SCL_LV/A2, 7 KB_SCL/B2, 8 GND. A/B are matched channels, not carrier component reference A1. Unused module channels remain unconnected. This is not the module physical footprint.
5. JP8 encoder: 1 GND, 2 ESP3V3, 3 SDA_LV, 4 SCL_LV. The assembled Adafruit5880 encoder uses I2C0x36; CardKB uses0x5F. Start with100kHz and check the assembled cable and parallel pullups.
6. R1-R4 are axial through-hole10k resistors. C1/C2/C5/C7 are through-hole100nF ceramic; C3/C4/C6/C8 are through-hole10uF electrolytic. Electrolytic pad1 is positive, pad2 GND. Q1/Q2 and R5-R8 are replaced by the assembled757; there are no loose SMD parts to hand-solder on the carrier.
7. Radio SPI: GPIO12SCK,11MOSI,13MISO; radio1GPIO10CSN/14CE; radio2GPIO15CSN/16CE. CardKB/encoderGPIO1SDA/41SCL. IR GPIO39RX/40TX. GPIO2,43,44 remain NC. No AUX_OE_N or translator-enable firmware remains.
8. Direct SPI/IR wires and the BSS138 keyboard converter are not power-off isolation. Use only with ESP and peripheral supplies present; disconnect signal harnesses before independently powering off/programming one domain. Configure radioCSN HIGH, CE LOW and IR_TX LOW before transmitting. Avoid unpowered devices being driven through GPIO protection paths.
9. The inline USB on/off switch controls only the external peripheral supply. It is not a deck-wide switch or Linux shutdown control. Coordinate ESP/peripheral power as above; shut down the Pi before removing its own power.
10. The external regulator nominal1A rating is not a verified load allowance. Measure the actual two PA/LNA radios, pulsed IR, rail droop and regulator temperature. The Miady bank total rating is shared by its ports; individual cables do not increase one bank total capacity.
11. All carrier electrical contacts are plated through holes. Assembled modules contain factory-soldered SMD components, with only through-hole headers/wires required for user assembly. Insulate and strain-relieve external supply wiring; verify polarity with a meter.
12. This audit verifies assignments and schematic connectivity, not physical fit, operating current, temperature or fabrication readiness. Native copper/DRC and actual hardware measurements are separate.

COMPONENT / PIN / NET TABLE — ALL ELECTRICAL PINS

A1 — ESP32-S3-AMOLED-1.91 [gged35c19f03e901e1f]
PIN	NAME	NET
1	3V3	ESP3V3
2	01	SDA_LV
3	02	NC (intentional)
4	03	NC (intentional)
5	10	RADIO1_CSN
6	11	RADIO_MOSI
7	12	RADIO_SCK
8	13	RADIO_MISO
9	14	RADIO1_CE
10	15	RADIO2_CSN
11	GND	GND
12	VSYS	NC (intentional)
13	VSYS	NC (intentional)
14	16	RADIO2_CE
15	39	IR_RX
16	3V3	NC (intentional)
17	3V3	ESP3V3
18	GND	GND
19	GND	NC (intentional)
20	40	IR_TX
21	41	SCL_LV
22	42	NC (intentional)
23	43	NC (intentional)
24	44	NC (intentional)
25	45	NC (intentional)
26	46	NC (intentional)
27	GND	NC (intentional)
28	GND	NC (intentional)

C1 — 100nF [ggeca4de4700ee065dc]
PIN	NAME	NET
1	1	3V3_AUX
2	2	GND

C2 — 100nF [ggee83d505374825c8b]
PIN	NAME	NET
1	1	3V3_AUX
2	2	GND

C3 — 10uF [ggecba382aa17f93048]
PIN	NAME	NET
1	1	3V3_AUX
2	2	GND

C4 — 10uF [gge207d32f59b0b0d8e]
PIN	NAME	NET
1	1	3V3_AUX
2	2	GND

C5 — 100nF [gge89af724020325cc6acc0]
PIN	NAME	NET
1	1	+5V_EXT
2	2	GND

C6 — 10uF [ggeb1c28745395c54d7b0cd]
PIN	NAME	NET
1	1	+5V_EXT
2	2	GND

C7 — 100nF [gge2c58aebafc1753b3b7ef]
PIN	NAME	NET
1	1	3V3_AUX
2	2	GND

C8 — 10uF [gge1a303ce317635af09187]
PIN	NAME	NET
1	1	3V3_AUX
2	2	GND

IC1 — NRF24L01 [ggeb1f7200842a9e1c9]
PIN	NAME	NET
1	GND	GND
2	VCC	3V3_AUX
3	CE	RADIO1_CE
4	CSN	RADIO1_CSN
5	SCK	RADIO_SCK
6	MOSI	RADIO_MOSI
7	MISO	RADIO_MISO
8	IRQ	NC (intentional)

IC2 — NRF24L01 [gge4fef22435443c364]
PIN	NAME	NET
1	GND	GND
2	VCC	3V3_AUX
3	CE	RADIO2_CE
4	CSN	RADIO2_CSN
5	SCK	RADIO_SCK
6	MOSI	RADIO_MOSI
7	MISO	RADIO_MISO
8	IRQ	NC (intentional)

JP1 — Adafruit 5990 IR RX/TX module [gge77ad37ec3d1c399b]
PIN	NAME	NET
1	IRout	IR_TX
2	IRin	IR_RX
3	GND	GND
4	VIN	3V3_AUX

JP2 — REGULATED POWER INPUT [ggeb6e5d994fcd05bd78aeb]
PIN	NAME	NET
1	+5V_EXT	+5V_EXT
2	GND	GND
3	3V3_AUX	3V3_AUX
4	GND	GND

JP3 — WIRED ADAFRUIT 757 I2C SHIFTER [gge61fb284b4615527dbd28d442]
PIN	NAME	NET
1	GND	GND
2	LV	ESP3V3
3	HV	+5V_EXT
4	A1 SDA	SDA_LV
5	B1 SDA	KB_SDA
6	A2 SCL	SCL_LV
7	B2 SCL	KB_SCL
8	GND	GND

JP8 — WIRED ADAFRUIT 5880 ENCODER [ggeaa561e8158e35e52a11fe8b1]
PIN	NAME	NET
1	GND	GND
2	3V3	ESP3V3
3	SDA	SDA_LV
4	SCL	SCL_LV

PI1 — Raspberry Pi Zero 2 W [gge97d7393dda2920b4]
PIN	NAME	NET
1	3V3	NC (intentional)
2	5V	NC (intentional)
3	GPIO2 sda	NC (intentional)
4	5V	NC (intentional)
5	GPIO3 scl	NC (intentional)
6	GND	NC (intentional)
7	GPIO4	NC (intentional)
8	tx GPIO14	NC (intentional)
9	GND	NC (intentional)
10	rx GPIO15	NC (intentional)
11	GPIO17	NC (intentional)
12	pwm0 GPIO18	NC (intentional)
13	GPIO27	NC (intentional)
14	GND	NC (intentional)
15	GPIO22	NC (intentional)
16	GPIO23	NC (intentional)
17	3V3	NC (intentional)
18	GPIO24	NC (intentional)
19	GPIO10 mosi	NC (intentional)
20	GND	NC (intentional)
21	GPIO9 miso	NC (intentional)
22	GPIO25	NC (intentional)
23	GPIO11 sck	NC (intentional)
24	cs0 GPIO8	NC (intentional)
25	GND	NC (intentional)
26	cs1 GPIO7	NC (intentional)
27	eeprom sda	NC (intentional)
28	eeprom scl	NC (intentional)
29	GPIO5	NC (intentional)
30	GND	NC (intentional)
31	GPIO6	NC (intentional)
32	pwm0 GPIO12	NC (intentional)
33	GPIO13 pwm1	NC (intentional)
34	GND	NC (intentional)
35	GPIO19 pwm1	NC (intentional)
36	GPIO16	NC (intentional)
37	GPIO26	NC (intentional)
38	GPIO20	NC (intentional)
39	GND	NC (intentional)
40	GPIO21	NC (intentional)

R1 — 10k [gge30020]
PIN	NAME	NET
1	1	RADIO1_CSN
2	2	3V3_AUX

R2 — 10k [gge30030]
PIN	NAME	NET
1	1	RADIO1_CE
2	2	GND

R3 — 10k [gge30040]
PIN	NAME	NET
1	1	RADIO2_CSN
2	2	3V3_AUX

R4 — 10k [gge30050]
PIN	NAME	NET
1	1	RADIO2_CE
2	2	GND

U1 — CardKB Module [gge51eda74d3f7c17e6]
PIN	NAME	NET
1	GND	GND
2	VCC	+5V_EXT
3	SDA	KB_SDA
4	SCL	KB_SCL

NET MEMBERSHIP
+5V_EXT: C5.1 (1), C6.1 (1), JP2.1 (+5V_EXT), JP3.3 (HV), U1.2 (VCC)
3V3_AUX: C1.1 (1), C2.1 (1), C3.1 (1), C4.1 (1), C7.1 (1), C8.1 (1), IC1.2 (VCC), IC2.2 (VCC), JP1.4 (VIN), JP2.3 (3V3_AUX), R1.2 (2), R3.2 (2)
ESP3V3: A1.1 (3V3), A1.17 (3V3), JP3.2 (LV), JP8.2 (3V3)
GND: A1.11 (GND), A1.18 (GND), C1.2 (2), C2.2 (2), C3.2 (2), C4.2 (2), C5.2 (2), C6.2 (2), C7.2 (2), C8.2 (2), IC1.1 (GND), IC2.1 (GND), JP1.3 (GND), JP2.2 (GND), JP2.4 (GND), JP3.1 (GND), JP3.8 (GND), JP8.1 (GND), R2.2 (2), R4.2 (2), U1.1 (GND)
IR_RX: A1.15 (39), JP1.2 (IRin)
IR_TX: A1.20 (40), JP1.1 (IRout)
KB_SCL: JP3.7 (B2 SCL), U1.4 (SCL)
KB_SDA: JP3.5 (B1 SDA), U1.3 (SDA)
RADIO1_CE: A1.9 (14), IC1.3 (CE), R2.1 (1)
RADIO1_CSN: A1.5 (10), IC1.4 (CSN), R1.1 (1)
RADIO2_CE: A1.14 (16), IC2.3 (CE), R4.1 (1)
RADIO2_CSN: A1.10 (15), IC2.4 (CSN), R3.1 (1)
RADIO_MISO: A1.8 (13), IC1.7 (MISO), IC2.7 (MISO)
RADIO_MOSI: A1.6 (11), IC1.6 (MOSI), IC2.6 (MOSI)
RADIO_SCK: A1.7 (12), IC1.5 (SCK), IC2.5 (SCK)
SCL_LV: A1.21 (41), JP3.6 (A2 SCL), JP8.4 (SCL)
SDA_LV: A1.2 (01), JP3.4 (A1 SDA), JP8.3 (SDA)

INTENTIONALLY UNCONNECTED PINS
A1.3 (02), A1.4 (03), A1.12 (VSYS), A1.13 (VSYS), A1.16 (3V3), A1.19 (GND), A1.22 (42), A1.23 (43), A1.24 (44), A1.25 (45), A1.26 (46), A1.27 (GND), A1.28 (GND), IC1.8 (IRQ), IC2.8 (IRQ), PI1.1 (3V3), PI1.2 (5V), PI1.3 (GPIO2 sda), PI1.4 (5V), PI1.5 (GPIO3 scl), PI1.6 (GND), PI1.7 (GPIO4), PI1.8 (tx GPIO14), PI1.9 (GND), PI1.10 (rx GPIO15), PI1.11 (GPIO17), PI1.12 (pwm0 GPIO18), PI1.13 (GPIO27), PI1.14 (GND), PI1.15 (GPIO22), PI1.16 (GPIO23), PI1.17 (3V3), PI1.18 (GPIO24), PI1.19 (GPIO10 mosi), PI1.20 (GND), PI1.21 (GPIO9 miso), PI1.22 (GPIO25), PI1.23 (GPIO11 sck), PI1.24 (cs0 GPIO8), PI1.25 (GND), PI1.26 (cs1 GPIO7), PI1.27 (eeprom sda), PI1.28 (eeprom scl), PI1.29 (GPIO5), PI1.30 (GND), PI1.31 (GPIO6), PI1.32 (pwm0 GPIO12), PI1.33 (GPIO13 pwm1), PI1.34 (GND), PI1.35 (GPIO19 pwm1), PI1.36 (GPIO16), PI1.37 (GPIO26), PI1.38 (GPIO20), PI1.39 (GND), PI1.40 (GPIO21)

VERIFICATION SCOPE
All component identities and schematic pin names/IDs, wire-and-label graph nets, explicit NC marks, PCB electrical pad assignments and four Pi mechanical pads. Copper geometry, continuity, native DRC, UI save state, thermal performance and mechanical fit are separate checks.

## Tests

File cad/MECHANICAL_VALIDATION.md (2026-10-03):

# Mechanical design and validation plan

This is the first editable enclosure design for the current 190 x 110 mm carrier PCB. The matching model is `Cyberdeck_Enclosure.scad`. It produces a removable service tray, base, lid, keyboard frame, ESP32 cradle, Chameleon sled, generic antenna pivot and battery hook. All dimensions are millimetres.

## Confirmed source dimensions

| Item | Design envelope | Evidence | Status |
| --- | --- | --- | --- |
| Carrier PCB | 190 x 110 x 1.6 | Current native PCB and full-size template | Verified digitally |
| Carrier mount holes | 20 holes; 16 carrier plus four Pi holes | Current template audit | Verified digitally |
| HAT | 65 x 30, four 3 mm holes at 58 x 23 | Waveshare USB HUB HAT SKU12694 drawing | Verified from drawing |
| HAT header cutout | 51.8 x 8, R1 | Current PCB/template | Verified digitally; physical header still required |
| CardKB | reserve 88 x 54 x 6.3 | M5Stack drawing/product page conflict | Reserve only |
| Pi Zero 2 | 65 x 30 body, exact carrier holes | Pi drawing/current PCB | Hole pattern verified digitally |
| LILYGO | 60 x 25.5 x 10, active screen 19.8 x 44.22 | LILYGO basic AMOLED documentation | The photo identifies the basic/no-touch type; rev V1 vs V2 still needs a physical check |
| HDMI LCD | 85.01 x 56.41 board | Waveshare SKU12824 drawing | Panel aperture and plug depth need physical check |
| Miady bank | 96 x 64 x 26 maximum envelope | AS-TPB21 manual | Confirm against the bank in hand |
| Chameleon Ultra SE3 | 40 x 24 x 8 adjustable envelope | supplier references, not an official dimensional drawing | Must measure before printing |

## Current fit conclusion

The service tray holds the carrier PCB on 5 mm M2.5 standoffs. The HAT is mounted on the carrier's four dedicated holes with a 1 mm separator and its underside header passes through both the carrier slot and tray clearance. The base reserves 39.6 mm from the tray top to the keyboard-frame plane.

The HAT uses almost the full available plan area underneath the CardKB. The Chameleon cannot be mounted beside the HAT at the same height. The model puts it in a separate under-tray sled with a thin plastic RF window. This arrangement must be range-tested because nearby copper, battery material and the case can reduce RFID performance.

The base remains parametric because the following cannot be established from product drawings: mated HDMI/USB connector depth, USB cable bend radius, actual power-bank dimensions, Chameleon dimensions, antenna pigtail/bulkhead shape and the card keyboard's real screw positions.

## Physical measurement checklist

Print the existing mounting template at actual size first. Confirm its 100 mm calibration line before placing hardware on it.

| Check | Pass criterion | Action if it fails |
| --- | --- | --- |
| PCB, Pi, HAT and carrier mounts | Every hole accepts a screw without forcing | Correct the CAD mount coordinates, never enlarge the PCB holes by drilling blindly |
| HAT underside header | Header clears 51.8 x 8 mm slot with at least 0.5 mm around it | Increase the tray-only cutout first; alter PCB only after a separate electrical/copper audit |
| Pi-HAT cable | Micro-USB plug clears the keyboard and has no sharp bend | Rotate the HAT or change to a short right-angle data cable |
| HAT plus keyboard | Keyboard closes without touching hub plugs, header or standoffs | Increase `base_h` before printing the final base |
| Chameleon sled | Device slides in, buttons/USB remain reachable, and tags work through the RF window | Resize its adjustable rails or move it to a front service bay |
| LCD | Board clips in without force; HDMI and power plugs bend naturally | Change `lcd_xy`, lid cavity depth or cable exit channel |
| LILYGO | USB-C, BOOT and RESET remain reachable; screen aligns to the closed-lid window | Change `lily_xy` and `lily_window` in the model |
| Hinge/lid | Opens to at least 105 degrees, closes without cable pinch | Adjust hinge ears and the rear cable channel |
| Antennas | Folded arms clear the lid, battery and hands | Choose actual RF pigtails and finalise the arm length/clevis geometry |
| Screw heads | No metal fastener touches carrier copper | Use the required insulating washers and recheck clearance |

## Print order

1. Print only the HAT-slot and keyboard/HAT section as a low-infill test slice.
2. Place the HAT, its data cable and keyboard on the test slice. Confirm height before printing the full base.
3. Print the service tray. Test every carrier, Pi and HAT screw location with nylon M2.5 hardware.
4. Print the keyboard frame and ESP32 cradle. Neither assumes a direct mounting hole in the module.
5. Print the lid and check the display and LILYGO window using paper cutouts before installing electronics.
6. Print antenna pivots only after selecting the actual RP-SMA/SMA bulkhead pigtails.

## Operating access designed into the enclosure

- The removable underside service tray gives access to the Pi boot card, USB leads, HAT, Chameleon, level shifter and regulator without disassembling the lid.
- The ESP32 cradle leaves its USB-C and BOOT/RESET end open. Its lid window remains visible when closed.
- The right-front panel provides the encoder hole and peripheral-supply switch opening.
- The left side has a wired IR opening.
- Rear and right cable exits are oversized provisional channels. They need to be finalised using real plugs and strain-relief grommets.
- The lid has a display cavity with edge clips rather than guessed LCD mounting holes.

## Explicit limits

This is a design package, not proof of physical fit. Do not send the PCB, enclosure or final fabrication files for manufacture until the checklist has been completed with the actual parts. In particular, do not use a metal screw head directly against the carrier PCB and do not permanently install the Chameleon before testing its RFID range in the proposed bay.

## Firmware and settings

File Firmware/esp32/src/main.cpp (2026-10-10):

#include <Arduino.h>
#include <SPI.h>
#include <RF24.h>
#include <IRremote.hpp>

#include "cyberdeck_pins.h"

// This firmware is deliberately a bring-up scaffold. It provides one serial
// protocol for the Pi and starts every peripheral in a safe idle state.
// Do not connect or power a signal harness while its source rail is off.

using namespace CyberdeckPins;

RF24 radio1(RADIO1_CE, RADIO1_CSN);
RF24 radio2(RADIO2_CE, RADIO2_CSN);
const uint8_t RADIO1_ADDRESS[6] = "CDR1";
const uint8_t RADIO2_ADDRESS[6] = "CDR2";
bool radio1Ready = false;
bool radio2Ready = false;
bool encoderReady = true;
int32_t encoderPosition = 0;
uint8_t encoderAB = 0;
bool lastButtonPressed = false;
unsigned long lastButtonEventMs = 0;

struct ButtonState {
  int pin;
  const char *name;
  bool lastPressed;
  unsigned long lastChangeMs;
};
ButtonState buttons[] = {
    {BUTTON_BACK, "back", false, 0},
    {BUTTON_MENU, "menu", false, 0},
    {BUTTON_UP, "up", false, 0},
    {BUTTON_DOWN, "down", false, 0},
};

char commandBuffer[128];
size_t commandLength = 0;
unsigned long lastScanMs = 0;

void event(const char *type, const char *detail) {
  Serial.printf("{\"type\":\"%s\",\"detail\":\"%s\"}\n", type, detail);
}

void eventNumber(const char *type, int32_t value) {
  Serial.printf("{\"type\":\"%s\",\"value\":%ld}\n", type, static_cast<long>(value));
}

bool configureRadio(RF24 &radio, const uint8_t *address, const char *name) {
  if (!radio.begin(&SPI)) {
    event("radio_error", name);
    return false;
  }
  radio.setPALevel(RF24_PA_MIN);       // Begin at the lowest transmit power.
  radio.setDataRate(RF24_1MBPS);
  radio.setChannel(76);
  radio.setRetries(5, 15);
  radio.openWritingPipe(address);
  radio.openReadingPipe(1, address);
  radio.startListening();
  event("radio_ready", name);
  return true;
}

void sendRadio(RF24 &radio, bool ready, const char *name, const char *payload) {
  if (!ready) {
    event("radio_error", "not_ready");
    return;
  }
  char packet[32] = {};
  strncpy(packet, payload, sizeof(packet) - 1);
  radio.stopListening();
  const bool sent = radio.write(packet, sizeof(packet));
  radio.startListening();
  event(sent ? "radio_sent" : "radio_failed", name);
}

void pollRadio(RF24 &radio, bool ready, const char *name) {
  if (!ready || !radio.available()) return;
  char packet[32] = {};
  radio.read(packet, sizeof(packet));
  Serial.printf("{\"type\":\"radio_rx\",\"radio\":\"%s\",\"payload\":\"%s\"}\n", name, packet);
}

void pollEncoder() {
  // Mechanical quadrature encoder with common pin grounded. INPUT_PULLUP
  // supplies the idle-high level; no external pull-up resistors are needed.
  static const int8_t transitions[16] = {
     0, -1,  1,  0,
     1,  0,  0, -1,
    -1,  0,  0,  1,
     0,  1, -1,  0
  };
  const uint8_t currentAB = (digitalRead(ENCODER_A) << 1) | digitalRead(ENCODER_B);
  const uint8_t index = (encoderAB << 2) | currentAB;
  const int8_t step = transitions[index];
  encoderAB = currentAB;
  if (step != 0) {
    encoderPosition += step;
    eventNumber("encoder_delta", step);
  }

  const bool pressed = digitalRead(ENCODER_BUTTON) == LOW;
  const unsigned long now = millis();
  if (pressed && !lastButtonPressed && now - lastButtonEventMs >= 35) {
    event("button", "select");
    lastButtonEventMs = now;
  }
  lastButtonPressed = pressed;
}

void pollNavigationButtons() {
  const unsigned long now = millis();
  for (auto &button : buttons) {
    const bool pressed = digitalRead(button.pin) == LOW;
    if (pressed != button.lastPressed && now - button.lastChangeMs >= 25) {
      button.lastPressed = pressed;
      button.lastChangeMs = now;
      if (pressed) event("button", button.name);
    }
  }
}

void pollIrReceiver() {
  if (!IrReceiver.decode()) return;
  Serial.printf("{\"type\":\"ir_rx\",\"protocol\":%u,\"address\":%u,\"command\":%u}\n",
                static_cast<unsigned>(IrReceiver.decodedIRData.protocol),
                static_cast<unsigned>(IrReceiver.decodedIRData.address),
                static_cast<unsigned>(IrReceiver.decodedIRData.command));
  IrReceiver.resume();
}

void reportStatus() {
  Serial.printf("{\"type\":\"status\",\"radio1\":%s,\"radio2\":%s,\"encoder\":%s}\n",
                radio1Ready ? "true" : "false", radio2Ready ? "true" : "false",
                encoderReady ? "true" : "false");
}

void handleCommand(const char *command) {
  if (strcmp(command, "PING") == 0) {
    event("pong", "cyberdeck");
  } else if (strcmp(command, "STATUS") == 0) {
    reportStatus();
  } else if (strncmp(command, "RADIO1:", 7) == 0) {
    sendRadio(radio1, radio1Ready, "radio1", command + 7);
  } else if (strncmp(command, "RADIO2:", 7) == 0) {
    sendRadio(radio2, radio2Ready, "radio2", command + 7);
  } else if (strncmp(command, "IR_NEC:", 7) == 0) {
    // Format: IR_NEC:ADDRESS:COMMAND, both hexadecimal, for example IR_NEC:00FF:12ED.
    unsigned int address = 0;
    unsigned int irCommand = 0;
    if (sscanf(command + 7, "%x:%x", &address, &irCommand) == 2) {
      IrSender.sendNEC(address, irCommand, 0);
      event("ir_sent", "nec");
    } else {
      event("command_error", "bad_ir_nec");
    }
  } else {
    event("command_error", "unknown");
  }
}

void pollUsbSerial() {
  while (Serial.available()) {
    const char c = static_cast<char>(Serial.read());
    if (c == '\r') continue;
    if (c == '\n') {
      commandBuffer[commandLength] = '\0';
      if (commandLength > 0) handleCommand(commandBuffer);
      commandLength = 0;
    } else if (commandLength < sizeof(commandBuffer) - 1) {
      commandBuffer[commandLength++] = c;
    } else {
      commandLength = 0;
      event("command_error", "too_long");
    }
  }
}

void setup() {
  Serial.begin(115200);
  delay(250);
  event("boot", "cyberdeck_esp32");

  pinMode(ENCODER_A, INPUT_PULLUP);
  pinMode(ENCODER_B, INPUT_PULLUP);
  pinMode(ENCODER_BUTTON, INPUT_PULLUP);
  for (auto &button : buttons) pinMode(button.pin, INPUT_PULLUP);
  encoderAB = (digitalRead(ENCODER_A) << 1) | digitalRead(ENCODER_B);
  SPI.begin(RADIO_SCK, RADIO_MISO, RADIO_MOSI, RADIO1_CSN);
  radio1Ready = configureRadio(radio1, RADIO1_ADDRESS, "radio1");
  radio2Ready = configureRadio(radio2, RADIO2_ADDRESS, "radio2");

  event("encoder_ready", "gpio1_gpio2_button42_pullups");
  event("buttons_ready", "up41_down46_back43_menu44_select42_pullups");

  IrReceiver.begin(IR_RX, DISABLE_LED_FEEDBACK);
  IrSender.begin(IR_TX, DISABLE_LED_FEEDBACK);
  event("ir_ready", "rx39_tx40");
  reportStatus();
}

void loop() {
  pollUsbSerial();
  pollEncoder();
  pollNavigationButtons();
  pollIrReceiver();
  pollRadio(radio1, radio1Ready, "radio1");
  pollRadio(radio2, radio2Ready, "radio2");

  if (millis() - lastScanMs >= 5000) {
    lastScanMs = millis();
    reportStatus();
  }
}

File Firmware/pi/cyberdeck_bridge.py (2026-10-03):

#!/usr/bin/env python3
"""USB-serial bridge between the Raspberry Pi and the Cyberdeck ESP32.

Run this after the ESP32 has been flashed and connected by an intact USB data
cable. It prints CardKB, encoder, radio and IR events as JSON and accepts
commands on stdin. This is a bring-up program, not an installed service.
"""

import argparse
import json
import queue
import sys
import threading
import serial


def serial_reader(port: serial.Serial, events: queue.Queue[str]) -> None:
    while True:
        try:
            line = port.readline().decode("utf-8", errors="replace").strip()
        except serial.SerialException as exc:
            events.put(json.dumps({"type": "serial_error", "detail": str(exc)}))
            return
        if line:
            events.put(line)


def keyboard_reader(commands: queue.Queue[str]) -> None:
    for line in sys.stdin:
        command = line.strip()
        if command:
            commands.put(command)


def main() -> int:
    parser = argparse.ArgumentParser(description="Cyberdeck ESP32 USB bridge")
    parser.add_argument("--port", default="/dev/ttyACM0", help="ESP32 USB serial device")
    parser.add_argument("--baud", type=int, default=115200)
    args = parser.parse_args()

    try:
        port = serial.Serial(args.port, args.baud, timeout=0.2)
    except serial.SerialException as exc:
        print(f"Cannot open {args.port}: {exc}", file=sys.stderr)
        return 2

    events: queue.Queue[str] = queue.Queue()
    commands: queue.Queue[str] = queue.Queue()
    threading.Thread(target=serial_reader, args=(port, events), daemon=True).start()
    threading.Thread(target=keyboard_reader, args=(commands,), daemon=True).start()

    print("Cyberdeck bridge ready. Commands: PING, STATUS, RADIO1:text, RADIO2:text, IR_NEC:00FF:12ED")
    port.write(b"STATUS\n")

    while True:
        try:
            command = commands.get_nowait()
            port.write((command + "\n").encode("utf-8"))
        except queue.Empty:
            pass

        try:
            raw = events.get(timeout=0.1)
        except queue.Empty:
            continue
        try:
            event = json.loads(raw)
        except json.JSONDecodeError:
            print(json.dumps({"type": "unparsed", "raw": raw}))
            continue
        print(json.dumps(event, sort_keys=True))


if __name__ == "__main__":
    try:
        raise SystemExit(main())
    except KeyboardInterrupt:
        print("\nCyberdeck bridge stopped")

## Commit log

2026-10-03 Add cyberdeck CAD PCB BOM and firmware scaffold
    [BOM-source.xlsx, BOM.csv, Cyberdeck_Enclosure.scad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]
2026-10-03 Add PCB screenshots and correct Chameleon BOM status
    [BOM.csv]
2026-10-10 Document NEONRED radio expansion and current goal
    [BOM.csv, BOM_NEONRED_purchase-list_2026-10-06.csv]
2026-10-12 Document NEONRED PCB cleanup and remaining checks
2026-10-17 Update NEONRED BOM and project files
2026-10-18 Fix PCB button labels and silkscreen overlap
2026-10-19 Prepare NEONRED bare PCB order package
2026-10-19 Add case mounting ears to NEONRED PCB
2026-10-19 Update case CAD supports and current PCB BOM
2026-10-19 Update PCB mounts, Gerbers, and STEP CAD
2026-10-19 Remove duplicate PCB snapshots
2026-10-19 Remove Proxmark materials from project
2026-10-19 Consolidate project BOM and remove superseded files
2026-10-20 Clean repository and publish current PCB artifacts
2026-10-20 Add RTL-SDR and antenna items to BOM
2026-10-20 Update ESP32 and compact SDR antennas
2026-11-04 Remove Miady USB power bank from BOM
    Removed Miady 10,000 mAh USB power bank from BOM.
